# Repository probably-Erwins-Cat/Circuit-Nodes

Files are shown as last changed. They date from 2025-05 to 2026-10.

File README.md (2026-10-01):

# Circuit Nodes - Modular Electronics Building Blocks

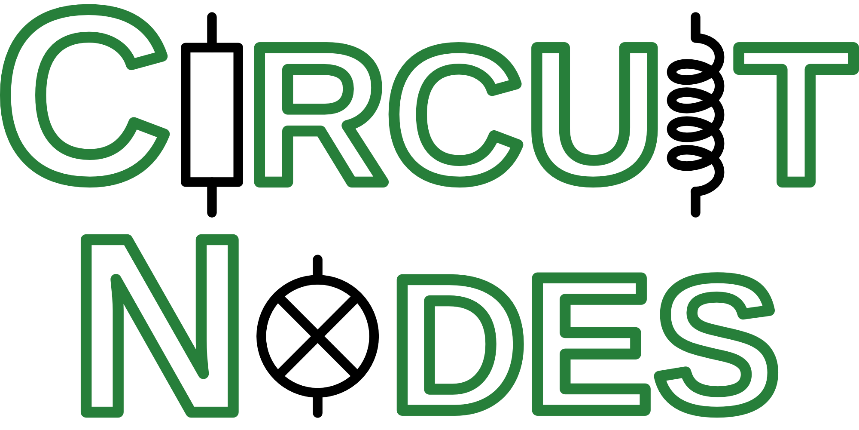
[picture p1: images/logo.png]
Circuit Diagram


Circuit Nodes is an educational tool shared under CC BY-NC-SA 4.0 to help students understand electronic circuits by physically building them.
Each module consists of a small PCB mounted on a 3D-printed base with puzzle-like notches, allowing users to create circuits in a grid-based structure. 
The PCBs include simple circuit elements such as resistors, capacitors, wire traces, switches, LEDs, lamps, and voltage or current measurement points, with their schematic representations printed directly on them. 
Magnetic connectors enable both physical attachment and electrical connection.

This system provides a low-cost entry point into electronics education while remaining scalable. 
By starting with basic components and expanding into more complex circuits, learners of all levels can benefit. 
The pedagogical value lies in reinforcing the connection between abstract circuit diagrams and tangible, working implementations, 
making theoretical concepts easier to grasp through hands-on experimentation.

---

## 📖 **[→ EXPLORE THE FULL DOCUMENTATION](https://probably-erwins-cat.github.io/Circuit-Nodes/)**

Complete guides, examples, research insights, and best practices are available in our **comprehensive GitHub Pages site**:

| Chapter | Link |
|---|---|
| **Introduction** | https://probably-erwins-cat.github.io/Circuit-Nodes/introduction |
| **Getting Started** | https://probably-erwins-cat.github.io/Circuit-Nodes/getting-started |
| **Printable Bases** | https://probably-erwins-cat.github.io/Circuit-Nodes/printable-bases |
| **Assembly Instructions** | https://probably-erwins-cat.github.io/Circuit-Nodes/assembly-instructions |
| **Component Guide** | https://probably-erwins-cat.github.io/Circuit-Nodes/component-guide |
| **Sourcing & Manufacturing** | https://probably-erwins-cat.github.io/Circuit-Nodes/sourcing-manufacturing |
| **Getting Started** | https://probably-erwins-cat.github.io/Circuit-Nodes/getting-started |

# Features

*If you are an educator or represent a school interested in testing Circuit
Nodes, I can provide kits for evaluation and classroom use. Please reach out for
more details, see below*

-   Modular Design: 40x40mm PCBs mounted on 3D-printed bases with interlocking
    puzzle-like edges.
-   Hands-on Learning: Users assemble working circuits based on schematic
    diagrams.
-   Magnetic Connectors: Ensure secure physical and electrical connections.
-   Visual Representation: Each PCB features the corresponding circuit schematic
    for intuitive learning.
-   Expandable: Additional modules with more components can be designed and
    added.
-   Low Cost & Scalable: An affordable introduction to electronics that can be
    expanded as needed.

-   Pre-Assembled Kits Available: If the initial effort of manufacturing and
    assembling the components seems too high, I can provide ready-made circuit
    kits to make getting started easier.

# Getting Started, Assembly Instructions

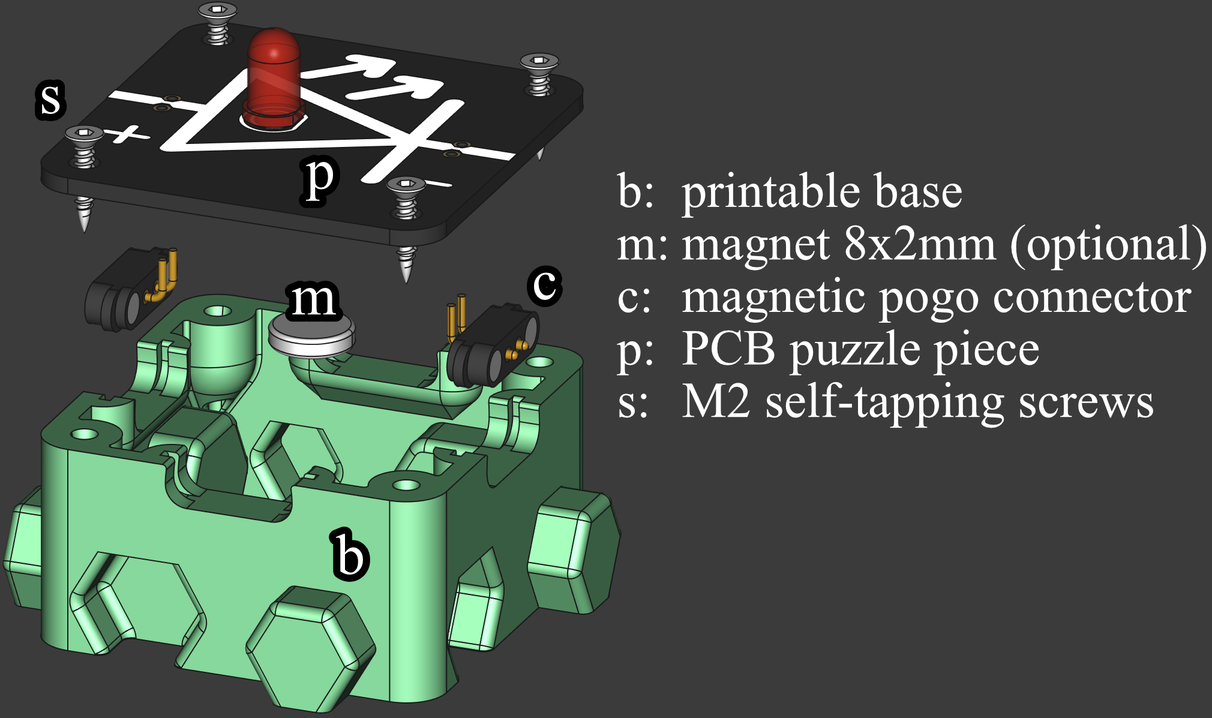
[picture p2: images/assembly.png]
assembly


- Refer to the repository contents below for a dedicated list and example circuits. 
- Plan what puzzle pieces you need and how many. An entry electronics kit for school settings needs less than 40 to cover most grounds.
- Download the necessary Gerber files for the circuits or kits you want to build from this repository.
- Manufacture the PCBs using your preferred(accessible) PCB fabrication service. 
  - Talk to the manufacturer if they can provide discounts for educational purpose. 
  - I recommend black background/solder mask and white silkscreen print. From my experience, this combination is the most durable combination.

-   **Decide which style of the 3D printable base you prefer for your scenario**:
    -  PCBs support screws of size M2, M2.3, and M2.6 self-tapping, as well as M2, M2.5 and M3 normal screws in combination with heat inserts.
        -   *Self-Tapping*: I recommend **M2 self-tapping and countersunk**
            screws. They provide the cleanest look, do not require additional
            assembly steps and auto-align the PCBs.
            Self-tapping screws, **can carve multiple threads when reinserting**, limited number of reuse of printable base.
        -   *Heat insert version*: Heat inserts provide **more durable and reliable way** for normal M2 and M2.5, 
            but requires time-consuming melting in the heat inserts with a solder iron or heat insert press.
    -   **Base Bottom Style**:
        -   The *magnetic bottom* base has highest build plate adhesion and allows for installing neodymium magnet, 
            so that the part can be attached to a magnetic surface. The internal height for components will be reduced by approx 3mm down to approx 16mm.
            **This makes a good teacher set for blackboards and whiteboards**
        -   The *skeletonized* one allows to look inside, but prevents curious
            fingers to get inside to accidentally break parts but allows exploring how
            components look in real life.
        -   The *open bottom* uses the least amount of material, is the fastest to
            print and, in case of a damaged component, the bottom side can be
            reached with a solder iron for *repair without disassembly*.            

-   **Before you go mass printing the base parts**, check which tolerance class,
    0.15mm and 0.2mm, suits your printer capabilities. 
    - The puzzle pieces should fit in together without a lot of wiggle room and without a lot of friction.
    - Smallest tolerance is preferred for best alignment of the parts.
-   Solder the component of the schematic of the PCB onto it first.
-   Assemble the puzzle pieces by placing the magnetic connectors in the pockets
    for the dedicated PCBs first. Slots without electrical connection stay     empty.
-   Place the PCB on top of the pins of the magnetic connectors and screw in
    four screws into the base. Screws should auto-center the PCB on the base.
-   Solder the magnetic connectors to the PCB.
-   Start building and experimenting with different circuit configurations!

You can also contact me for production and sale, I stock the puzzle pieces in my inventory and do quality checks including all other parts for assembly.

# Contributing

Contributions are welcome! Feel free to submit pull requests with new module
designs, improvements, or documentation updates. If you are a teacher and would
like to see specific schematics that align with your curriculum, but lack the
KiCAD skills to design them, I am happy to assist with the schematic design
process. Just reach out with your requirements, and I can help bring them to
life for your students.

Before submitting files, read [CONTRIBUTING.md](CONTRIBUTING.md). It explains
how contributed designs remain available for future Circuit Nodes kits while
contributors keep ownership of their work.

# Contact

For questions or collaboration, please open an discussion or reach out to me.

# DOI



# License

Circuit Nodes material is offered under **CC BY-NC-SA 4.0** (Creative Commons
Attribution-NonCommercial-ShareAlike 4.0 International) where the project holds
the necessary rights. You may use the design files to make your own Circuit
Nodes for noncommercial purposes. Schools may be able to commission ordinary
fabrication and assembly services for that use. The public license does not
permit use of licensed material primarily for commercial advantage. The project
creator retains the right to manufacture and sell products based on material
for which they hold the necessary rights. See
[LICENSING.md](LICENSING.md) for scope and
[LICENSE](LICENSE) for the full license.

---

## 📚 Citation & Research

This project is supported by peer-reviewed research published in **Physics Education**:

**Kubitschke, H., Hennig, F., Gleichmann, J., Schnauß, J., & Bitzenbauer, P. (2024).** 
*Modular 3D-printed Circuit Nodes for low-cost and hands-on Electricity Education.* 
Physics Education, 61(1), 015010.
**DOI**: [10.1088/1361-6552/ae1abd](https://doi.org/10.1088/1361-6552/ae1abd)

The paper includes:
- Educational design principles and cognitive load theory
- Technical specifications and cost analysis
- Teacher evaluation and feedback from 8 German secondary school physics teachers
- Learning outcome research and student perception studies

[Read the research publication](https://doi.org/10.1088/1361-6552/ae1abd) for detailed insights.

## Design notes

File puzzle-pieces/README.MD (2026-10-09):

# Circuit Nodes Puzzle Pieces

All Circuit Nodes puzzle pieces are collected and constantly updated here. Each piece represents a specific circuit component or connection type, named according to their schematic symbols rather than specific component numbers. For example, the folder for an n-channel MOSFET will contain compatible part numbers like the 2N7000.

## Design Standard

All puzzle pieces follow a consistent design template to ensure they work together seamlessly:

- **Physical dimensions**: 40×40 mm square outline with 4 mm radius corners
- **Mounting**: Four M3-compatible screw holes in the corners (2.9–3.0 mm diameter, 4 mm from edges)
- **Visual style**: 2 mm thick pictogram lines with rounded edges where possible
- **Electrical layout**: Copper pour kept at least 2 mm from board edges and not connected to GND or power supply
- **Connector interface**: Integrated magnetic pogo connectors (see the dedicated pogo-connector folder)

## Board-to-Board Connectors

All pieces are designed for integrated magnetic pogo connectors. The layout and spacing of each puzzle piece are carefully matched to these connectors for reliable, automatic alignment when pieces are joined.

## Complete Catalog

| Name | Image |
|---|---|
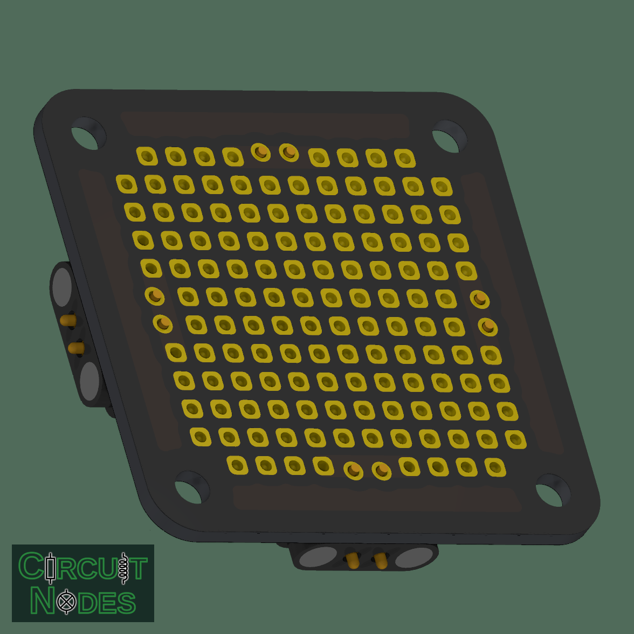
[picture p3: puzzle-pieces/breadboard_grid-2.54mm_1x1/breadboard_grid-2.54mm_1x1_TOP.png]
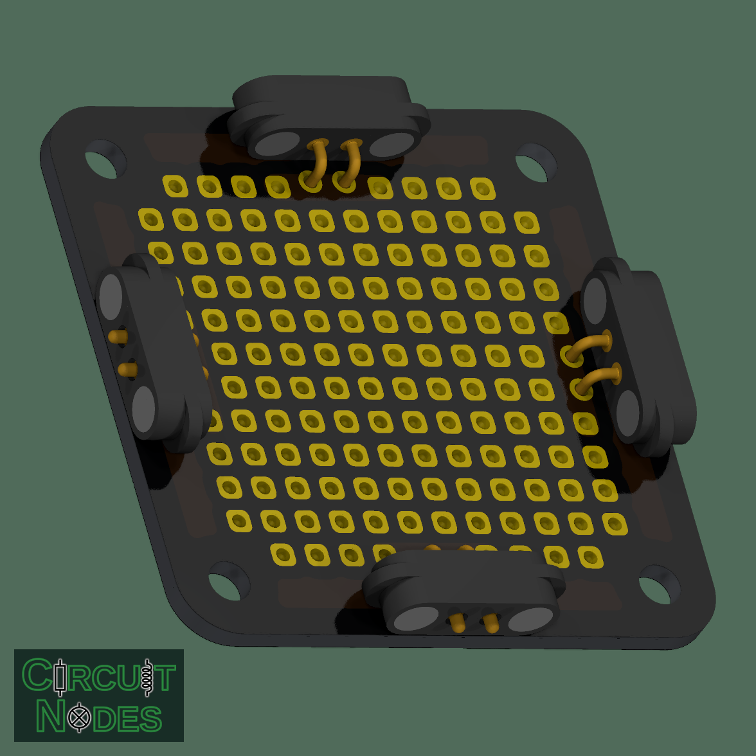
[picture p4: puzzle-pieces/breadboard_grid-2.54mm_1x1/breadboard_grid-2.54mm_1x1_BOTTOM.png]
| [breadboard_grid-2.54mm_1x1](breadboard_grid-2.54mm_1x1) |  |
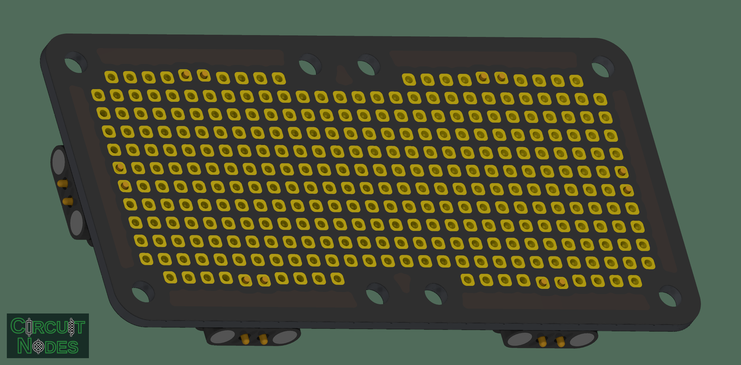
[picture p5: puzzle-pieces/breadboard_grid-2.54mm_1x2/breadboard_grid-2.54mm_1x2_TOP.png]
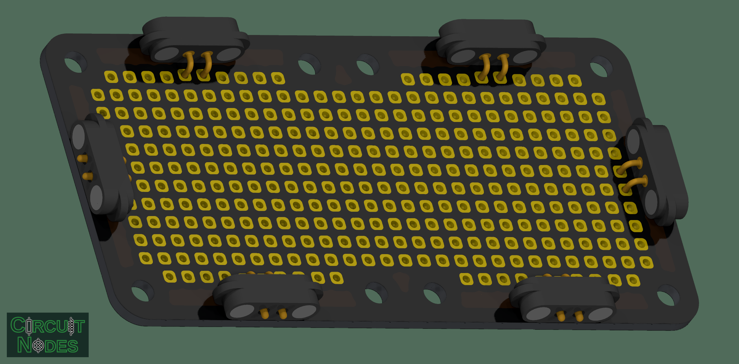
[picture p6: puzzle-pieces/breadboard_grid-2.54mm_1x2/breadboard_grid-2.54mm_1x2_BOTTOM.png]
| [breadboard_grid-2.54mm_1x2](breadboard_grid-2.54mm_1x2) |  |
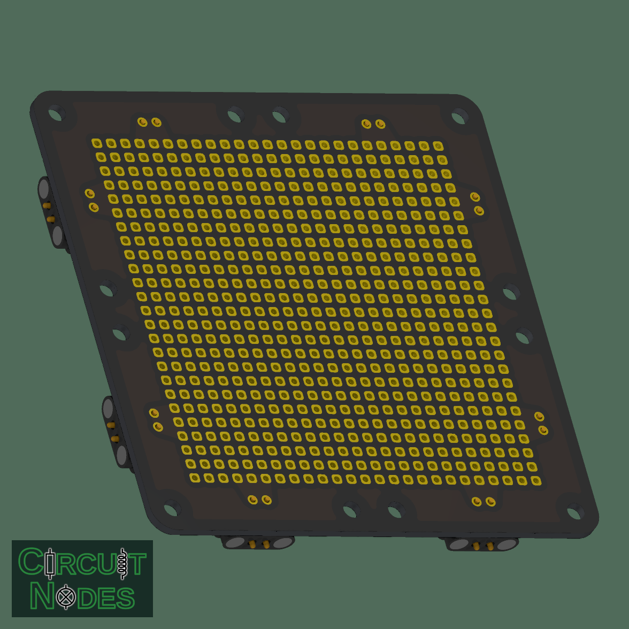
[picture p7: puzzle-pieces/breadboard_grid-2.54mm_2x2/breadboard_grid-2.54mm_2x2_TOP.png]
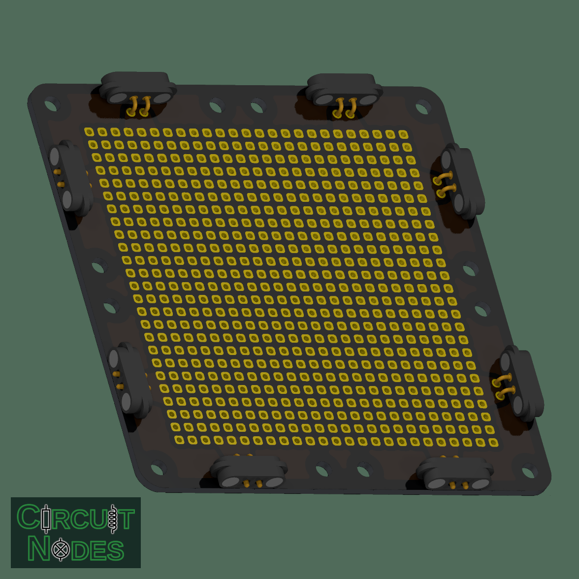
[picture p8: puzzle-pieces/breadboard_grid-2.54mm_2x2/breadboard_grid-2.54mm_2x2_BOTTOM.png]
| [breadboard_grid-2.54mm_2x2](breadboard_grid-2.54mm_2x2) |  |
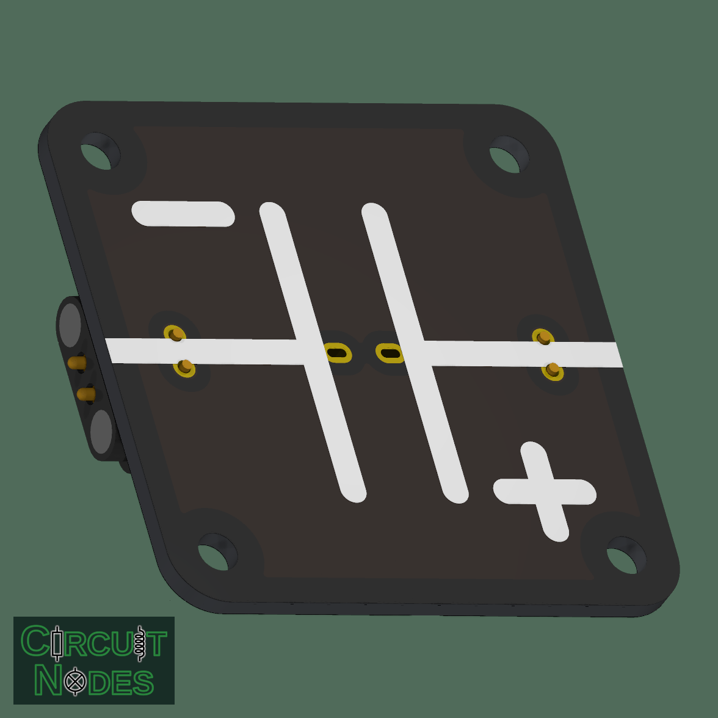
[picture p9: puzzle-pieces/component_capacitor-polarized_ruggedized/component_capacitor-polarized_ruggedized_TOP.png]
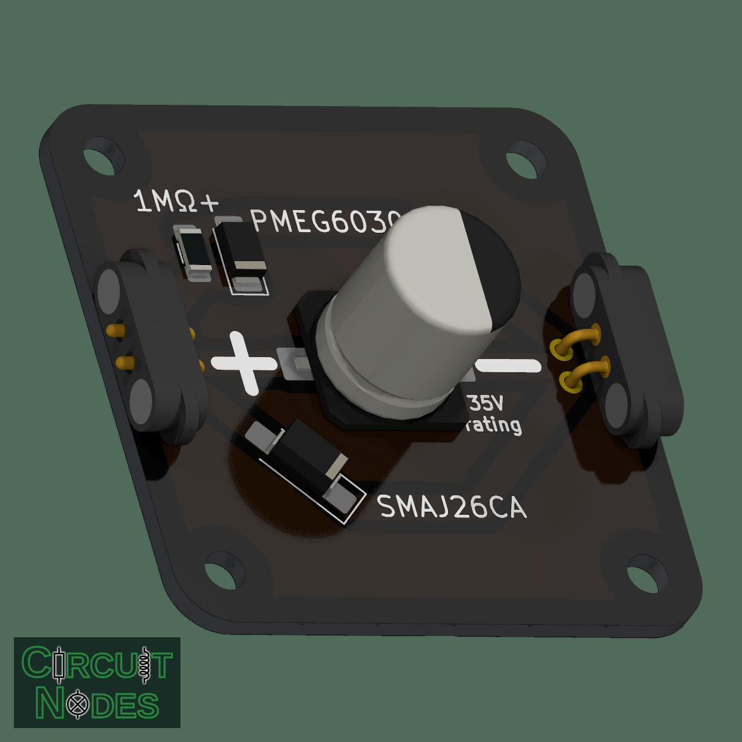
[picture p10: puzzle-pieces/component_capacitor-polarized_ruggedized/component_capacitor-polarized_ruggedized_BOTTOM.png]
| [component_capacitor-polarized_ruggedized](component_capacitor-polarized_ruggedized) |  |
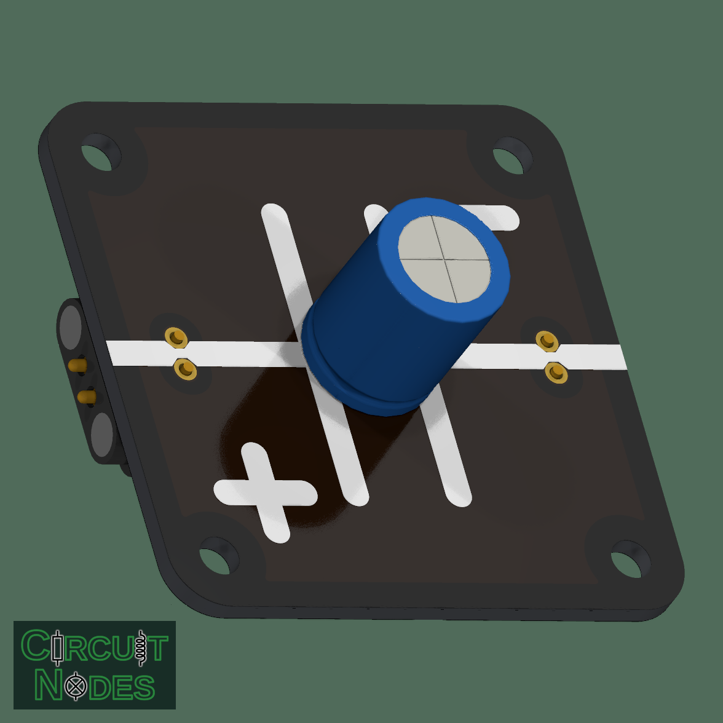
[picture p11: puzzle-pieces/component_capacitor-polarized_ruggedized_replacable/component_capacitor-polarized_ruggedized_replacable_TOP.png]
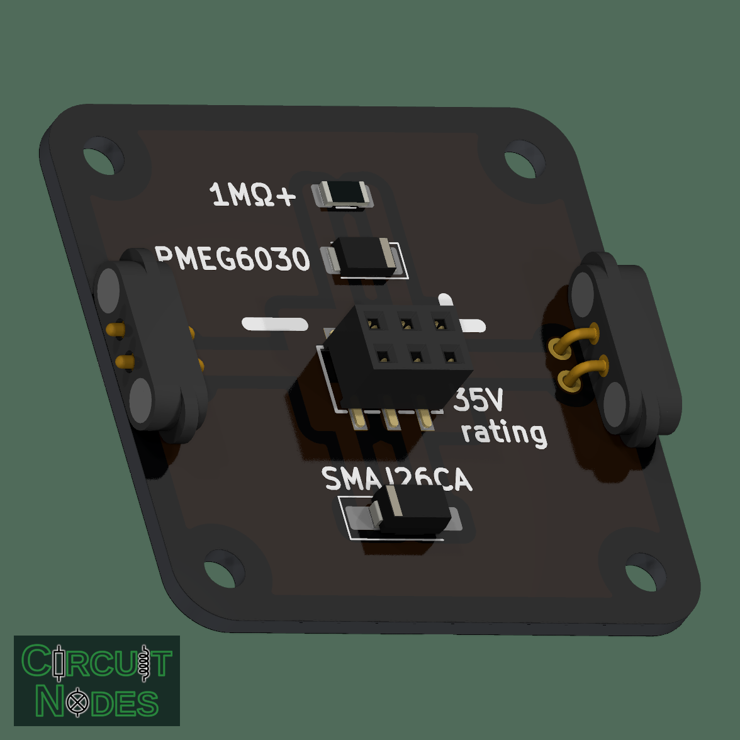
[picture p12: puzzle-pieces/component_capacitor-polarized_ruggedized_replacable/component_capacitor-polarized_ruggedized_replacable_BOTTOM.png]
| [component_capacitor-polarized_ruggedized_replacable](component_capacitor-polarized_ruggedized_replacable) |  |
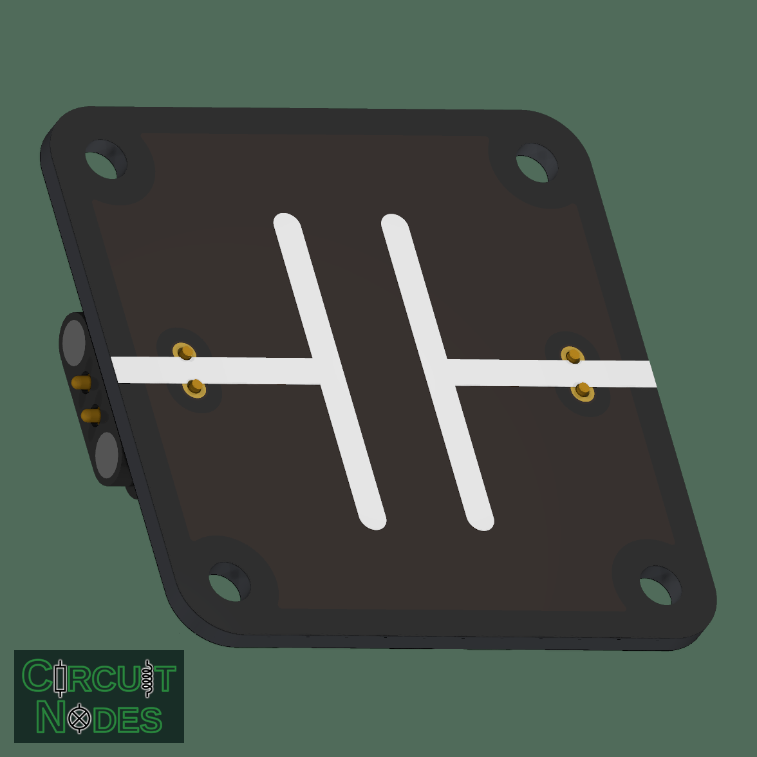
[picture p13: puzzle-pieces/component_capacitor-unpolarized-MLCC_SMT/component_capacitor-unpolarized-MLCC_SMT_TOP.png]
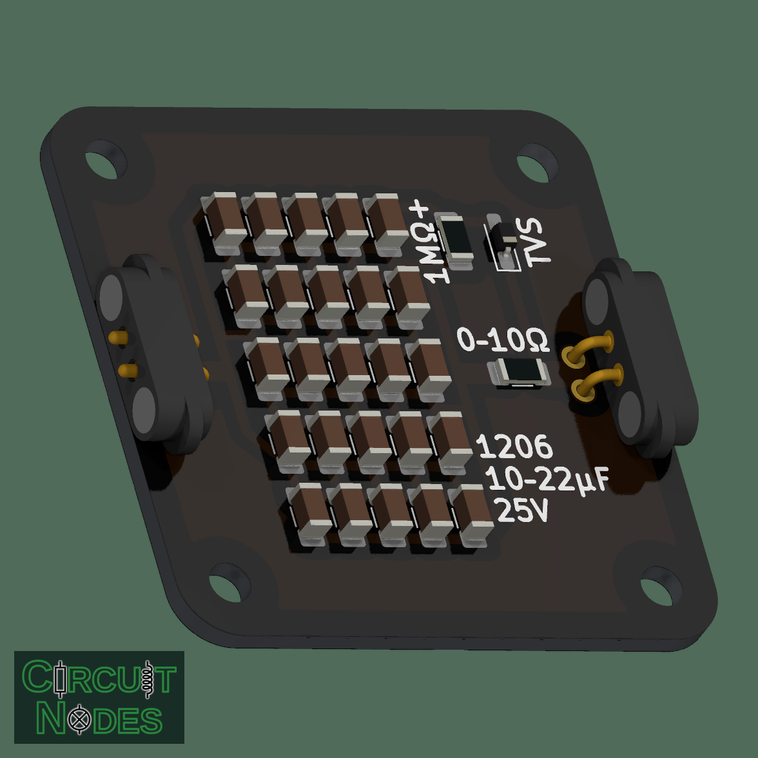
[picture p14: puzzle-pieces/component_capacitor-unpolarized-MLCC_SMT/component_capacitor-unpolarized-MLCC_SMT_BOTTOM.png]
| [component_capacitor-unpolarized-MLCC_SMT](component_capacitor-unpolarized-MLCC_SMT) |  |
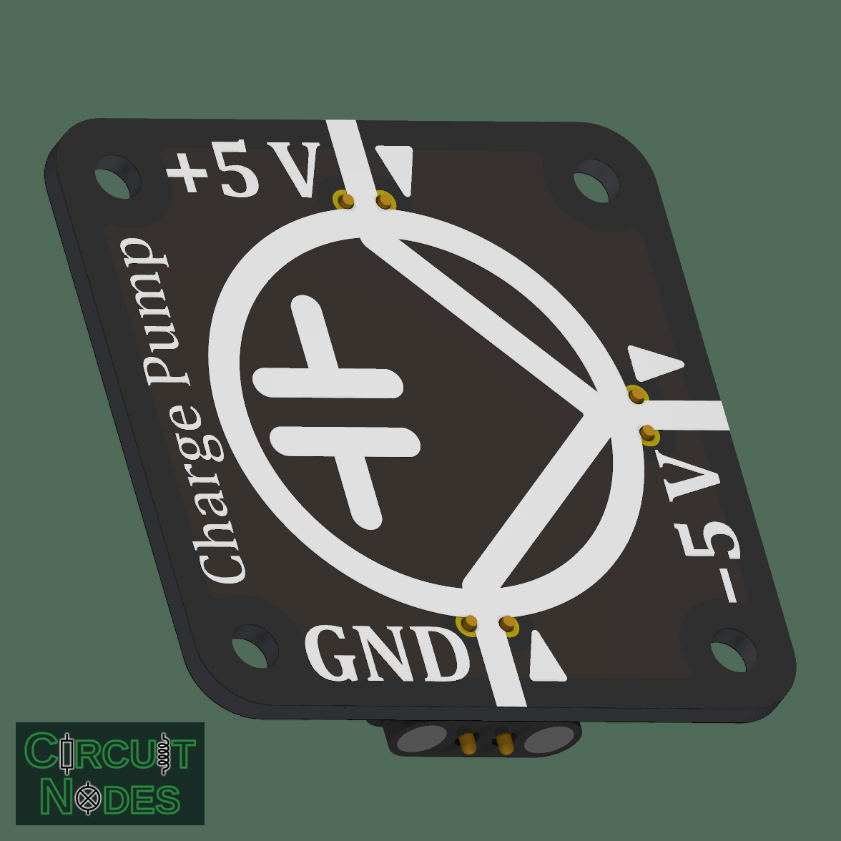
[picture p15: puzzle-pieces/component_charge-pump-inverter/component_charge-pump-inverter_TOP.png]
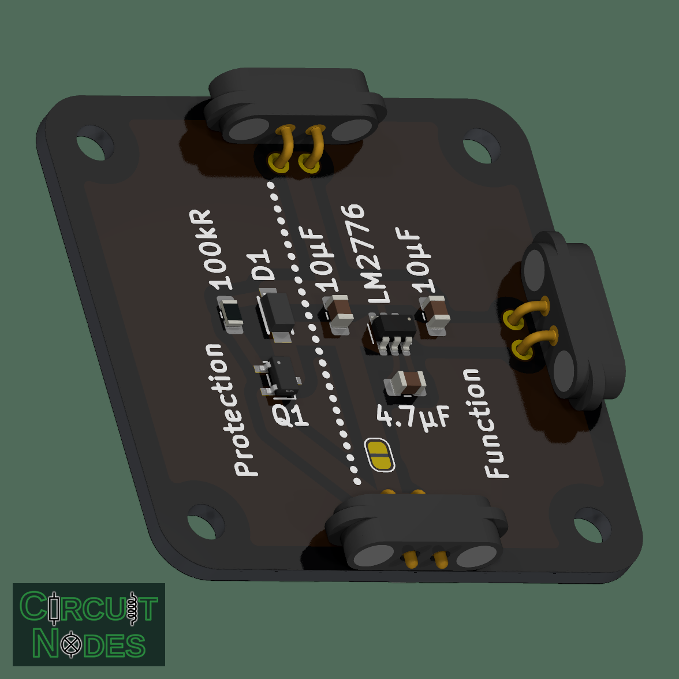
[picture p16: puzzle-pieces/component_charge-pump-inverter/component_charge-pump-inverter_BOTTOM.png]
| [component_charge-pump-inverter](component_charge-pump-inverter) |  |
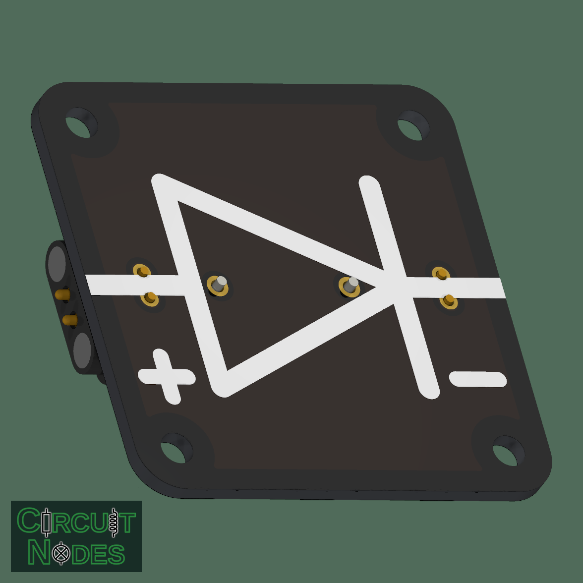
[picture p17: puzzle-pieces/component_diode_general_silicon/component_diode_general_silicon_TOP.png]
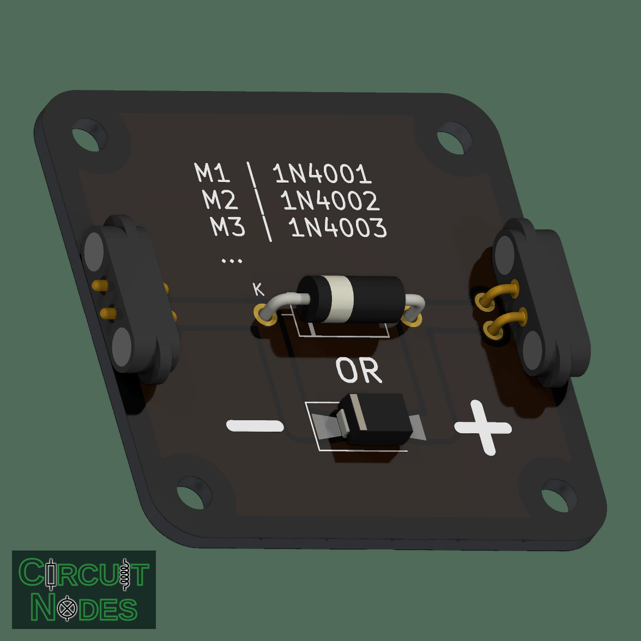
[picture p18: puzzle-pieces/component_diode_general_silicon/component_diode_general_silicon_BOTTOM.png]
| [component_diode_general_silicon](component_diode_general_silicon) |  |
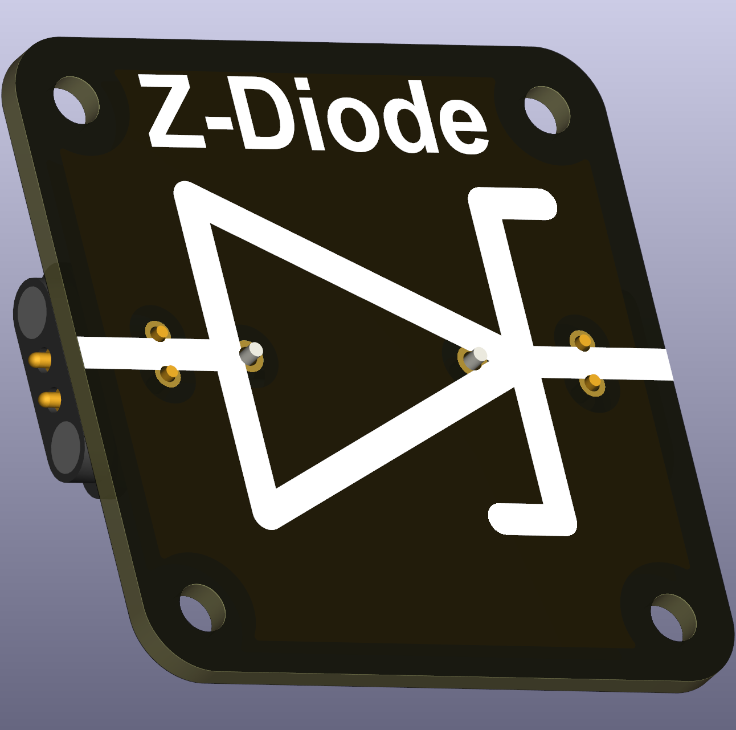
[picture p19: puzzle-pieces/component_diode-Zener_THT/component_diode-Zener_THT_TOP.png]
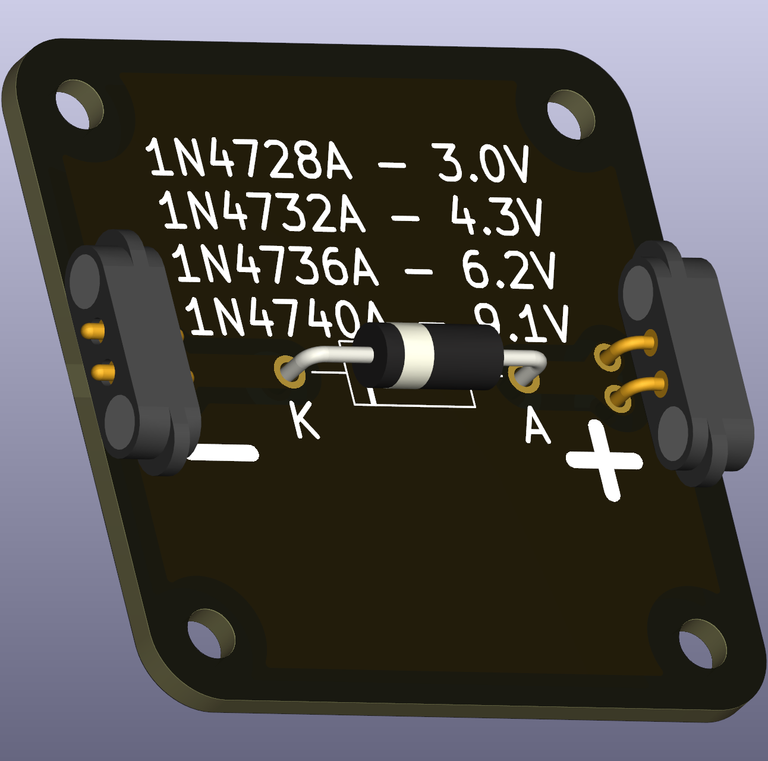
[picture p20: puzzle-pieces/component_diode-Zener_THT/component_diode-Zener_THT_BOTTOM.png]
| [component_diode-Zener_THT](component_diode-Zener_THT) |  |
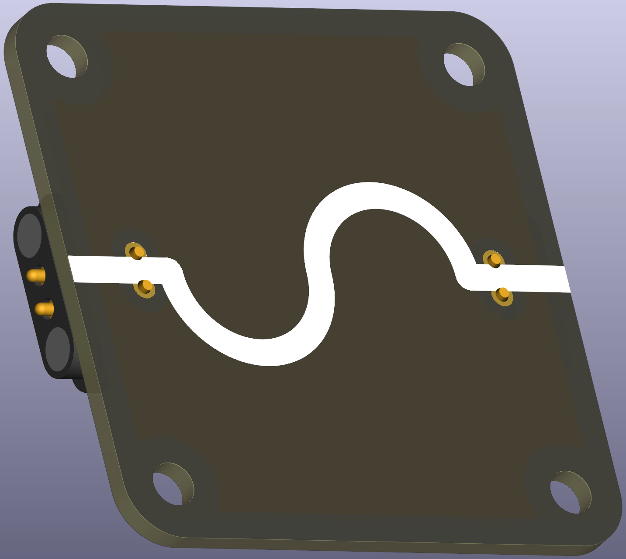
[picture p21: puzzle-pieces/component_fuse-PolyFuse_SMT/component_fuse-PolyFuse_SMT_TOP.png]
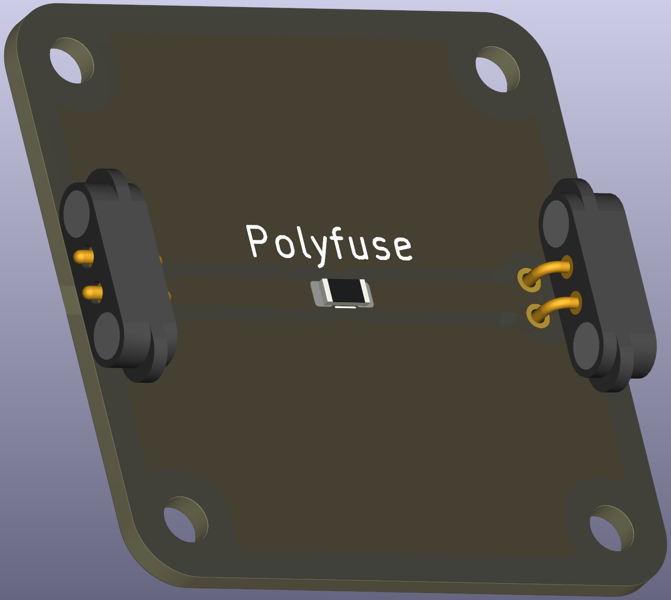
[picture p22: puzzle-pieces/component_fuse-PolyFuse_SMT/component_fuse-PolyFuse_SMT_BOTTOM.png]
| [component_fuse-PolyFuse_SMT](component_fuse-PolyFuse_SMT) |  |
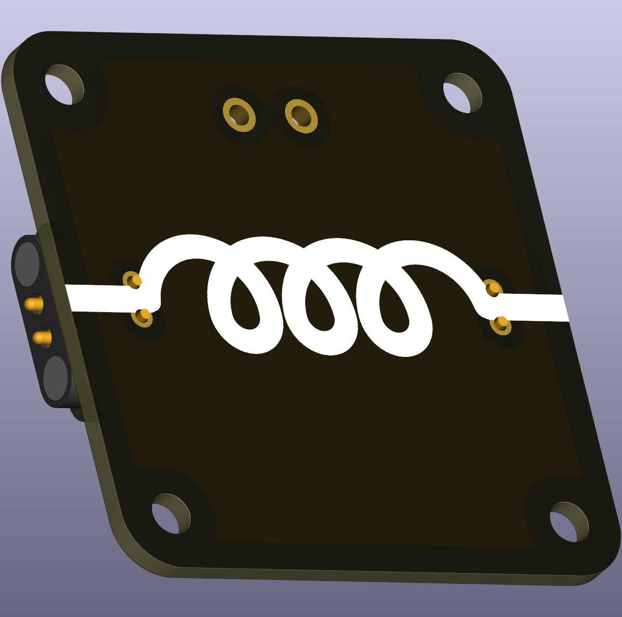
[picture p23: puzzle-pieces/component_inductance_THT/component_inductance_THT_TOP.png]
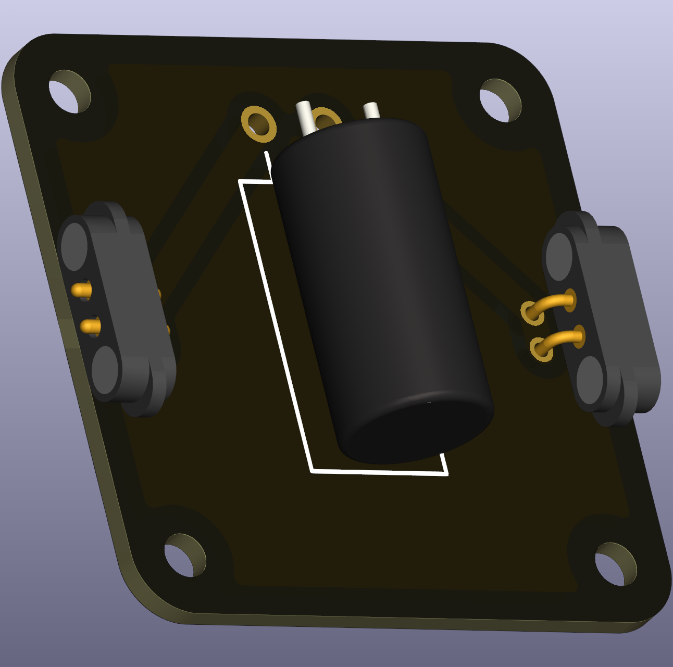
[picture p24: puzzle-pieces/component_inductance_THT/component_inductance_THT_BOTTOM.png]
| [component_inductance_THT](component_inductance_THT) |  |
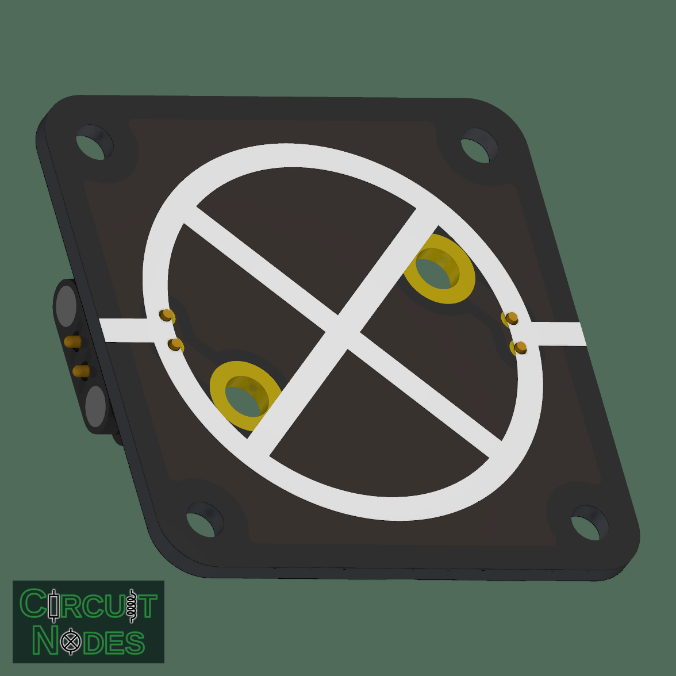
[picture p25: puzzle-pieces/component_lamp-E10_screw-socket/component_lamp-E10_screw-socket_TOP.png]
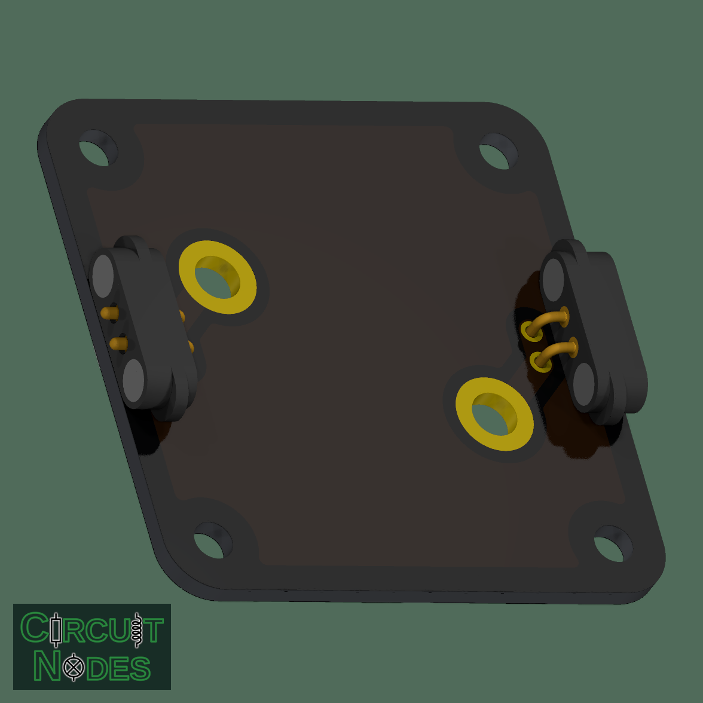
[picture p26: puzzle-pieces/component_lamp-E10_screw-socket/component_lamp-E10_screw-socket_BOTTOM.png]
| [component_lamp-E10_screw-socket](component_lamp-E10_screw-socket) |  |
| [component_lamp-E10_THT](component_lamp-E10_THT) |  |
| [component_lamp-LED-module_ruggedized](component_lamp-LED-module_ruggedized) |  |
| [component_LED_THT](component_LED_THT) |  |
| [component_LED_THT_replacable_SMT](component_LED_THT_replacable_SMT) |  |
| [component_mosfet_n-channel_ruggedized](component_mosfet_n-channel_ruggedized) |  |
| [component_mosfet_n-channel_TO-92](component_mosfet_n-channel_TO-92) |  |
| [component_motor-with-propeller](component_motor-with-propeller) |  |
| [component_NPN-BJT_TO-92](component_NPN-BJT_TO-92) |  |
| [component_potentiometer_high-power](component_potentiometer_high-power) |  |
| [component_potentiometer_slider_screw-mounted](component_potentiometer_slider_screw-mounted) |  |
| [component_potentiometer_slider_THT](component_potentiometer_slider_THT) |  |
| [component_resistor_SMT](component_resistor_SMT) |  |
| [component_resistor_SMT_top-mount](component_resistor_SMT_top-mount) |  |
| [component_resistor_SMT_with-printed-value](component_resistor_SMT_with-printed-value) |  |
| [component_resistor_THT_3W](component_resistor_THT_3W) |  |
| [component_resistor_THT_3W_with-printed-value](component_resistor_THT_3W_with-printed-value) |  |
| [component_switch-micro-Normally-Closed_THT](component_switch-micro-Normally-Closed_THT) |  |
| [component_switch-micro-Normally-Open_THT](component_switch-micro-Normally-Open_THT) |  |
| [component_switch-On1-OFF-On2_THT](component_switch-On1-OFF-On2_THT) |  |
| [component_switch-On1-On2_THT](component_switch-On1-On2_THT) |  |
| [component_switch-On-OFF_THT](component_switch-On-OFF_THT) |  |
| [component_switch-tactile-Normally-Open_THT](component_switch-tactile-Normally-Open_THT) |  |
| [end-node-double_AC](end-node-double_AC) |  |
| [end-node-double_blank](end-node-double_blank) |  |
| [end-node-double_current](end-node-double_current) |  |
| [end-node-double_plus-minus](end-node-double_plus-minus) |  |
| [end-node-double_plus-minus_with-protection](end-node-double_plus-minus_with-protection) |  |
| [end-node-double_plus-minus_with-USB-PD](end-node-double_plus-minus_with-USB-PD) |  |
| [end-node-single_blank](end-node-single_blank) |  |
| [end-node-single_minus](end-node-single_minus) |  |
| [end-node-single_plus](end-node-single_plus) |  |
| [wire-angle_blank](wire-angle_blank) |  |
| [wire-angle_node-voltage](wire-angle_node-voltage) |  |
| [wire-bridge_blank](wire-bridge_blank) |  |
| [wire-straight_blank](wire-straight_blank) |  |
| [wire-straight_node-voltage](wire-straight_node-voltage) |  |
| [wire-T-crossing_blank](wire-T-crossing_blank) |  |
| [wire-T-crossing_node-voltage](wire-T-crossing_node-voltage) |  |
| [wire-two-angles_blank](wire-two-angles_blank) |  |
| [wire-X-crossing_blank](wire-X-crossing_blank) |  |
| [wire-X-crossing_node-voltage](wire-X-crossing_node-voltage) |  |

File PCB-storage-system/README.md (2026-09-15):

# PCB Storage System

Circuit Nodes are much cheaper when ordered in bulk. Buying in bulk also means you always have replacement PCB if needed. Since there are many different Circuit Nodes, a storage and sorting bin is advisable.
Here, a parametric PCB storage system is provided. It features a storage compartment, where all unused PCBs can be stored and a window where the stored PCB is displayed. 
Further, it is stackable, for compact storing all PCBs and still having all Circuit Nodes at a glance.

Circuit Diagram

## Parametric Sizing

The CAD file harbors a set of variables, VarSet, that parametrises the whole storage system. If the here exported printable files are too small, you can easily export larger ones.
Only the variables with "int_*" in the name are of relevance for scaling the storage system. Setting "int_width" sets the number of columns. Setting "int-length" sets the length of the storage container. Setting "int_multiplier" sets the width of the to-be-stored PCBs (either 1 or 2).

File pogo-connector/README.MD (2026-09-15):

# Pogo Connector



Circuit Nodes are primarily designed with the connector in mind depicted in the [PDF](magnetic_spring_loaded_pogo_connector.pdf). It contains two spring-loaded pogo pins for secure electrical contact, two north-south oriented magnets, angled solder leads, and rounded pastic wings for alignment in the printed base. In short, it ticks all the boxes and is the prefect parts for this application. This parts comes with varying number of terminals with 2 being the version needed for *Circuit Nodes*. This part can be found on various websites, e.g. LCSC, aliexpress, and taobao, or the manufacturer, Samzo Components, can be directly contacted. Due to the current popularity, this part is sometimes out-of-stock/has an queue attached.

# Alternative Connector



There is a very similar connector that is missing the rounded plastic wings and has instead tiny corner wings. It is a fraction of a millimeter wider, so this one will fit a little tighter and might need a little bit more force to insert (or larger printable part tolerance, not recommended). It also comes with the same North-South- orientation, so it is compatible with the ideal connector.

# Other Options, not designed yet.



There are also versions for normal pogo connector in the making where the user must manually add magnets in two separate pockets. Those pogo connectors' advantage are lower price and simpler soldering when the right equipment is available (hot plate). Their downside is manual assembly and orientation of separate magnets. Since special equipment is needed (or a large order must be outsourced to become financially viable), this version is currently being evaluated before release.

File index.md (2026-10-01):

---
layout: default
title: Circuit Nodes - Modular Electronics Building Blocks
---

Circuit Diagram

Assembly Image

Circuit Nodes is a CC-licensed educational tool designed to help students understand electronic circuits by physically building them. Each module consists of a small PCB mounted on a 3D-printed base with puzzle-like notches, allowing users to create circuits in a grid-based structure.

The pedagogical value lies in reinforcing the connection between abstract circuit diagrams and tangible, working implementations, making theoretical concepts easier to grasp through hands-on experimentation.

---

# Get Started

Explore the chapters using the links below:

- **[Introduction](introduction)** – Overview and design principles
- **[Getting Started](getting-started)** – Quick start guide
- **[Printable Bases](printable-bases)** – Base styles and printing
- **[Assembly Instructions](assembly-instructions)** – Build your components
- **[Component Guide](component-guide)** – Full component catalogue
- **[Sourcing & Manufacturing](sourcing-manufacturing)** – Production and educational research

---

# Features

- **Modular Design**: 40x40mm PCBs mounted on 3D-printed bases with interlocking puzzle-like edges
- **Hands-on Learning**: Users assemble working circuits based on schematic diagrams
- **Magnetic Connectors**: Ensure secure physical and electrical connections
- **Visual Representation**: Each PCB features the corresponding circuit schematic
- **Expandable**: Additional modules can be designed and added
- **Low Cost & Scalable**: An affordable introduction to electronics

---

# Quick Links

- [GitHub Repository](https://github.com/probably-erwins-cat/Circuit-Nodes)
- [License Information](https://github.com/probably-erwins-cat/Circuit-Nodes/blob/main/LICENSING.md)
- [Contributing Guidelines](https://github.com/probably-erwins-cat/Circuit-Nodes/blob/main/CONTRIBUTING.md)
- [Contact & Support](#contact)

---

# Contact

For questions or collaboration, please open a discussion in the repository or reach out directly.



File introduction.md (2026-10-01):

---
layout: default
title: Introduction to Circuit Nodes
---

# Introduction

Circuit Nodes

Teaching electric curcuits is a challenging task. Of the various physics subjects, this is  the first physics subject which cannot easily be experience with our senses in a satisfying way and teachers heavy rely on proxies for electricity, e.g. a lamp that "magically" is light up.

For an enjoyable learning environment, hands-on experiments and experience are vital, however, electric circuits are not without danger, thus, properly designed teaching material is required.

## Why Circuit Nodes?

Consider the typically schematic or circuit diagram. All typical electronic components have a dedicated symbol that represents them in a diagram, see below. One can quickly grasp the intent of the diagram.

Typical schematic diagram

Unfortunately, this is typically *not* the way how such an electric circuit is build in real life. A student might build a well-structured circuit on a breadboard, see below, but experience tells that this is rarely the case. First-hand experience with electronic circuits on breadboard level is oftentimes... *less structured* (*if* sucessful at all...).

Ideal Breadboard Wiring

*Circuit Nodes* is a 3D-printed modular system for teaching electric circuits
in schools. Its designs are shared for noncommercial use under
[CC BY-NC-SA 4.0](https://github.com/probably-erwins-cat/Circuit-Nodes/blob/main/LICENSING.md).

Secondary‑school students learn best when the tools they use resemble the
textbook diagrams they are taught. Conventional kits (breadboards, loose
wires) force pupils to translate between two very different representations;
this translation is a major source of persistent misconceptions about current,
voltage and circuit behaviour.

The upper circuit can be segmented in functional parts on a grid, providing a puzzle-like system with repeating elements, the origin of the *Circuit Nodes*. Only eigth unique elements construct the upper circuit, where every single element is simple to grasp.

Typical schematic diagram

*Circuit Nodes* remove the translation and representation barrier. Each puzzle piece *is* its schematic
symbol, and modules snap together on a square grid. Magnets and geometry make
incorrect wiring virtually impossible, so students (and teachers alike) can concentrate on the physics. 

The system can be summarised as
inexpensive, easy to adapt to lesson plans and effective at reducing abstraction.

The idea and evaluation is further outline in a peer‑reviewed
paper: **"Modular 3D‑printed Circuit Nodes for low‑cost and hands‑on Electricity
Education"** (Phys. Educ. 61 015010, 2024, [DOI 10.1088/1361-6552/ae1abd](https://doi.org/10.1088/1361-6552/ae1abd)).

## Practical Examples

Here are some examples of *Circuit Nodes*, ranging from basic banana terminals for voltage and current supply and measurement,

Various node modules

over to wire segments and junctions,

Wire segment examples

ending with functional elements, like switches, lamps, LEDs, capacitors, and advanced components,

Functional node set

Worth noting, many sensitive and advanced components also come as "ruggedized" versions, where additional protective circuit elements are added, hidden on the underside of the board, enabling students to explore those components without the risk of causing damage to them (and subsequently time investment to repair those again).

Circuit protection example

## What’s in this repository?

All files and informations are provided in this repository for building your own *Circuit Nodes*:

- Schematics and Gerber files for every PCB module.
- FreeCAD models plus STL/STEP exports for the 3‑D printed bases.
- Assembly instructions, example circuits and documentation.
- A bill‑of‑materials and production notes for magnets, screws, and components
- Source images such as `assembly.png` used throughout the docs.

Assembly overview

---

**Ready to get started?** → [Getting Started Guide](getting-started)

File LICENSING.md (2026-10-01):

# Licensing and manufacturing

The project design files, documentation, and images are offered under
[Creative Commons Attribution-NonCommercial-ShareAlike 4.0 International](LICENSE)
(CC BY-NC-SA 4.0), to the extent the project can license rights in them. You may
use the files to make your own Circuit Nodes, including ordering PCBs and printing
bases, for noncommercial purposes. You may share and adapt the licensed material
under the license's attribution and ShareAlike conditions. The license does not
give the public permission to use the licensed material primarily for commercial
advantage or monetary compensation. For uses outside the public license, ask the
relevant rights holder(s) for separate permission.

A school or student may be able to commission ordinary PCB fabrication, 3D
printing, or assembly to carry out a permitted noncommercial educational use.
A service provider's fee or profit does not, by itself, settle whether the use
is commercial. By contrast, a business independently producing, stocking,
advertising, or selling Circuit Nodes kits for its own customers should not assume that the
school's noncommercial permission covers its business. The distinction depends
on who directs the work and its purpose, not merely on whether an invoice says
"materials" or "assembly service." These examples explain the existing CC
license; they do not add restrictions to or change its terms.

The project creator retains the right to manufacture and sell products based
on work for which they hold the necessary rights, independently of the public
license. The public license is a grant to others, not a restriction on the
rights holder's own use. Contributions and third-party material are different:
the creator needs the necessary permissions from their rights holders to include
them in manufactured kits. See [CONTRIBUTING.md](CONTRIBUTING.md) for the
project-continuity permission requested for future submissions.

The CC license does not grant patent or trademark rights. The Circuit Nodes
name and logos identify the project; no trademark permission or endorsement is
granted by the CC license. This statement does not withdraw any permission
already granted for copyrighted material in earlier published versions.

The project cannot grant rights that belong to someone else. Check the source
and permissions for third-party artwork, CAD models, and other included
material before using it.

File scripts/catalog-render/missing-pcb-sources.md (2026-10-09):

# Puzzle pieces without PCB sources

These 34 immediate `puzzle-pieces` folders had `_TOP.png` and `_BOTTOM.png`
images but no `.kicad_pcb` file during the October 2026 catalog migration. Their
existing images were left unchanged. Add the matching PCB sources before asking
the renderer to replace them.

## Components (15)

- `component_diode-Zener_THT`
- `component_fuse-PolyFuse_SMT`
- `component_inductance_THT`
- `component_lamp-E10_THT`
- `component_LED_THT`
- `component_LED_THT_replacable_SMT`
- `component_mosfet_n-channel_TO-92`
- `component_NPN-BJT_TO-92`
- `component_resistor_SMT`
- `component_resistor_THT_3W`
- `component_switch-micro-Normally-Closed_THT`
- `component_switch-micro-Normally-Open_THT`
- `component_switch-On-OFF_THT`
- `component_switch-On1-OFF-On2_THT`
- `component_switch-On1-On2_THT`

## End nodes (9)

- `end-node-double_AC`
- `end-node-double_blank`
- `end-node-double_current`
- `end-node-double_plus-minus`
- `end-node-double_plus-minus_with-protection`
- `end-node-double_plus-minus_with-USB-PD`
- `end-node-single_blank`
- `end-node-single_minus`
- `end-node-single_plus`

## Wires (10)

- `wire-angle_blank`
- `wire-angle_node-voltage`
- `wire-bridge_blank`
- `wire-straight_blank`
- `wire-straight_node-voltage`
- `wire-T-crossing_blank`
- `wire-T-crossing_node-voltage`
- `wire-two-angles_blank`
- `wire-X-crossing_blank`
- `wire-X-crossing_node-voltage`

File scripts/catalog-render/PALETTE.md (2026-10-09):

# Catalog palette

`style.json` is the authoritative, machine-readable palette for all catalog
renders. The existing MLCC capacitor and breadboard previews provide visual
references for the shared appearance. No previous chat is needed.

| Element | Style key | Color |
| --- | --- | --- |
| Solder mask, both faces | `board.solder_mask_hex_rgba` | `#000000B3` — black, approximately 70% opacity |
| PCB substrate, all dielectric layers | `board.substrate_hex_rgba` | `#454950FF` — opaque dark gray |
| Silkscreen, both faces | `board.silkscreen_hex_rgba` | `#FFFFFFFF` — opaque white |
| Image background | `image.background_hex` | `#506B5A` — muted green |
| Logo badge | `branding.badge_color_hex` | `#182D26` — dark green |

These are material/input colors, not sampled final pixel colors: lighting,
copper under the translucent mask, and shadows affect the visible result.
Components retain their model colors, including metal contacts and capacitor
bodies. Do not recolor the PCB to match a source file's manufacturing color.

The `Circuit Nodes catalog` layer preset in `kicad-viewer.json` explicitly
enables copper on both faces, mask, silkscreen, board body, and component models.
The renderer selects this preset instead of KiCad's default
`follow_plot_settings`, which can hide copper according to a board's fabrication
plot selection. Copper must remain subtly visible through the black mask where
present. Compare both faces with the published ruggedized capacitor and MLCC
references before publishing; reject a flat, copper-free appearance when the
source has copper pours or tracks. Do not change source plot selections to fix
a preview.

The preset must also contain explicit material colors. KiCad substitutes black
for missing preset color entries; an empty `colors` list is not a safe way to
inherit defaults. `kicad-viewer.json` defines gray solder paste (128/128/128),
silver plated material (194/194/194), and gold bare copper (191/156/59).
Inspect exposed solder areas as well as copper visibility before publishing.
The renderer rejects missing or black metallic material entries.

The renderer normalizes solder mask, silkscreen, and dielectric colors in an
ignored board copy, inserting missing color entries when needed. It explicitly
enables KiCad stackup colors. Source PCB files remain unchanged.

Keep the camera, lighting, canvas sizing, and branding settings in `style.json`.
All source-board models must remain visible, including alternative assembly parts.
Explain either/or assembly in bold README text. Per-board framing adjustments are allowed; color variation
is not. Inspect both faces against the established references before publishing.
Any future palette change should be a deliberate catalog-wide migration.

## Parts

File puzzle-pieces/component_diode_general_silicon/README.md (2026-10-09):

# General-purpose silicon diode (THT or SMT)

This node demonstrates one-way conduction, rectification, and the forward voltage of a standard silicon diode. Fit an axial THT diode or an SMT diode on the same board.

Silicon diode diagram face Silicon diode component face showing THT and SMT assembly options

## Parts and assembly

The silkscreen lists **M1 / 1N4001**, **M2 / 1N4002**, and **M3 / 1N4003**, followed by an ellipsis for the remaining family members.

| SMT / THT pair | Maximum repetitive reverse voltage |
| --- | --- |
| M1 / 1N4001 | 50 V |
| M2 / 1N4002 | 100 V |
| M3 / 1N4003 | 200 V |
| M4 / 1N4004 | 400 V |
| M5 / 1N4005 | 600 V |
| M6 / 1N4006 | 800 V |
| M7 / 1N4007 | 1,000 V |

These are nominally 1 A standard silicon rectifiers; allowable continuous current.

**Populate either THT or SMT, not both**, as indicated by the printed **OR**. The footprints are connected in parallel. Match the diode's cathode band to **K**; the other terminal is **A**, the anode.

- **SMT:** the board uses `D_SMA-SMB_Universal_Handsoldering`. Select M1–M7 parts in SMA / DO-214AC and verify their recommended land pattern against the universal pads.
- **THT:** 1N4001–1N4007 parts are normally axial DO-41. This PCB uses the larger `D_DO-15_P12.70mm_Horizontal` footprint for enough headroom.

**M7 / 1N4007** is a convenient default pair. M1 / 1N4001 already provides reverse-voltage headroom for 20 V experiments. The catalog component-face image shows both assembly options using the footprints' generic models; fit only one diode on the physical board.

## Teaching the forward-voltage drop

A standard silicon diode typically drops **approximately 0.7 V at modest forward current**. This is a useful classroom approximation, not a fixed threshold.

Connect several diode nodes in series to show that their forward drops add. At approximately the same current, one, two, and three diodes may produce roughly **0.7 V, 1.4 V, and 2.1 V**. Use a current-limited source or adjust the external series resistor to keep the comparison current approximately constant.

## Typical uses in circuits

- Demonstrate one-way conduction and series forward-voltage drops.
- Rectify slow AC signals, including half-wave and bridge-rectifier experiments.
- Demonstrate signal steering and series reverse-polarity protection.

## Operating notes

The diode **does not** limit current by itself. Where an external resistor sets the current, use `R = (V_supply − sum(V_forward)) / I_desired` and choose an adequate resistor power rating.

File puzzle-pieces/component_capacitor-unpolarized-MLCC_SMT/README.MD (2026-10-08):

# Unpolarized capacitor (MLCC SMT)

This node uses parallel multilayer ceramic capacitors (MLCCs) for charge storage, filtering, and RC or "slow AC" experiments. Either terminal can be positive.

Unpolarized MLCC capacitor diagram face Unpolarized MLCC capacitor component face

## Capacitance and assembly

The silkscreen specifies **1206, 10–22 µF, 25 V** capacitors. There are 25 parallel positions; populate fewer positions if less capacitance is needed. Empty capacitor positions require no bridges.
The footprints allow hand soldering, but a stencil and reflow process make a fully populated bank much easier to assemble. Fewer populated positions also reduce manual work.

| Population | Nominal total capacitance |
| --- | --- |
| 25 × 10 µF | 250 µF |
| 25 × 22 µF | 550 µF |

## Series resistor: 0–10 Ω

R1 is marked **0–10 Ω**. **10 Ω is the default** to limit connection and charging-current peaks. This resistor does not provide complete fault protection, only current limiting

Fit a **0 Ω link** when bypassing the resistor is appropriate for the experiment, with current limiting provided elsewhere. Leaving R1 unpopulated disconnects the capacitor bank.

For the nominal 550 µF bank, capacitive reactance is approximately 300 Ω at 1 Hz and 3 kΩ at 0.1 Hz. A 10 Ω series resistor therefore has little influence on slow sinusoidal experiments. Abrupt square-wave transitions can still cause current peaks.

## Bleeder resistor: 1 MΩ or greater

R2 is marked **1 MΩ+**, meaning a bleeder resistance of **1 MΩ or greater**. 

Choose the fitted resistance to balance discharge time against loading of the experiment. With the nominal 550 µF bank, the resistor-only time constant `τ = RC` is about **550 seconds at 1 MΩ** or **5,500 seconds at 10 MΩ**. These are gradual discharge paths, not immediate discharge. The capacitors and TVS have also tiny internal leaking paths, so the effective bleed resistance is likely approx. 0.5–2 MΩ.

## Transient protection and operating notes

D1, marked **TVS**, is the bidirectional ESD protection device , e.g. Nexperia **PESD1IVN24-A**. It suppresses brief transients; it is not a regulator or protection against sustained overvoltage.

Use voltages within the ratings of the fitted parts and limit source current. Disconnect the supply and check the terminal voltage before changing connections or handling the board. Avoid shorting the charged bank.

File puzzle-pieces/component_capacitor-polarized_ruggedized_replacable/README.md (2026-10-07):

# Polarized capacitor (ruggedized, replaceable THT)

This 40 x 40 mm module supports classroom experiments with charge storage, supply smoothing, and RC circuits. Optional reverse-polarity and transient-voltage protection, plus a discharge resistor, make it more tolerant of wiring mistakes. Use a suitably rated capacitor and a current-limited supply.

Ruggedized polarized capacitor diagram face with plug-in THT capacitor Ruggedized polarized capacitor component face with SMT socket and protection components

## Circuit and assembly options

The capacitor and optional protection/discharge parts share the same positive and negative terminals.

| Reference | Part or footprint | Function |
| --- | --- | --- |
| J2 | Female pin header, surface-mounted | Socket for a radial THT capacitor with 5 mm lead spacing |
| D1 | SMAJ26CA, SMA | Bidirectional TVS diode for transient-voltage suppression |
| D2 | PMEG6030, SOD-128 | Schottky diode across the terminals to limit reverse voltage |
| R1 | 1 MΩ, 1206 | Bleeder resistor to discharge the capacitor after disconnection |

The diagram-face image shows the radial THT capacitor; the component-face image shows J2 and the protection parts. Choose capacitance for the intended experiment and check that the capacitor fits inside the base.

**Every protection/discharge component is independently optional.** Fit any combination of D1, D2, and R1, or omit all three for a plain capacitor module. These parallel branches need no bridges or jumpers when omitted.

- **D1:** suppresses short voltage transients, but not sustained overvoltage.
- **D2:** conducts during reversed connection to limit reverse voltage. It does not disconnect the supply; upstream current limiting is required.
- **R1:** gradually drains residual charge. It does not limit short-circuit current or discharge the capacitor immediately.

## Replaceable THT capacitor

A radial THT capacitor with **5 mm lead spacing** plugs into the female pin header, allowing different capacitances to be tried without desoldering. This is a makeshift socket solution: check that the leads fit securely and follow the printed polarity markings each time. Disconnect the supply and verify that the capacitor is discharged before swapping it.

Replaceability applies to the plugged-in **THT capacitor**. The SMT header remains soldered to the PCB; a directly soldered SMT capacitor is not replaceable by unplugging.

## Typical uses and teaching notes

- Demonstrate capacitor charging and discharging in an RC circuit.
- Smooth supply ripple or provide local energy storage in a DC circuit.
- Compare this module with and without its optional protection/discharge components.

With R1 fitted and no other load, the nominal discharge time constant is `1 MΩ × C`. External resistors and the voltmeter shorten it. For measurements of slow discharge or capacitor leakage, consider omitting the optional components.

## Choosing a capacitor for teaching

**35 V-rated capacitors are recommended** with the named SMAJ26CA and PMEG6030 diodes, operated within their ratings. This is a capacitor rating, not a recommended supply voltage: keep normal operation below the TVS's 26 V standoff voltage. Its specified peak-pulse clamp voltage is approximately 42.1 V, so it does not guarantee that every transient stays below 35 V.

For an initial RC experiment, consider **220 µF at a 5 V supply**, with an
external **47 kΩ discharge resistor**. This gives roughly a 10-second time
constant, allowing several readings with a basic multimeter.

For slow discharge measurements, choose a **low-leakage electrolytic capacitor**. Leakage comparable to the discharge current makes the measured curve depart from an ideal RC exponential.

### Time constant and measurement

For an ideal discharge, `τ = R_eff C` and `V(t) = V₀ exp(−t/τ)`. After one
time constant the voltage is about 37% of its initial value. Aim for roughly **5–20 seconds per time constant**
for readings taken by hand with an inexpensive multimeter.

When fitted, the module's 1 MΩ bleeder and a voltmeter both load the capacitor:

`R_eff = 1 / (1/R_ext + 1/(1 MΩ) + 1/R_meter)`

If R1 is omitted, omit the `1/(1 MΩ)` term. Diode leakage can also affect slow discharge measurements when D1 or D2 is fitted.

## Operating limits

- Follow the printed + and − markings, even when D2 is fitted.
- Use a current-limited supply or upstream overcurrent protection.
- Avoid shorting a charged capacitor. R1 drains charge gradually; check the terminal voltage before handling or changing components.

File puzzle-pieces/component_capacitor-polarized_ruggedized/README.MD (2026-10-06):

# Polarized capacitor (ruggedized)

This 40 x 40 mm module supports classroom experiments with charge storage, supply smoothing, and RC circuits. Optional reverse-polarity and transient-voltage protection, plus a discharge resistor, make it more tolerant of wiring mistakes. Use a suitably rated capacitor and a current-limited supply.

Ruggedized polarized capacitor diagram face Ruggedized polarized capacitor component face, SMD assembly option

## Circuit and assembly options

The capacitor and optional protection/discharge parts share the same positive and negative terminals.

| Reference | Part or footprint | Function |
| --- | --- | --- |
| C1 | Radial THT capacitor, 8 mm body, slotted holes for 3.5 mm or 5 mm lead spacing | THT assembly option |
| C2 | SMD electrolytic capacitor, 10 x 12.5 mm footprint | SMD assembly option |
| D1 | SMAJ26CA, SMA | Bidirectional TVS diode for transient-voltage suppression |
| D2 | PMEG6030, SOD-128 | Schottky diode across the terminals to limit reverse voltage |
| R1 | 1 MΩ, 1206 | Bleeder resistor to discharge the capacitor after disconnection |

**Fit either a THT or SMD capacitor, never both:** their footprints overlap. The component-face image shows the SMD option. Choose capacitance for the intended experiment and check that the capacitor fits inside the base.

**Every protection/discharge component is independently optional.** Fit any combination of D1, D2, and R1, or omit all three for a plain capacitor module. These parallel branches need no bridges or jumpers when omitted.

- **D1:** suppresses short voltage transients, but not sustained overvoltage.
- **D2:** conducts during reversed connection to limit reverse voltage. It does not disconnect the supply; upstream current limiting is required.
- **R1:** gradually drains residual charge. It does not limit short-circuit current or discharge the capacitor immediately.

## Typical uses and teaching notes

- Demonstrate capacitor charging and discharging in an RC circuit.
- Smooth supply ripple or provide local energy storage in a DC circuit.
- Compare this module with and without its optional protection/discharge components.

With R1 fitted and no other load, the nominal discharge time constant is `1 MΩ × C`. External resistors and the voltmeter shorten it. For measurements of slow discharge or capacitor leakage, consider omitting the optional components.

## Choosing a capacitor for teaching

**35 V-rated capacitors are recommended** with the named SMAJ26CA and PMEG6030 diodes, operated within their ratings. This is a capacitor rating, not a recommended supply voltage: keep normal operation below the TVS's 26 V standoff voltage. Its specified peak-pulse clamp voltage is approximately 42.1 V, so it does not guarantee that every transient stays below 35 V.

For an initial RC experiment, consider **220 µF at a 5 V supply**, with an
external **47 kΩ discharge resistor**. This gives roughly a 10-second time
constant, allowing several readings with a basic multimeter.

For slow discharge measurements, choose a **low-leakage electrolytic capacitor**. Leakage comparable to the discharge current makes the measured curve depart from an ideal RC exponential.

### Time constant and measurement

For an ideal discharge, `τ = R_eff C` and `V(t) = V₀ exp(−t/τ)`. After one
time constant the voltage is about 37% of its initial value. Aim for roughly **5–20 seconds per time constant**
for readings taken by hand with an inexpensive multimeter.

When fitted, the module's 1 MΩ bleeder and a voltmeter both load the capacitor:

`R_eff = 1 / (1/R_ext + 1/(1 MΩ) + 1/R_meter)`

If R1 is omitted, omit the `1/(1 MΩ)` term. Diode leakage can also affect slow discharge measurements when D1 or D2 is fitted.

## Operating limits

- Follow the printed + and − markings, even when D2 is fitted.
- Use a current-limited supply or upstream overcurrent protection.
- Avoid shorting a charged capacitor. R1 drains charge gradually; check the terminal voltage before handling or changing components.

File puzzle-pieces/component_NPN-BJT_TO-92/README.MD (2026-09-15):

# NPN Bipolar Junction Transistor (TO-92)

An NPN BJT controls a larger current using a smaller base current and is commonly used in switching and low-power amplification tasks. It is a useful device to teach the difference between current-driven and voltage-driven control.

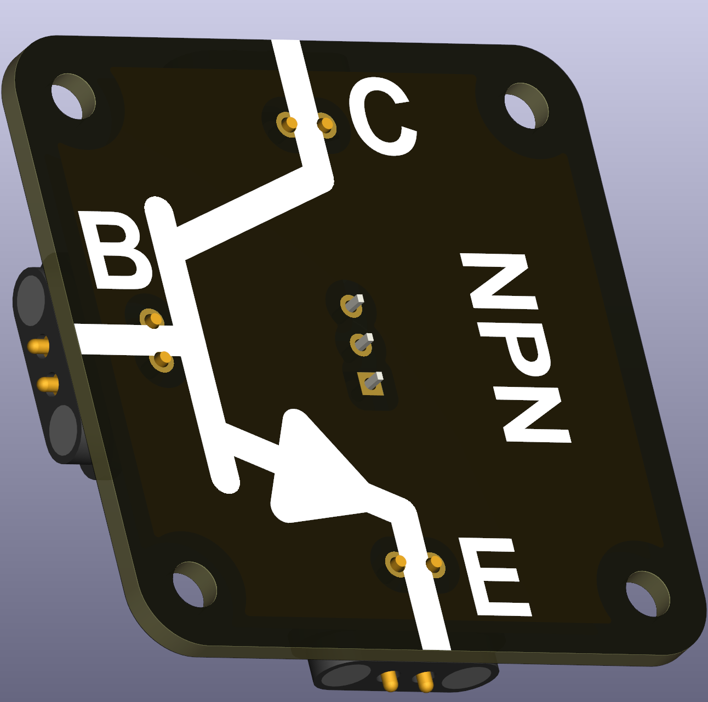
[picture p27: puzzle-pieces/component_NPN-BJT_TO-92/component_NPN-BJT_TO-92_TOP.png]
NPN BJT top view
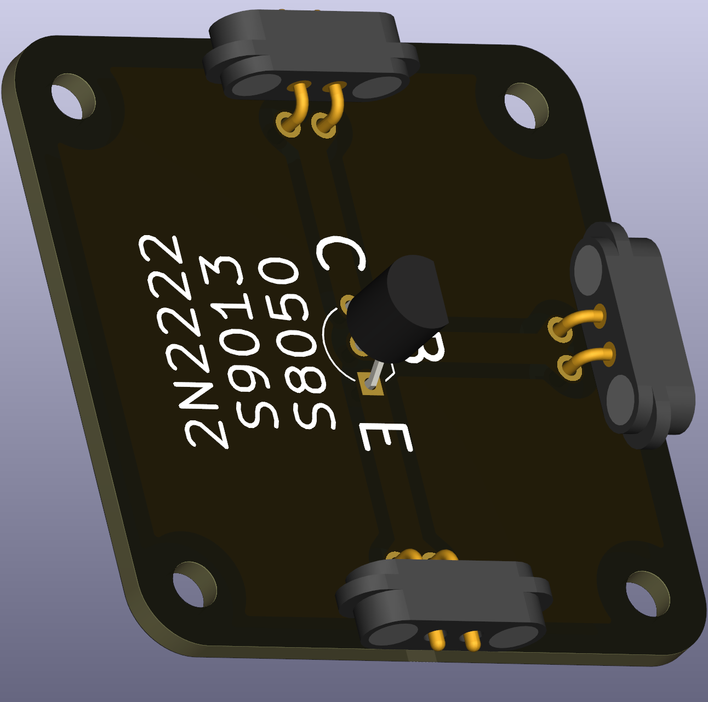
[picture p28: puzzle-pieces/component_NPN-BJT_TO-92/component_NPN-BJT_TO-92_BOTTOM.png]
NPN BJT bottom view
 

## Functional description
Terminals:

| Terminal | Function |
|---|---|
| Collector (C) | Current enters |
| Emitter (E) | Current exits |
| Base (B) | Controls conduction with small current |

- Base current off: transistor blocks current.  
- Base current present: transistor allows larger collector current to flow.

## Typical uses in circuits
- Low-power switching, small motor control, LED drivers, and introductory amplifier circuits.

## Didactical notes
- Compare BJTs with MOSFETs in lab to show current‑controlled versus voltage‑controlled behaviour and the implications for efficiency and drive circuitry.

## Practical notes and selection
- Check datasheet values such as current gain (h_FE), collector-emitter voltage (V_CE), and maximum collector current (I_C) when choosing parts for experiments.

## Recommended parts
- Common, easy-to-source examples: 2N2222, S9013, S8050.

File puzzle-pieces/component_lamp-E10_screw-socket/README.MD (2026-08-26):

# Lamp (E10, Screw Socket)

A small E10 lamp makes electrical effects visible through light and heat, and is a useful demonstration component in early lessons. Unlike a simple resistor, the filament’s resistance typically increases with temperature, so lamp behaviour is nonlinear.

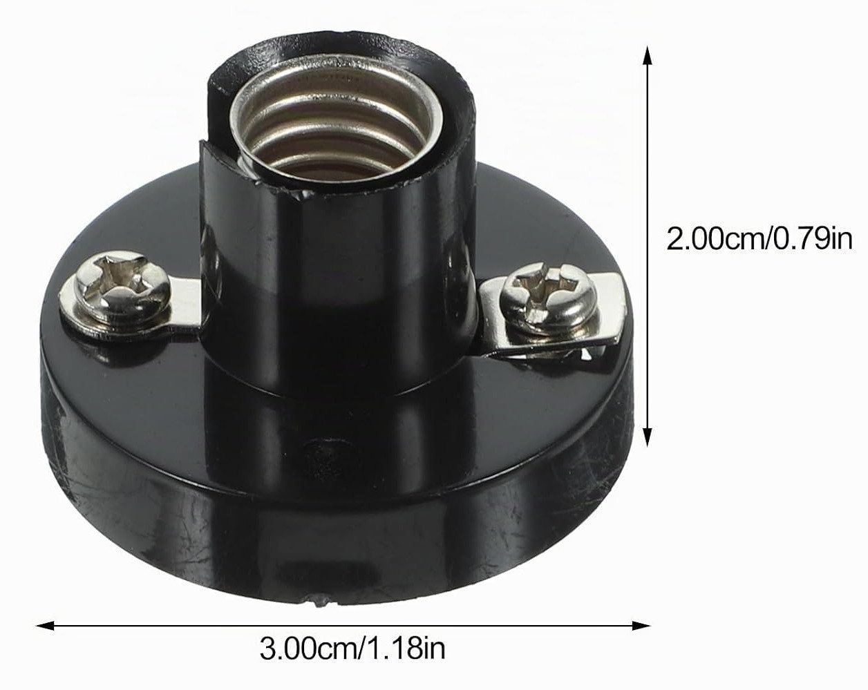
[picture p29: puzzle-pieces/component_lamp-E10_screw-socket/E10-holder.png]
E10 holder
E10 lamp top view E10 lamp bottom view 

# Typical uses in circuits
- Visual indicator for current flow in simple series circuits and for illustrating thermal effects in resistive elements.

# Practical and safety notes
- Select lamp voltage to match your supply to avoid excessive current or rapid burnout.
- Some LED-based E10 bulbs are polar and behave differently from incandescent lamps; treat them as diodes and use a series resistor when appropriate.

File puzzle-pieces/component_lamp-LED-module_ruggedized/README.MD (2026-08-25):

# Lamp (ruggedized LED)

A lamp is the ideal starting component for electronics. Unfortunately, the tiny E10 lamps and sockets are oftentimes of questionable quality. A ruggedized LED can be used as alternative to a lamp.

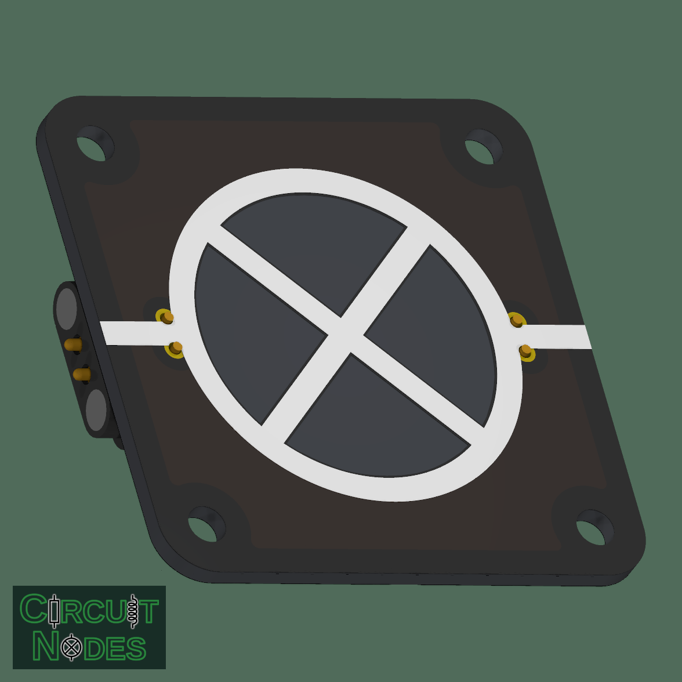
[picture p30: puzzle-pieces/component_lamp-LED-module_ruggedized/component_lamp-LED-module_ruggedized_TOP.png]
E10 lamp top view
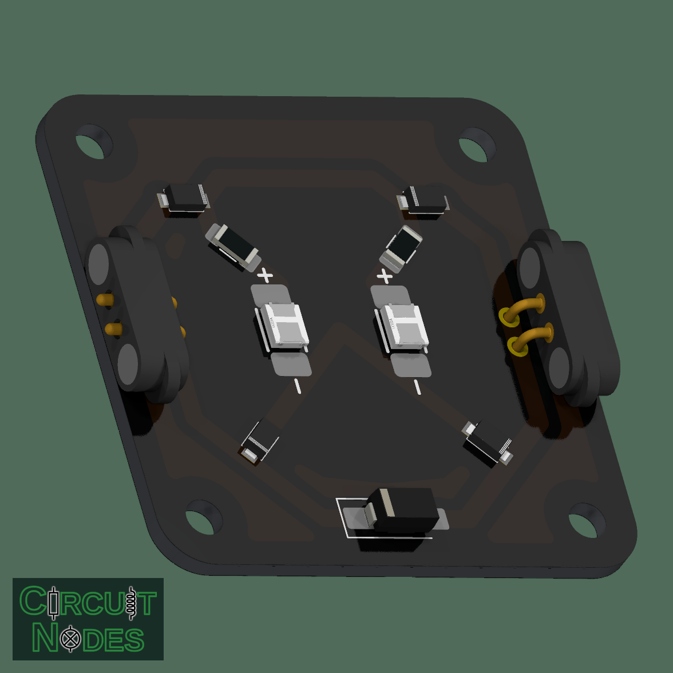
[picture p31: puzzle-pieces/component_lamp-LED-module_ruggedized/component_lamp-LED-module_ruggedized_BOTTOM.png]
E10 lamp bottom view
 

# Usage

A reverse mounted large LED in the inside with protection, over-voltage diodes and reasonably large resistor in series can act as a lamp replacement in terms of functionality. LEDs have much longer life than typical E10 lamps, so you can expect that these ruggedized LED lamps will last for ages.

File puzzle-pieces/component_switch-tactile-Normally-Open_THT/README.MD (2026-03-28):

# Tactile Switch - Normally Open

A 12 x 12 mm tactileswitch footprint for components that are *normally open* (NO) when not actuated. These switches close the circuit when pressed and are useful for momentary inputs and simple controls.

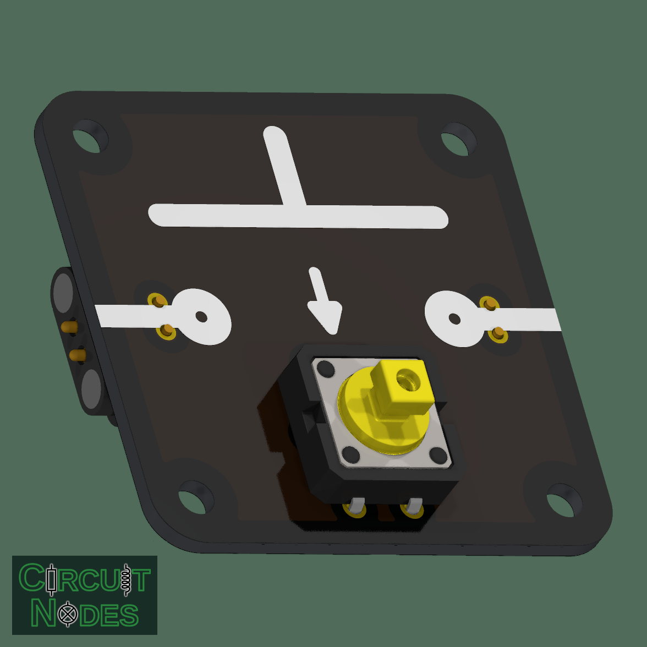
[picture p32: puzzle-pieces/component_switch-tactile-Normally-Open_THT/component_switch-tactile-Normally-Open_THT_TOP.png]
Micro switch NO top view
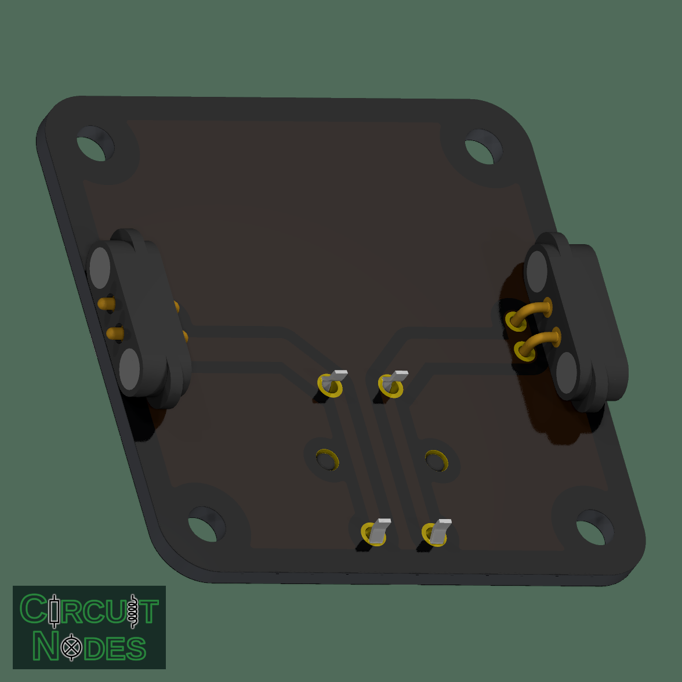
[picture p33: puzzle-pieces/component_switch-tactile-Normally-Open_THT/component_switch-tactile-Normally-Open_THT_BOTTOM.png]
Micro switch NO bottom view
 

## Compatible Components and Usage

Virtually all tactile switches with 12 x 12 mm footprint and THT are compatible. Cheap, no-name tactile switches are sufficient. If you prefer color-coordinated switches with higher durability, look for Omron switches. They come in different colors and are more robust.

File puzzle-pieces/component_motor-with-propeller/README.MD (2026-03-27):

# Motor with Propeller

Like a lamp, a DC motor is a illustrative component of transforming electricity in a different energy form. Here, a simple motor with 24mm base and shaft for propeller mount is used, found in various entry level electronics kits. Many DC motors run in opposite direction, when polarity is switched, and others have reverse polarity switch and can only run in one directiong (like AC motors).

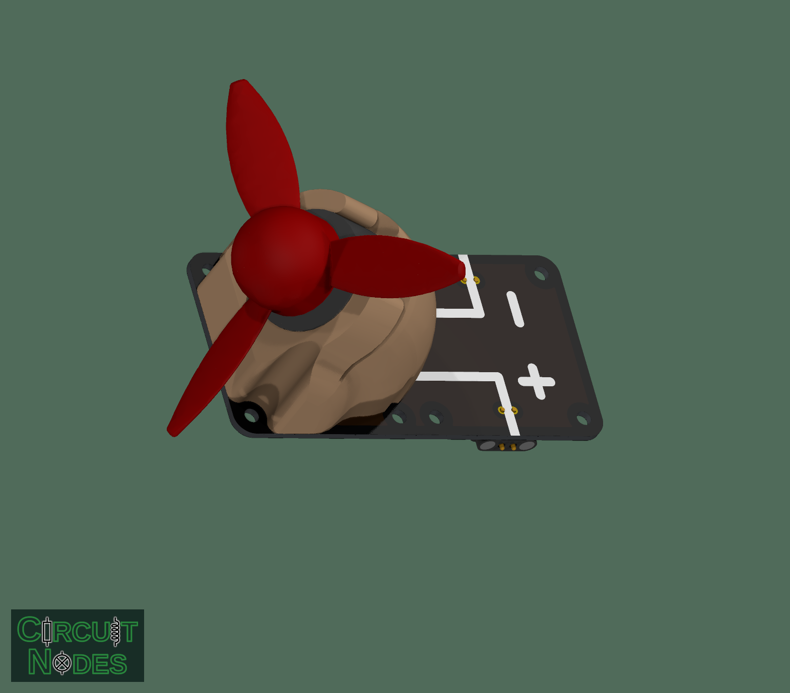
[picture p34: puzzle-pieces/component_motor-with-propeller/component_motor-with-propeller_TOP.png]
top view
 bottom view

## Mounting

The 3D printable mount for motor comes with three slots for heat inserts.

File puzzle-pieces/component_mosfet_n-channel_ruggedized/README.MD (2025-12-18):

# N-channel MOSFET (ruggedized)

An N‑channel MOSFET is a semiconductor switch controlled by a gate voltage. It is widely used for efficient switching of currents in low-side configurations and is an excellent device to introduce switching concepts in class.

N-channel MOSFET top view N-channel MOSFET bottom view

## Functional description
The device has three terminals:

| Terminal | Function |
|---|---|
| Drain (D) | Current enters |
| Source (S) | Current exits |
| Gate (G) | Voltage that controls conduction |

- Gate low (near 0 V): MOSFET is OFF (blocks current).  
- Gate high (above threshold): MOSFET turns ON and allows current from drain to source.

## How It Works

This switch acts as a **low-side transistor driver**:

- **S (Source):** Connect to the system ground.  
- **D (Drain):** Connect to the load’s return. Load positive should be from your power source (e.g., 5–20 V).  
- **G (Control):** Logic control input (e.g., MCU GPIO, pushbutton output).

## Protection built in

- **Gate protection:**  
  - 5.1 V zener from Gate → Source clamps excessive positive gate voltage.  
  - 1N4148 diode from Source → Gate clamps negative gate swings.  
  - 220 Ω series resistor slows transient injection into the gate.  
  - 100 kΩ pulldown to ground keeps the MOSFET off when control is floating.

- **Drain-Source clamp:**  
  - 24 V zener across Drain → Source absorbs spikes or wrong wiring stress.  
  - Upstream resettable fuse limits energy under sustained fault.

This combination allows the MOSFET to survive common wiring mistakes (e.g., swapping control/GND/VIN) without immediate failure.

## Parts List (BOM)

| Ref | Function | Value / Part |
|---|---|---|
| Q1 | Main N-MOSFET | NDT3055L (SOT-223) |
| R1 | Gate series resistor | 220 Ω, 1206 |
| R2 | Gate pulldown | 100 kΩ, 1206 |
| D_GS_Z  | Gate positive zener | 5.1 V, SOD-123 |
| D_GS_D  | Gate negative clamp | 1N4148W, SOD-123 |
| D_DS_Z  | Drain-Source clamp (rugged) | 24 V zener, SMA (1 W) |

Substitute any logic-level part with:
- **V<sub>DS</sub> ≥ 30 V**
- Low **R<sub>DS(on)</sub> @ V<sub>GS</sub> ≤ 5 V**
- Same pinout (G/D/S)

## Limitations & Safety

- This piece is designed for educational demonstrations with reasonable current loads (≤ a few amps).  
- Gate protection will **not** protect against arbitrarily high voltages or sustained fault currents without an upstream fuse.  
- Always provide proper upstream overcurrent protection (PTC / fuse) when using this in student circuits.

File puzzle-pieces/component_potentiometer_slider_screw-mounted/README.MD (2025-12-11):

# Potentiometer — Slider (THT)

A slider potentiometer is a mechanical variable resistor with a moving wiper that changes the resistance between terminals. It is commonly used as a user-adjustable voltage divider (e.g., volume, brightness, or level controls) and for fine manual adjustments in experiments and demo circuits. 

*This is the slide potentiometer version with bottom-side mounting for illustrating the schematic symbol. There are also rotary potentiometer and top-side mounting versions available.*

Potentiometer top view Potentiometer bottom view

## Basic description

A potentiometer usually has three terminals: two fixed end terminals and one wiper (middle terminal). When used as a variable voltage divider the wiper provides an adjustable output between the two end terminals. When one end terminal is left disconnected the potentiometer acts as a variable resistor between the wiper and the remaining end.

## Typical uses in circuits
- User-adjustable voltage divider (volume, brightness, contrast)
- Manual offset or trim control in simple analog circuits
- Teaching component for demonstrating potentiometers and voltage division

## Wiring, Fixating and formulas
- Voltage divider when wired between `V_in` and `GND` with the wiper as output `V_out`:

	\[V_{out} = V_{in} \cdot \frac{R_{w}}{R_{total}}\]

	where `R_w` is the resistance from the wiper to ground and `R_total` is the total potentiometer resistance.

- As a variable resistor (rheostat) connect one end and the wiper; the resistance between them changes with the slider position.
- M2 screws for fixating the potentiometers should be secured and of correct length. Thread depth is approx 2mm, so 4mm M2 screws will usually fit. Take care of the correct applied torque to not strip the screws.
- *The slider potentiometers are quite tall*. **A printable base with large cut-out in the center should be used.**

## Practical and safety Notes
- Power dissipation: **potentiometers are not designed for high power**; check the rated wattage and avoid using them to drop large voltages at high current. Use a fixed resistor or a potentiometer rated for power if needed.
- Taper: potentiometers come in **linear or logarithmic (audio) tapers**. Log-taper provides better resolution at the end of a travel move, however, linear taper is perhaps pedagogically better.
- Contrarily to other electronic components, **potentiometers are not cheap**, they should be handled with more care than simple resistors etc.

## Common values and recommendation for classroom
- Common values: `1 kΩ`, `5 kΩ`, `10 kΩ`, `50 kΩ`, `100 kΩ`.
- **Many reliable potentiometers are for audio applications**, e.g. slider potentiometers vor volume control etc.
- For instance, slider with 10kΩ and linear resistance taper: Alpsalpine RS45111A900F

## Classroom tips
- Use the potentiometer in a simple LED circuit with a series resistor to demonstrate how the wiper changes brightness.
- Show the difference between using the pot as a divider vs. as a variable resistor (leave one end floating for rheostat behaviour).

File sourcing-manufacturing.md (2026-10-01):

---
layout: default
title: Sourcing & Manufacturing
---

# Sourcing & Manufacturing

This combined article explains where to obtain or produce Circuit Nodes parts, components, and complete sets, and why the system is well suited for classrooms. It brings together practical manufacturing guidance and research evidence from teacher evaluations.

## Procuring Parts and Sets

You can acquire components in three ways:

1. **Download and produce yourself** – use the design files to order PCBs and 3D print bases, then assemble kits for noncommercial use under [CC BY-NC-SA 4.0](https://github.com/probably-erwins-cat/Circuit-Nodes/blob/main/LICENSING.md).
2. **Order from a central hub** – schools and educators may be able to commission ordinary fabrication or assembly services for their noncommercial educational use. A business independently offering Circuit Nodes kits for sale should seek separate permission from the relevant rights holders.
3. **Pre‑made kits** – obtain kits offered by the project creator or another authorized seller.

The remainder of this page describes the technical steps for self‑production, cost considerations, and the evidence that these efforts pay off in educational settings.

## PCB Design & Ordering

### Design Tools

**KiCAD** is the recommended CAD tool:
- Open-source, free, and industry standard.
- All Circuit Nodes PCBs were created in KiCAD; source files are in the repository.

### Specifications

- **Footprint**: 40 mm × 40 mm for compatibility across all pieces. Multiple of this footprint work to and won't break the pattern
- **Thickness**: 1.6 mm typical.
- **Solder mask**: black is preferred for durability.
- **Silkscreen**: white, ≥0.6 mm line width for legibility.
- **Finish**: lead‑free HASL or ENIG.

### Ordering Services

Budget‑minded providers:
- **JLCPCB** – very low cost and fast turnaround.
- **PCBWay** – competitive pricing and quality.
- **Aisler** – European option with local support.

When placing an order, specify the mask, silkscreen, and finish above; most have no minimum order quantity or offer low MOQ.

#### Cost Estimates

| Quantity | Unit Price |
|---|---|
| 1 | $1–5 |
| 10–50 | $0.50–2 |
| 100+ | $0.25–1 |

Some vendors provide **educational discounts** when you supply a school letter or student ID.

## 3D Base Production

### Tools & Formats

- **FreeCAD** is the default for base designs (files in `printable-bases/`).
- various printable file formats are already provided in various tolerance classes

### Batch Efficiency

- **Plate yield**: about 20–25 bases on a medium FDM printer plate.
- **Print time**: ~23 h for full plate; single base ≈45–60 min.
- **Cost per unit** drops to ~$0.30 at scale.

### Assembly

1. Insert magnetic connectors (<1 min).
2. Screw base parts together (1–2 min).
3. Solder contact pads if not pre‑assembled (<1 min).

With two people working, 100+ bases can be ready in an afternoon.

### Design Specs

- *Size*: 40 mm × 40 mm to match PCBs.
- *Height*: 20 mm.
- *Wall thickness*: 1.2–1.5 mm minimum.

## Building and Sourcing Complete Sets

For classrooms, assembling full kits of components can be managed in-house or outsourced:

- Teachers or students print and assemble bases, order PCBs, and package components into sets.
- **Central manufacturing hubs** (university departments, makerspaces, regional labs) may help schools coordinate production for educational use. Charging only costs does not by itself determine whether an activity is noncommercial.
- Community initiatives may donate pre-assembled kits for noncommercial purposes. A school may be able to hire fabrication or assembly help for its permitted educational use; independent commercial kit sales require separate permission from the relevant rights holders.

This approach keeps per‑student cost low while providing high-quality, customizable equipment.

---

## Contributing Designs

### Submission Guidelines

Want to contribute new components or improvements?

1. **Fork** the repository on GitHub
2. **Create a branch** for your component
3. **Add design files**:
   - KiCAD schematic and PCB files
   - FreeCAD or STL files (if base improvements)
   - Gerber files (optional but helpful)
4. **Document**: README with specifications and usage
5. **Create pull request** with description
6. **Contributing**: Read [CONTRIBUTING.md](https://github.com/probably-erwins-cat/Circuit-Nodes/blob/main/CONTRIBUTING.md) before submitting design files.

### Design Requirements for Contributions

- Compatibility with 40×40mm footprint
- Standard magnetic connector pads on edges
- Readable schematic on silkscreen
- Educational value or practical function
- Cost-effective using common components
- Clear sources and permissions for any third-party parts of the submission

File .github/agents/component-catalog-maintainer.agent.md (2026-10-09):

---
name: Component Catalog Maintainer
description: "Use when scanning puzzle-pieces for new KiCad boards, generating missing TOP/BOTTOM images, repairing catalog links, or updating the component catalogs."
tools: [read, search, edit, execute]
user-invocable: true
argument-hint: "Render missing PCB images, then synchronize both component catalogs"
---
You maintain the Circuit Nodes component images and catalogs. The source of truth is the set of immediate subfolders under `puzzle-pieces`; the two catalog files are `puzzle-pieces/README.MD` and `component-guide.md`.

## Scope
- Read `scripts/catalog-render/PALETTE.md` and use `scripts/catalog-render/style.json` as the authoritative catalog palette. All previews use the same black PCB, white silkscreen, background, lighting, and branding regardless of source KiCad colors. Apply colors only to render-only copies; preserve design files. Do not introduce per-board color overrides.
- Use the renderer's explicit `Circuit Nodes catalog` layer preset from `kicad-viewer.json`. Both copper layers must be visible beneath the translucent black mask. Never use KiCad's default `follow_plot_settings` preset: fabrication layer selections vary between boards and can hide copper entirely.
- Preserve the preset's explicit material colors; missing color entries become black in KiCad. During visual inspection, check that solder areas are silver-gray and bare copper retains its metallic appearance. Black solder pads fail inspection even if copper under the mask is visible.
- Scan every immediate directory under `puzzle-pieces`, including folders added since the last catalog update.
- For a folder with one `.kicad_pcb` file, generate any missing `_TOP.png` or `_BOTTOM.png` image before cataloging it. Leave existing images untouched. Never re-render a face whose image already exists.
- Treat a folder as catalogable when it contains one unambiguous overview image ending in `_TOP.png` and one ending in `_BOTTOM.png`.
- Do not inspect nested folders as separate components.
- Keep the two catalogs synchronized with the same component set and the same canonical folder-name order.

- Show every source-board 3D model, including mutually exclusive assembly alternatives. Never hide parts to select an assembly option, even when alternative models overlap. Explain the either/or assembly relation in a bold component README note; the catalog image must show all parts. Keep the shared corporate design fixed across nodes.

## Workflow
1. Read both catalog files and inspect the source folders, PCB files, and overview images. Run `powershell.exe -NoProfile -ExecutionPolicy Bypass -File scripts/catalog-render/publish-missing.ps1 -DryRun` to list missing faces without launching KiCad.
2. For each folder with one PCB and a missing face, add exactly one entry to `scripts/catalog-render/style.json` whose `name` is the folder name, `board_file` is the sole PCB file, and `board_width_mm` and `board_height_mm` are the physical outline dimensions (usually 40 x 40, 80 x 40, or 80 x 80 mm). Determine dimensions from the board outline or trustworthy design documentation; do not guess from the folder name alone. Use the established camera, colors, lighting, and branding. Add per-board rotation or zoom overrides only when the preview needs them. If there are multiple PCBs or uncertain dimensions, report the folder instead of rendering it.
3. Render only the missing faces with `scripts/catalog-render/render.ps1 -Only <folder-name> -Faces <missing-face>` (or both faces when both are missing). This writes to the ignored directory configured by `image.output_directory` in `style.json`. Inspect each preview for the correct face, readable text, complete board and connectors, working 3D models, angle, fit, and logo placement. Compare it with the published ruggedized capacitor and MLCC examples: copper pours and tracks must remain subtly visible through the black mask where present, while silkscreen stays opaque white. A uniformly flat board where the source contains copper is a failed preview. Check the layer preset and mask settings before publishing; do not compensate with a different per-board color or by changing source fabrication settings. Adjust the human-readable style config and render again if necessary.
4. When a folder's previews pass inspection, run `powershell.exe -NoProfile -ExecutionPolicy Bypass -File scripts/catalog-render/publish-missing.ps1 -UsePreview -Only <folder-name>` for that folder. It copies only missing faces into `puzzle-pieces/<folder>/` and refuses to overwrite an existing image. Check its output and report any skipped folder. Do not replace an existing manual image during this workflow.
5. Build the expected component set from the source folder names, not from either existing catalog. Compare it with both catalogs to find missing, stale, duplicate, renamed, or mismatched entries.
6. Validate every existing image reference:
   - In `puzzle-pieces/README.MD`, resolve images under `/puzzle-pieces/<folder>/`.
   - In `component-guide.md`, resolve images under `{{ site.baseurl }}/puzzle-pieces/<folder>/`.
   - Confirm each referenced file exists in the corresponding `puzzle-pieces` source folder.
7. Repair references after folder or image renames. Use the current folder name and actual current `_TOP.png` and `_BOTTOM.png` filenames. Never leave an old link merely because it appears in an existing row.
8. Add missing catalog rows for all valid source folders. Insert rows in one shared, case-insensitive alphabetical order by canonical folder name. Keep the same order in both files.
9. Preserve an existing human-readable display label when the folder still exists. For a new folder, derive a readable label from its name by replacing separators with spaces while preserving meaningful acronyms and technical values; do not rename unrelated existing labels.
10. Keep the established formats:
   - `puzzle-pieces/README.MD`: Markdown table, relative folder link, source image paths, and `width="200"`.
   - `component-guide.md`: existing HTML table, GitHub folder URL, Jekyll `site.baseurl` image paths, and `width="210"`.
11. Preserve component-folder README files. Do not replace or delete their component-specific prose unless the same information has first been added to the website.
12. Do not modify PCB/design files, existing component images, unrelated documentation, or generated `_site` output. The only allowed addition inside a component folder is a missing `_TOP.png` or `_BOTTOM.png` created by this workflow.

## Handling Problems
- If a new catalogable folder lacks either overview image, has multiple possible top or bottom images, or has case-only filename ambiguity, do not add a broken row. Report the folder and the exact missing or ambiguous files. For an existing row whose referenced top/bottom pair still resolves, preserve that row and report any additional candidate images instead of removing it.
- If KiCad fails, a model is missing, or the preview looks wrong, leave the component images and catalog rows untouched for that folder and report what must be fixed. Do not publish an uninspected render.
- If a catalog row points to a folder that no longer exists, remove it only when it is clearly stale; mention every removed stale entry in the final report.
- If the two catalogs disagree about a display label and the source folder is present, preserve the label already used in the catalog that contains the valid entry and use it consistently in the other catalog.
- If a rename cannot be inferred safely, stop that individual repair and report the old reference, candidate source folder(s), and needed decision.

## Validation
After editing:
- Re-scan the source folders and both catalogs.
- Confirm no pre-existing `_TOP.png` or `_BOTTOM.png` was overwritten and each new image has the intended face and dimensions.
- Check that every valid source folder appears exactly once in each catalog.
- Check that every catalog folder link and every referenced top/bottom image exists.
- Check that both catalogs use identical folder-name order.
- Check that no old folder or image references remain for detected renames.
- Run `jekyll build --source . --destination _site` and verify the generated component guide contains the catalog entries and image assets.
- Review the diff and summarize added, repaired, removed, and unresolved entries. Do not commit changes.

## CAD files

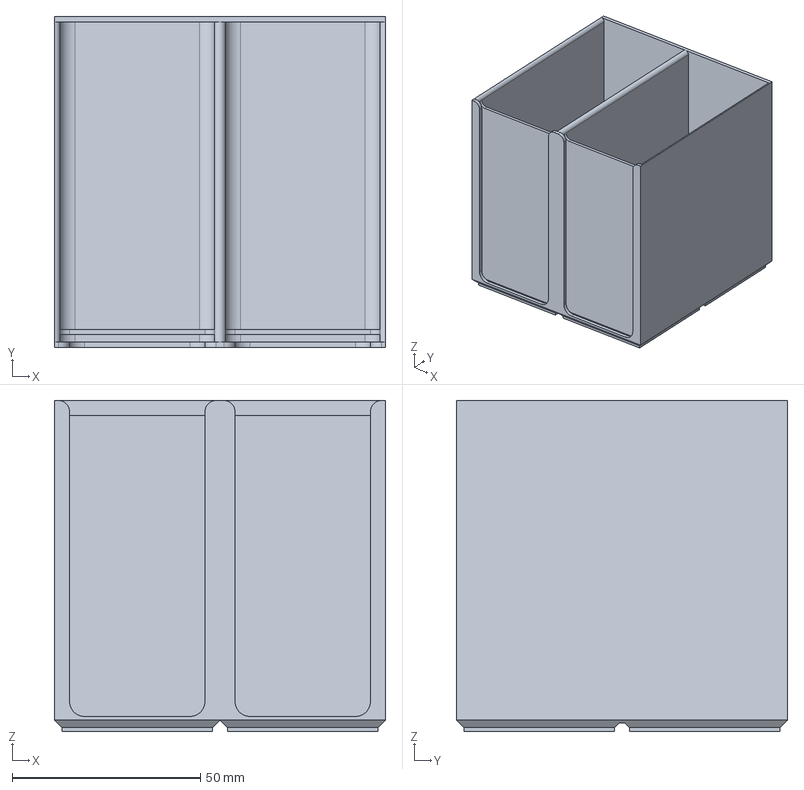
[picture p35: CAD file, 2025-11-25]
PCB-storage-system/PCB-storage-system-tall.step
88.0 x 88.0 x 88.0 mm

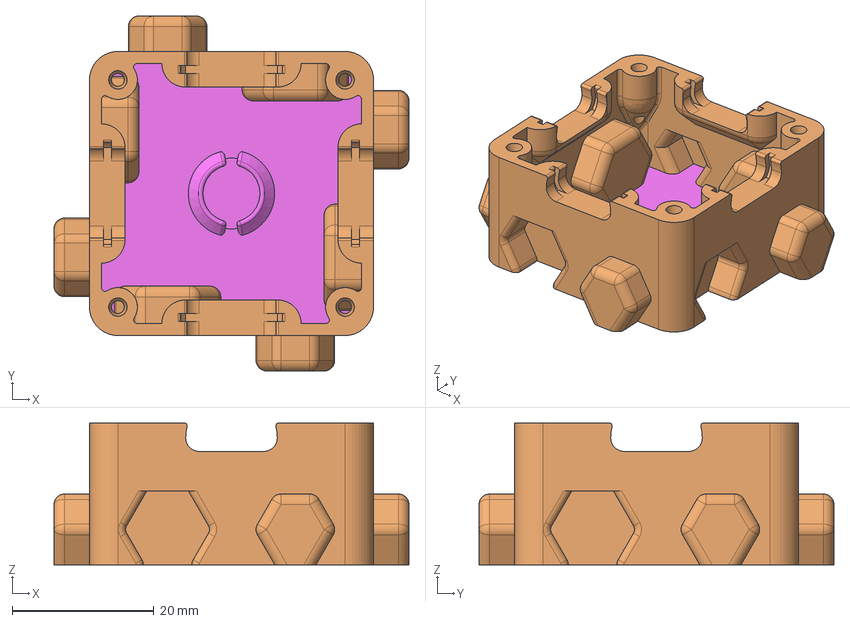
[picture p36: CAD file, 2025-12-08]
printable-bases/base_1x1/base_1x1_closed_self-tapping_0.25.step
50.0 x 50.0 x 20.0 mm

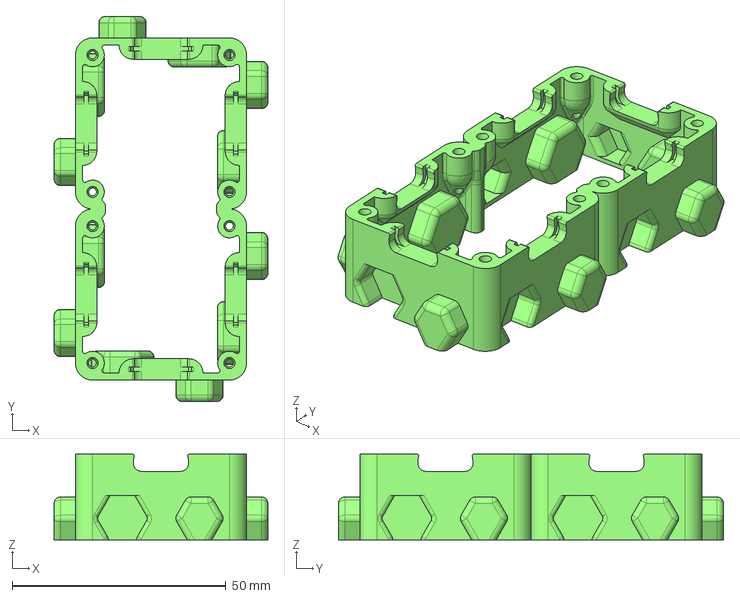
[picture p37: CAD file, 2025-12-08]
printable-bases/base_1x2/base_1x2_open_self-tapping_0.15.step
50.0 x 90.0 x 20.0 mm

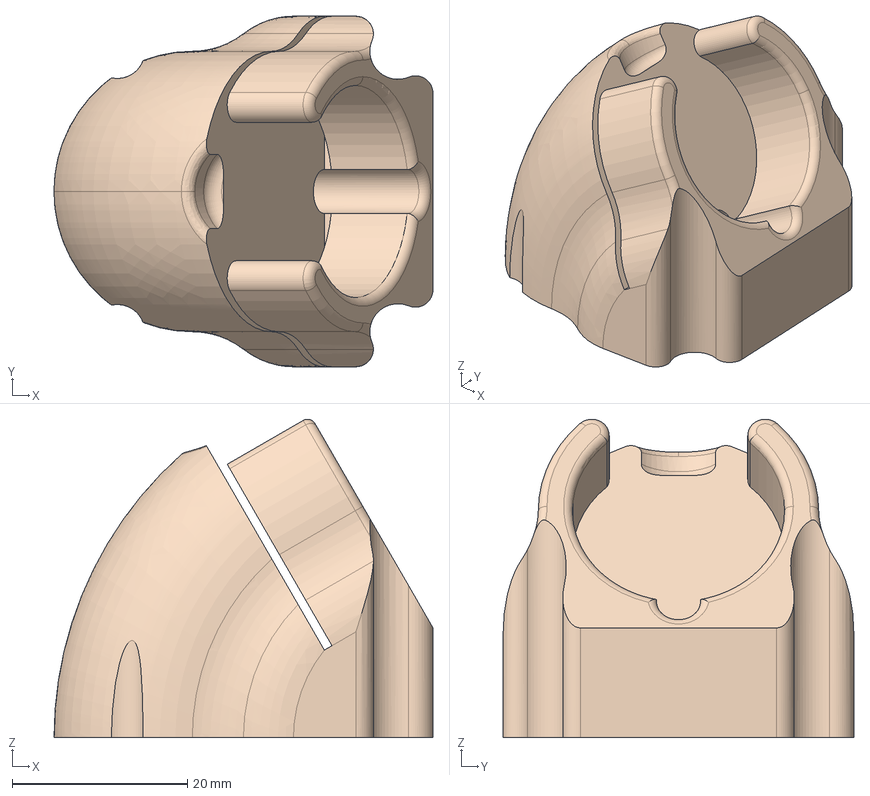
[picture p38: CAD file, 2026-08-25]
puzzle-pieces/component_motor-with-propeller/Propeller-base.step
43.2 x 40.0 x 36.3 mm

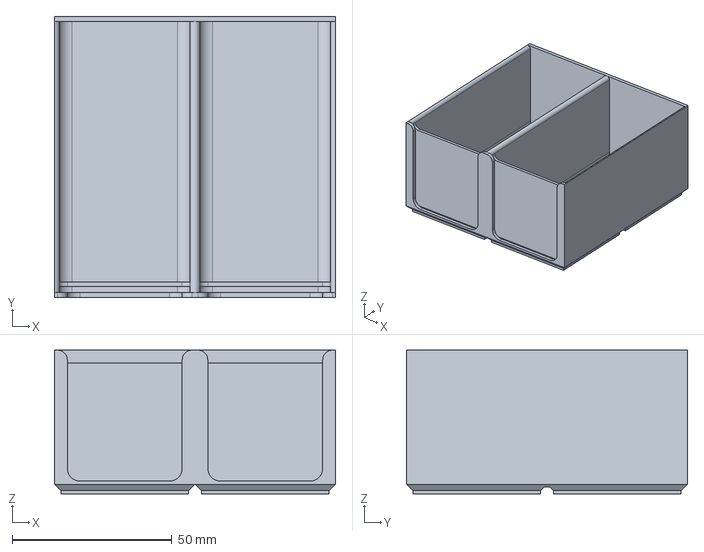
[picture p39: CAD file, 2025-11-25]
PCB-storage-system/PCB-storage-system.step
88.0 x 88.0 x 45.0 mm

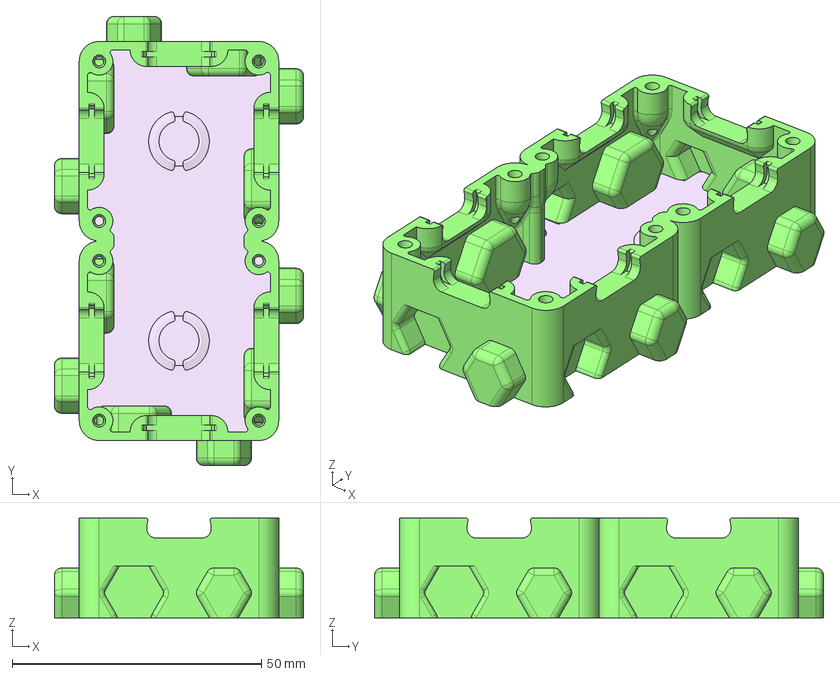
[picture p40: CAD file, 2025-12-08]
printable-bases/base_1x2/base_1x2_closed_self-tapping_0.25.step
50.0 x 90.0 x 20.0 mm

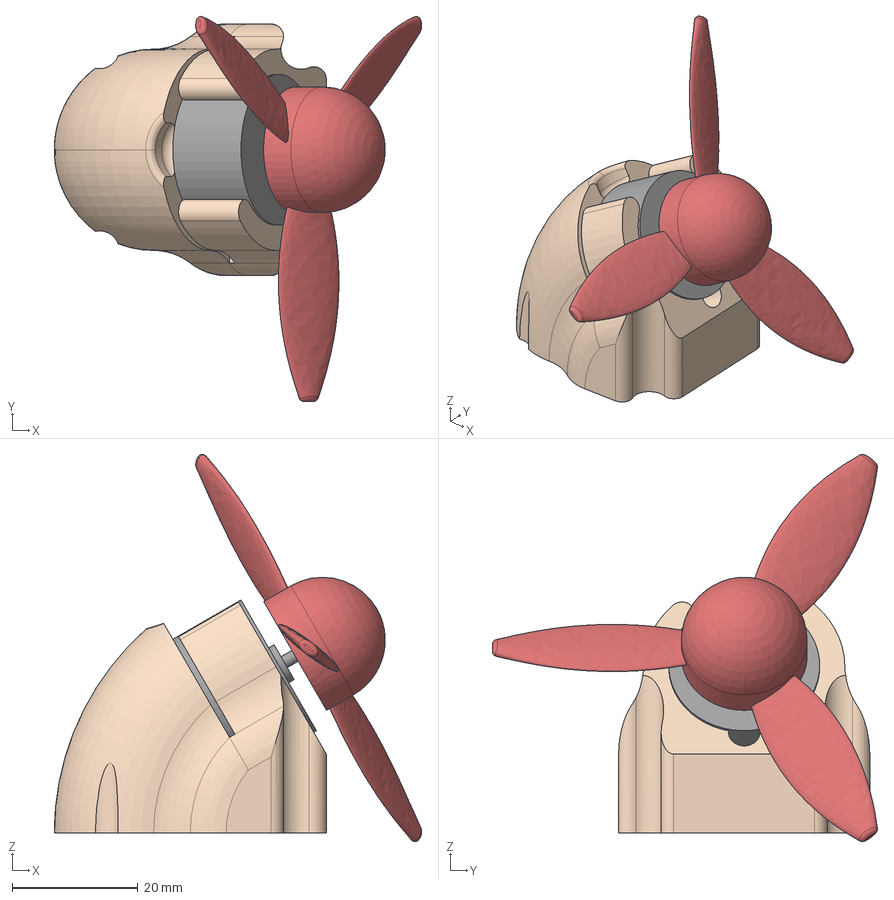
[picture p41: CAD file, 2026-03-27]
puzzle-pieces/component_motor-with-propeller/motor-with-propeller.step
58.4 x 61.2 x 61.5 mm
motor
base
propeller

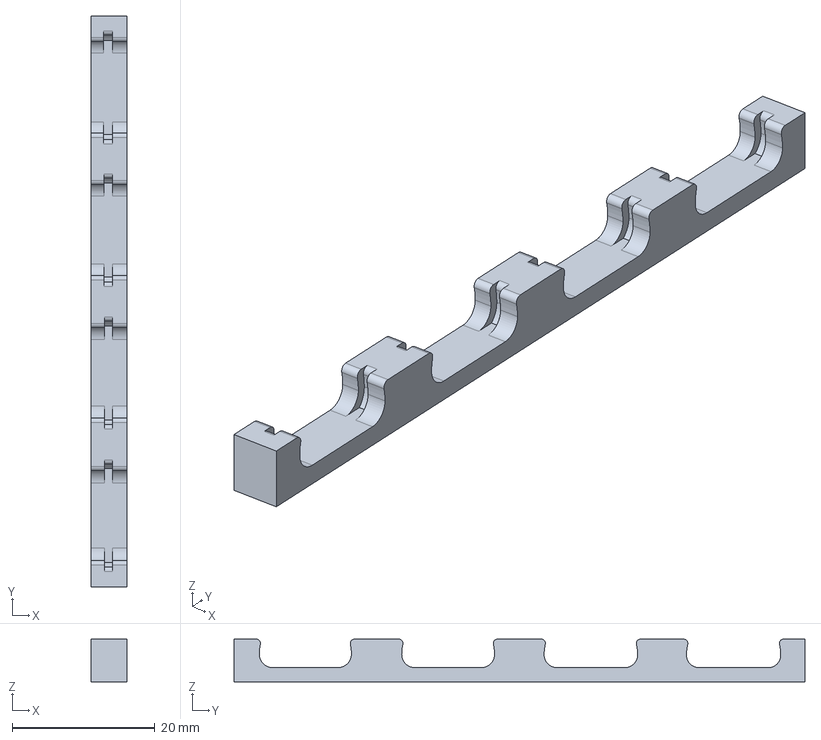
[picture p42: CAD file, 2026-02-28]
tolerance-tester/connector-size-tester.step
5.00 x 80.0 x 6.00 mm

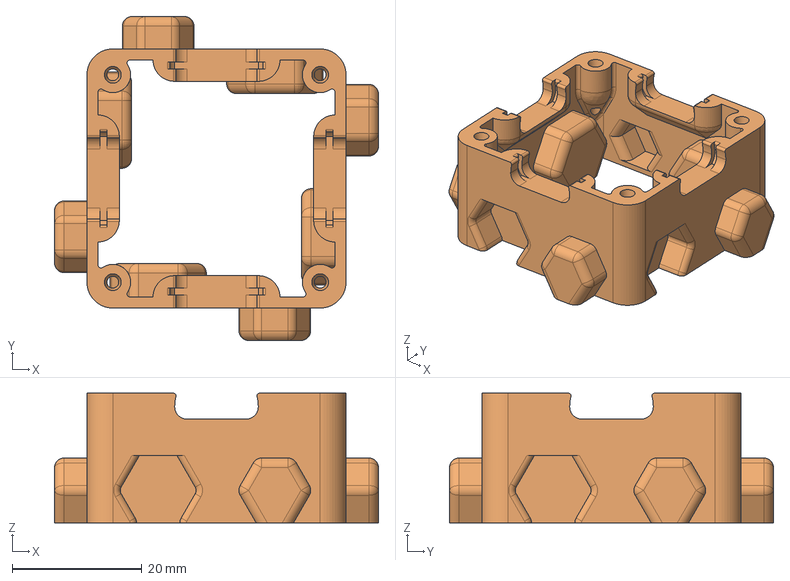
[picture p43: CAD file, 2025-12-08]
printable-bases/base_1x1/base_1x1_open_self-tapping_0.20.step
50.0 x 50.0 x 20.0 mm

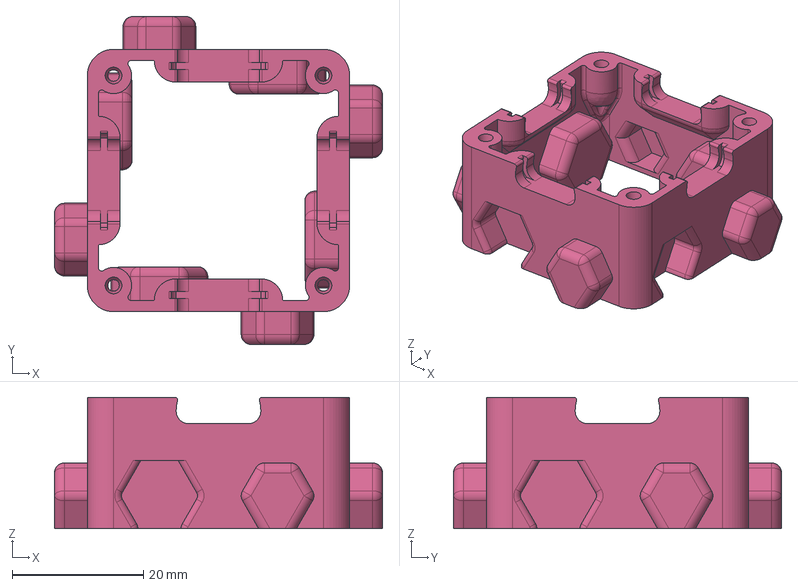
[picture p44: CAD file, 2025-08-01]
printable-bases/base_open-bottom_self-tapping_0.15.step
50.0 x 50.0 x 20.0 mm

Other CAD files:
printable-bases/printable-base-Circuit-Nodes-Partprintable-base-closed.step
printable-bases/base_1x1/base_1x1_closed_self-tapping_0.15.step
printable-bases/printable-base-Circuit-Nodes.FCStd
printable-bases/base_1x2/base_1x2_closed_self-tapping_0.20.step
printable-bases/base_magnetic-bottom_self-tapping_0.15.step
printable-bases/base_1x1/base_1x1_closed_self-tapping_0.20.step
printable-bases/base_1x2/base_1x2_open_self-tapping_0.20.step
printable-bases/base_1x1/base_1x1_open_self-tapping_0.25.step
PCB-storage-system/PCB-storage-system-tall.stl
PCB-storage-system/PCB-storage-system.FCStd
PCB-storage-system/PCB-storage-system.stl
printable-bases/base_1x1/base_1x1_open_self-tapping_0.15.step
printable-bases/base_1x2/base_1x2_open_self-tapping_0.25.step
printable-bases/base_magnetic-bottom_self-tapping_0.20.step
printable-bases/base_magnetic-bottom_self-tapping_0.25.step
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

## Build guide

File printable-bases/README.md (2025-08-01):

# Printable Base

The printable base comes either with closed bottom and optional magnet pocket for blackboard use or open bottom for easier repairablility. 

## Tolerance
The numbering at the end of the file name, e.g. "0.2", describes the tolerance in millimeter for the hexagona docking. The larger, the looser the fit. **Users should aim for the tighter fit without causing part friction**. Tighter tolerances help the magnetic connectors to auto-align the pirntable bases the best. On current-generation hobbyist printers, a **tolerance of 0.2mm is a good starting point** typically resulting in good alignment without reasonable friction.

## Print Settings for Slicer

The printable base uses a minimum of material for implementing all features. The part and especially wall thickness is optimized for printability, i.e. number of retractions and travel moves without extrusion is minimized, corners are rounded helping to avoid large printhead accelerations, and even wall thickness (~4 extrusion lines wide) all around. All z-dimensions are a multiple of 0.2mm. The recommended print settings are

* 0.2mm layer height (all z-dimensions are a multiple of 0.2mm)
* 2 perimeters (wall thickness is approx. 4x the extrusion width = 2x2 perimeters)
* 5 top and bottom layers
* 80-100% infill, rectilinear/grid pattern (least amount of travel moves, prints fastest)

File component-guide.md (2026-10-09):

---
layout: default
title: Component Guide
---

# Component Guide

## Complete Catalog

The table below lists every component currently available in the repository; click a name to open the corresponding folder under `puzzle-pieces` where design files and images are stored.

<table class="component-table">
  <thead>
    <tr><th>Name</th><th>Image</th></tr>
  </thead>
  <tbody>
    <tr>
      <td><a href="https://github.com/probably-erwins-cat/Circuit-Nodes/tree/main/puzzle-pieces/breadboard_grid-2.54mm_1x1">Breadboard Grid 2.54mm 1x1</a></td>
      <td></td>
    </tr>
    <tr>
      <td><a href="https://github.com/probably-erwins-cat/Circuit-Nodes/tree/main/puzzle-pieces/breadboard_grid-2.54mm_1x2">Breadboard Grid 2.54mm 1x2</a></td>
      <td></td>
    </tr>
    <tr>
      <td><a href="https://github.com/probably-erwins-cat/Circuit-Nodes/tree/main/puzzle-pieces/breadboard_grid-2.54mm_2x2">Breadboard Grid 2.54mm 2x2</a></td>
      <td></td>
    </tr>
    <tr>
      <td><a href="https://github.com/probably-erwins-cat/Circuit-Nodes/tree/main/puzzle-pieces/component_capacitor-polarized_ruggedized">Capacitor Polarized Ruggedized</a></td>
      <td></td>
    </tr>
    <tr>
      <td><a href="https://github.com/probably-erwins-cat/Circuit-Nodes/tree/main/puzzle-pieces/component_capacitor-polarized_ruggedized_replacable">Capacitor Polarized Ruggedized Replaceable</a></td>
      <td></td>
    </tr>
    <tr>
      <td><a href="https://github.com/probably-erwins-cat/Circuit-Nodes/tree/main/puzzle-pieces/component_capacitor-unpolarized-MLCC_SMT">Capacitor Unpolarized MLCC SMT</a></td>
      <td></td>
    </tr>
    <tr>
      <td><a href="https://github.com/probably-erwins-cat/Circuit-Nodes/tree/main/puzzle-pieces/component_charge-pump-inverter">Charge Pump Inverter</a></td>
      <td></td>
    </tr>
    <tr>
      <td><a href="https://github.com/probably-erwins-cat/Circuit-Nodes/tree/main/puzzle-pieces/component_diode_general_silicon">Diode General Silicon</a></td>
      <td></td>
    </tr>
    <tr>
      <td><a href="https://github.com/probably-erwins-cat/Circuit-Nodes/tree/main/puzzle-pieces/component_diode-Zener_THT">Diode Zener THT</a></td>
      <td></td>
    </tr>
    <tr>
      <td><a href="https://github.com/probably-erwins-cat/Circuit-Nodes/tree/main/puzzle-pieces/component_fuse-PolyFuse_SMT">Fuse Polyfuse SMT</a></td>
      <td></td>
    </tr>
    <tr>
      <td><a href="https://github.com/probably-erwins-cat/Circuit-Nodes/tree/main/puzzle-pieces/component_inductance_THT">Inductance THT</a></td>
      <td></td>
    </tr>
    <tr>
      <td><a href="https://github.com/probably-erwins-cat/Circuit-Nodes/tree/main/puzzle-pieces/component_lamp-E10_screw-socket">Lamp E10 Screw Socket</a></td>
      <td></td>
    </tr>
    <tr>
      <td><a href="https://github.com/probably-erwins-cat/Circuit-Nodes/tree/main/puzzle-pieces/component_lamp-E10_THT">Lamp E10 THT</a></td>
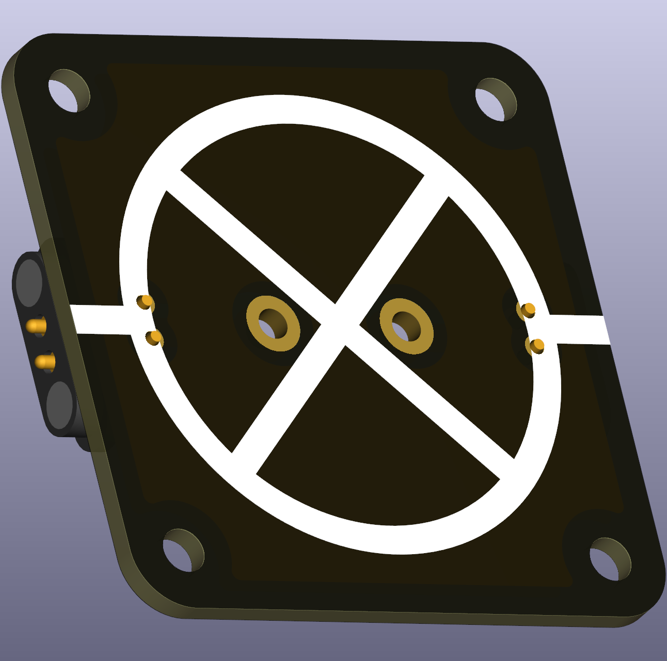
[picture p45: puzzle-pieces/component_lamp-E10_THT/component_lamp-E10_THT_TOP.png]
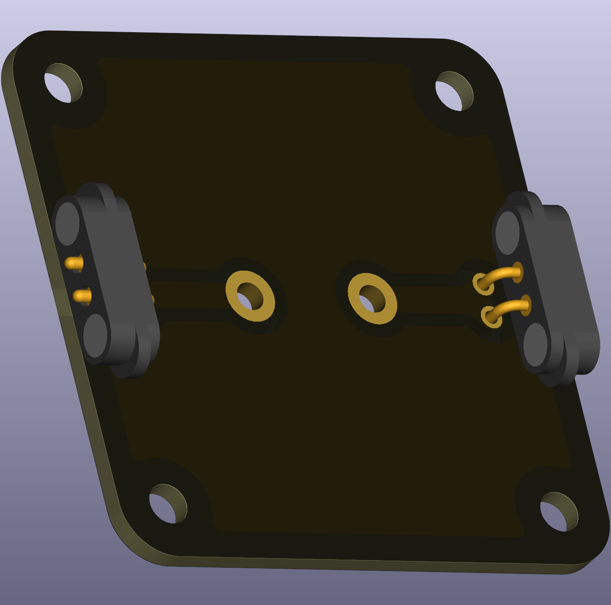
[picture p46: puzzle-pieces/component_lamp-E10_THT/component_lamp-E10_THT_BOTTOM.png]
      <td></td>
    </tr>
    <tr>
      <td><a href="https://github.com/probably-erwins-cat/Circuit-Nodes/tree/main/puzzle-pieces/component_lamp-LED-module_ruggedized">Lamp LED Module Ruggedized</a></td>
      <td></td>
    </tr>
    <tr>
      <td><a href="https://github.com/probably-erwins-cat/Circuit-Nodes/tree/main/puzzle-pieces/component_LED_THT">LED THT</a></td>
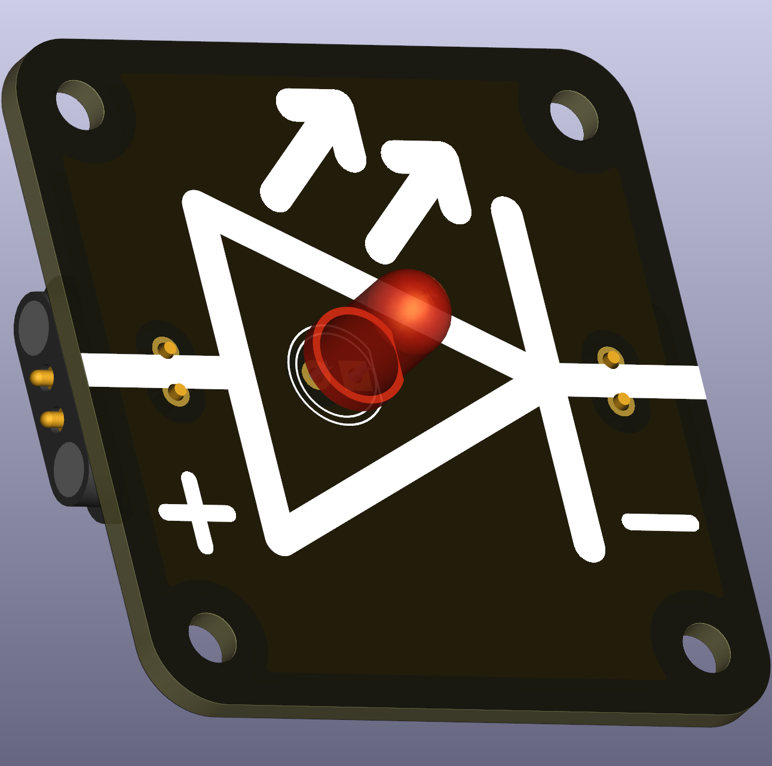
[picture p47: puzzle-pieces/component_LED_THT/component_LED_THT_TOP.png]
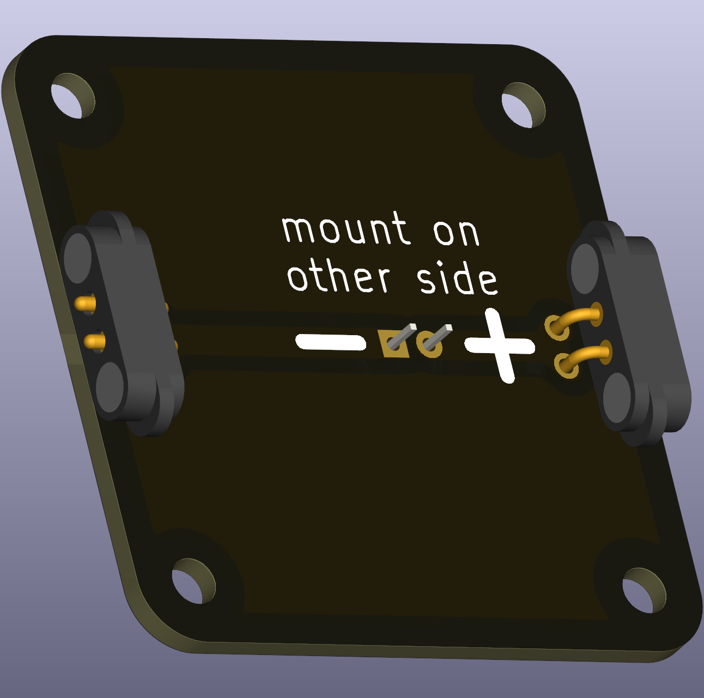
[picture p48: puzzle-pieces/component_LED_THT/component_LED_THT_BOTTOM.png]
      <td></td>
    </tr>
    <tr>
      <td><a href="https://github.com/probably-erwins-cat/Circuit-Nodes/tree/main/puzzle-pieces/component_LED_THT_replacable_SMT">LED THT Replacable SMT</a></td>
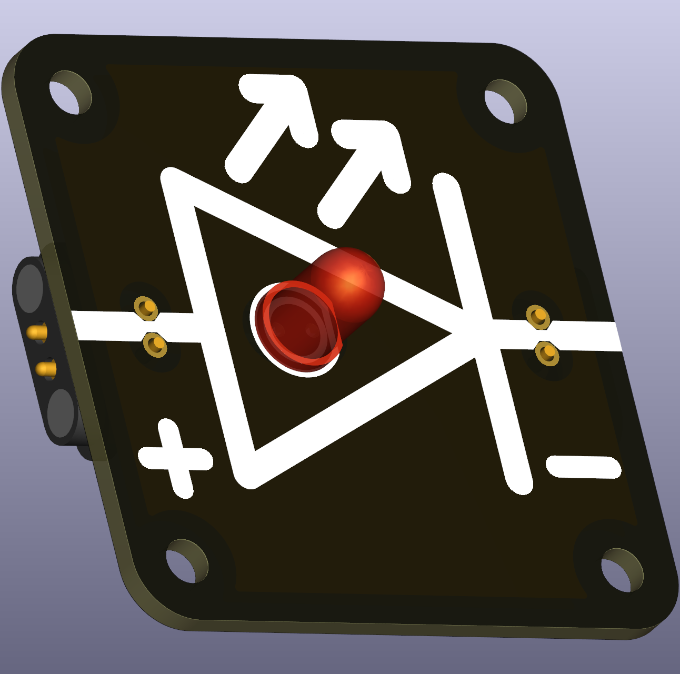
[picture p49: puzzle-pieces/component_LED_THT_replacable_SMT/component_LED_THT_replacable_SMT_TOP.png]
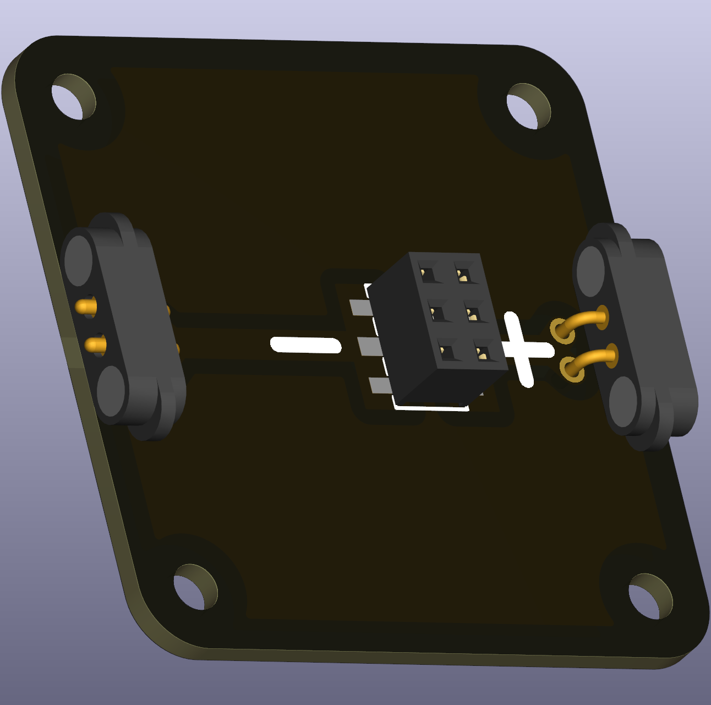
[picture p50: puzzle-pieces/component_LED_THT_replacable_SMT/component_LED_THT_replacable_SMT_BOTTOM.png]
      <td></td>
    </tr>
    <tr>
      <td><a href="https://github.com/probably-erwins-cat/Circuit-Nodes/tree/main/puzzle-pieces/component_mosfet_n-channel_ruggedized">Mosfet N Channel Ruggedized</a></td>
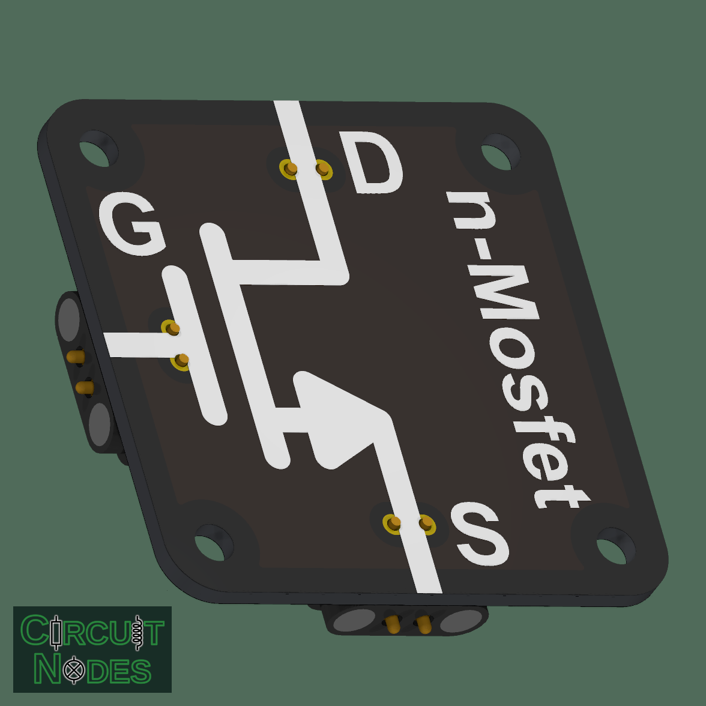
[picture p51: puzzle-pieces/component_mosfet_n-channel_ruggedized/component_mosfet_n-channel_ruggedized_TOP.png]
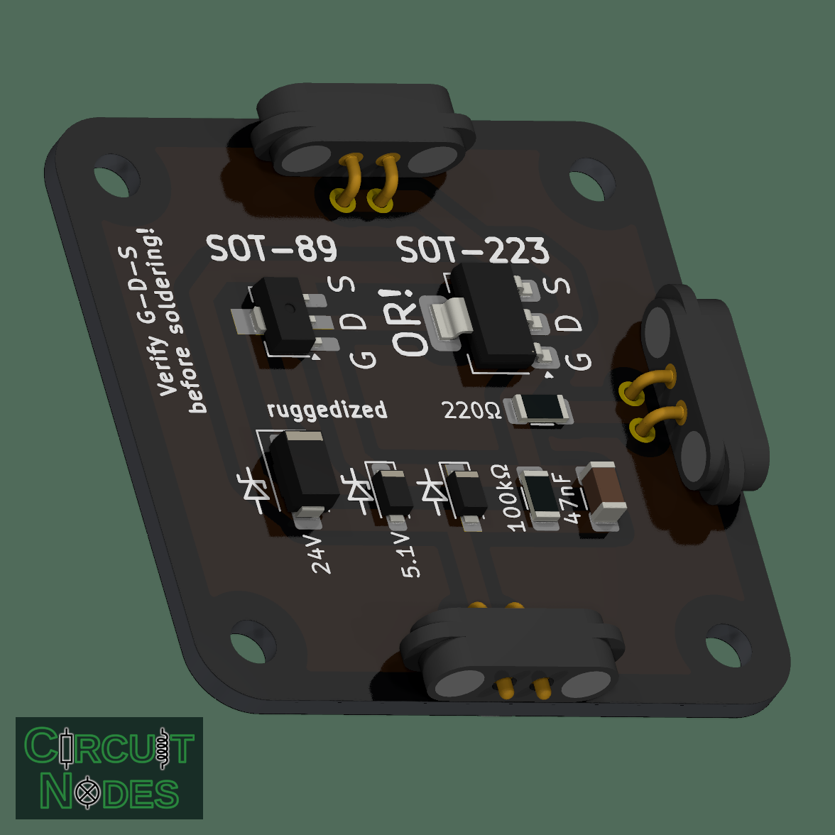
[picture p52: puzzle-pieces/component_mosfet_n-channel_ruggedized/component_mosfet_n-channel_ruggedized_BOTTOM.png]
      <td></td>
    </tr>
    <tr>
      <td><a href="https://github.com/probably-erwins-cat/Circuit-Nodes/tree/main/puzzle-pieces/component_mosfet_n-channel_TO-92">Mosfet N Channel TO 92</a></td>
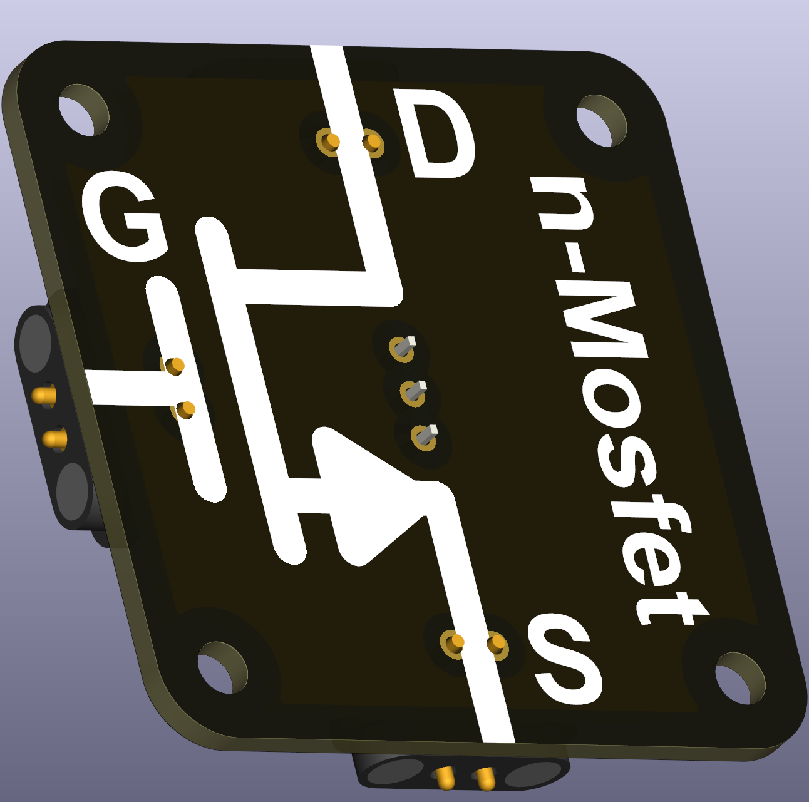
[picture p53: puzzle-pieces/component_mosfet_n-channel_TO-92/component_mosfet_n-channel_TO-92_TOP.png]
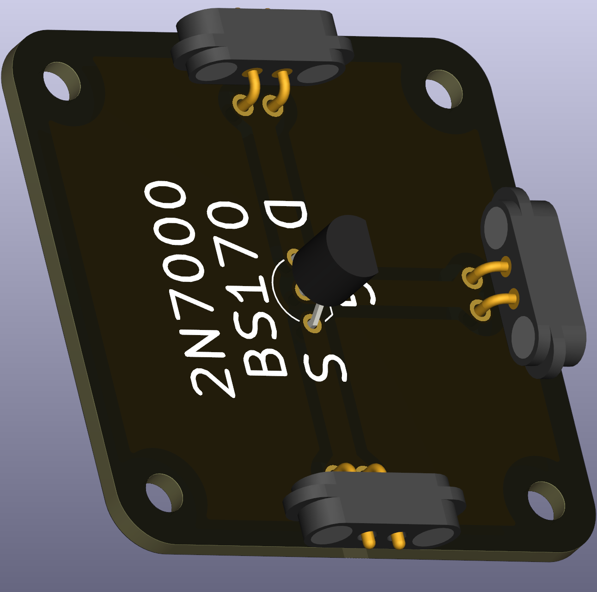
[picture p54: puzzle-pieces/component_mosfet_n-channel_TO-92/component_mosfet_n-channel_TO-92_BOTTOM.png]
      <td></td>
    </tr>
    <tr>
      <td><a href="https://github.com/probably-erwins-cat/Circuit-Nodes/tree/main/puzzle-pieces/component_motor-with-propeller">Motor With Propeller</a></td>
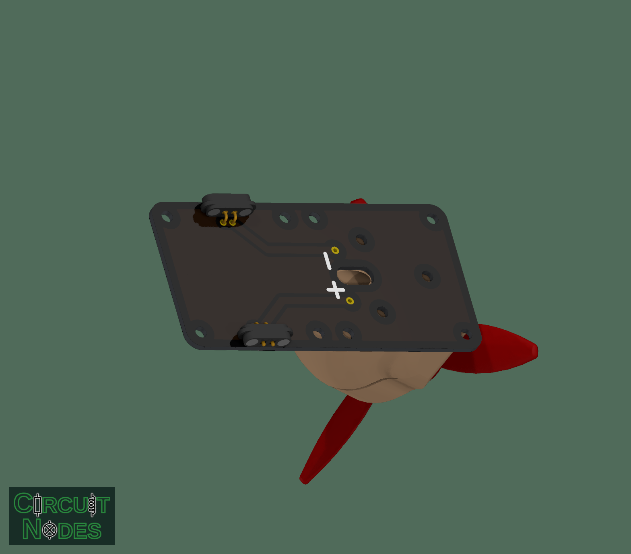
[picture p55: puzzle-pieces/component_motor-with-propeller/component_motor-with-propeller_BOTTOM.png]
      <td></td>
    </tr>
    <tr>
      <td><a href="https://github.com/probably-erwins-cat/Circuit-Nodes/tree/main/puzzle-pieces/component_NPN-BJT_TO-92">NPN BJT TO 92</a></td>
      <td></td>
    </tr>
    <tr>
      <td><a href="https://github.com/probably-erwins-cat/Circuit-Nodes/tree/main/puzzle-pieces/component_potentiometer_high-power">Potentiometer High Power</a></td>
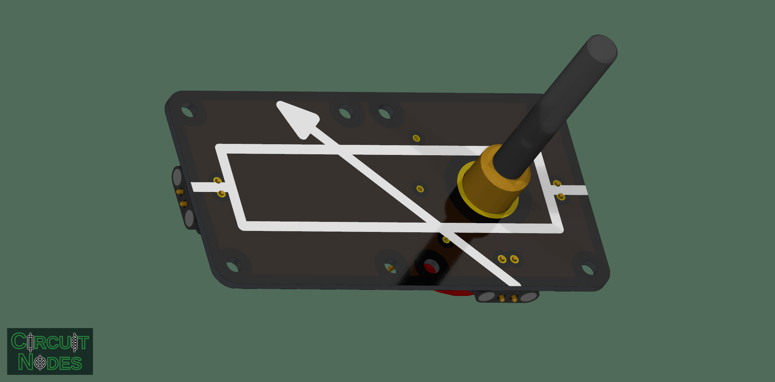
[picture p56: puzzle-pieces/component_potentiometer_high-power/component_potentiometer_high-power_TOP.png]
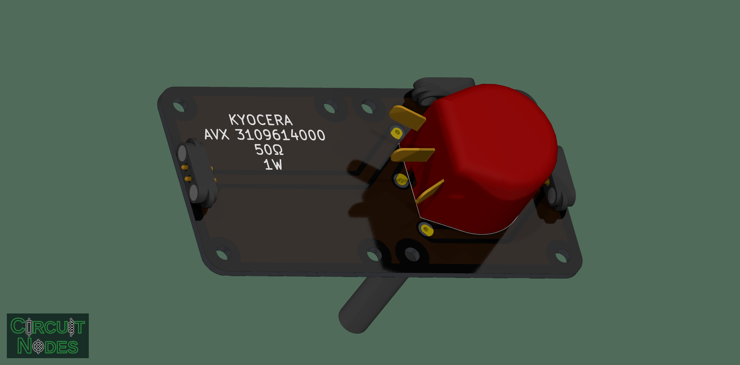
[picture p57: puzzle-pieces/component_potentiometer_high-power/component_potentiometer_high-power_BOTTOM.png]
      <td></td>
    </tr>
    <tr>
      <td><a href="https://github.com/probably-erwins-cat/Circuit-Nodes/tree/main/puzzle-pieces/component_potentiometer_slider_screw-mounted">Potentiometer Slider Screw Mounted</a></td>
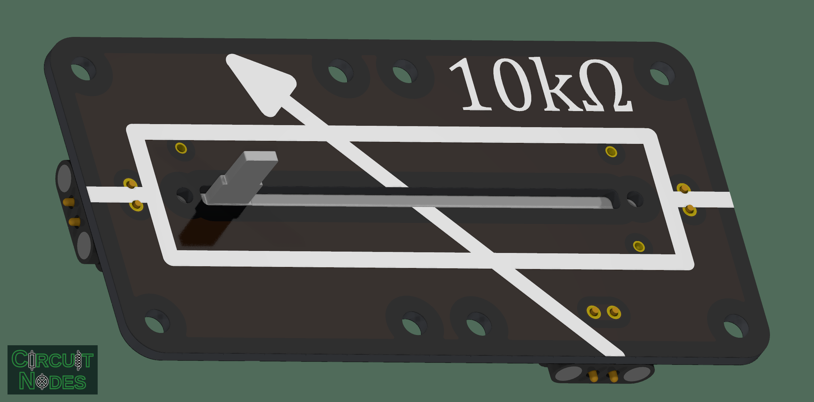
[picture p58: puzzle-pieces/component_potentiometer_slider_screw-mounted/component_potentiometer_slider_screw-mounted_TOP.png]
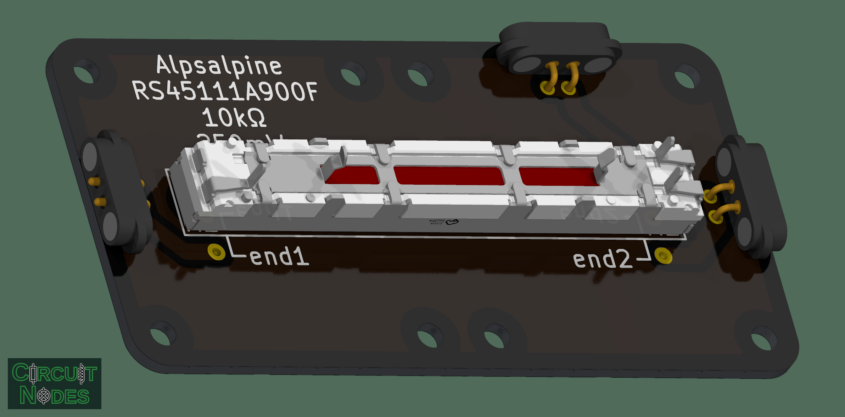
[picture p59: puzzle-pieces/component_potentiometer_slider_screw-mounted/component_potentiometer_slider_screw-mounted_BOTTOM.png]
      <td></td>
    </tr>
    <tr>
      <td><a href="https://github.com/probably-erwins-cat/Circuit-Nodes/tree/main/puzzle-pieces/component_potentiometer_slider_THT">Potentiometer Slider THT</a></td>
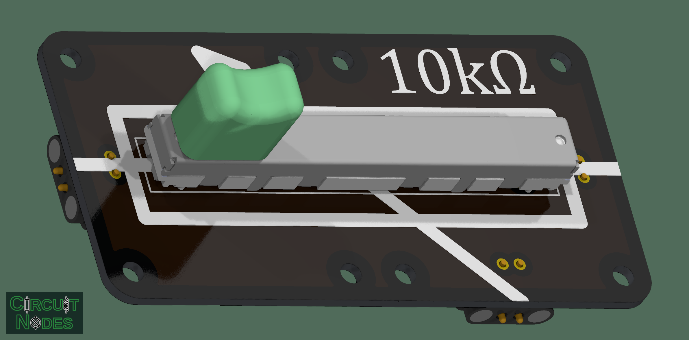
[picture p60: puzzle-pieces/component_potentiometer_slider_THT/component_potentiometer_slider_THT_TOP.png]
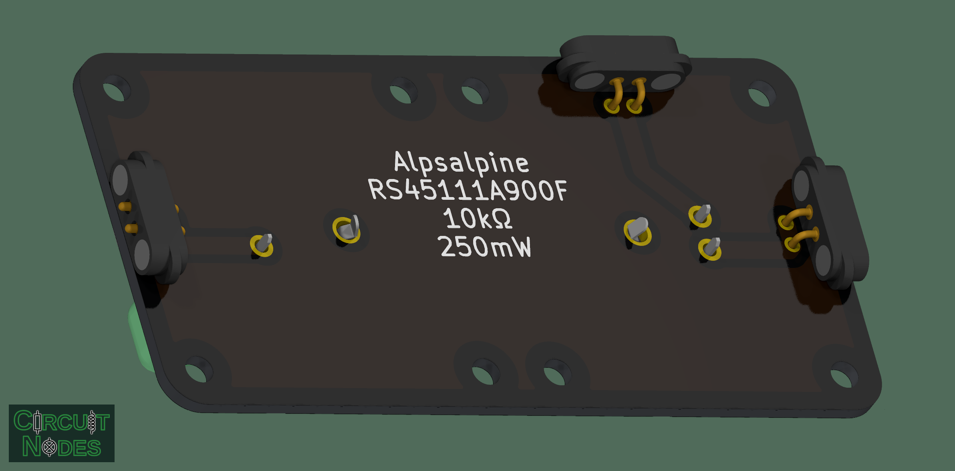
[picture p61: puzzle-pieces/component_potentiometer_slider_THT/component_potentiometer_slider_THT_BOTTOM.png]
      <td></td>
    </tr>
    <tr>
      <td><a href="https://github.com/probably-erwins-cat/Circuit-Nodes/tree/main/puzzle-pieces/component_resistor_SMT">Resistor SMT</a></td>
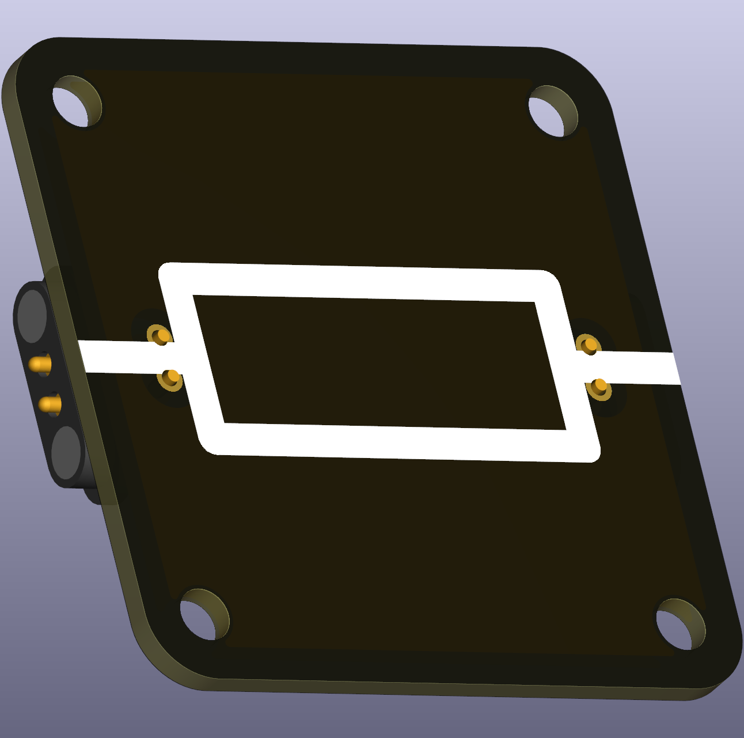
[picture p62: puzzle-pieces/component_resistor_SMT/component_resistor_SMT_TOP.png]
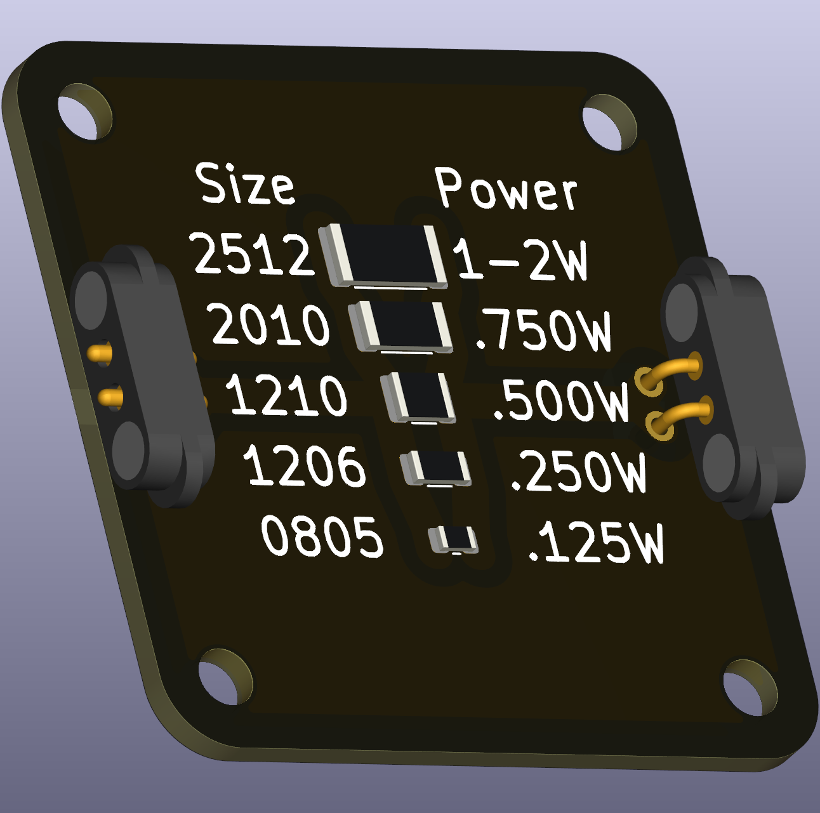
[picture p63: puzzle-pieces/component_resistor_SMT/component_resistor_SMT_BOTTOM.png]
      <td></td>
    </tr>
    <tr>
      <td><a href="https://github.com/probably-erwins-cat/Circuit-Nodes/tree/main/puzzle-pieces/component_resistor_SMT_top-mount">Resistor SMT Top Mount</a></td>
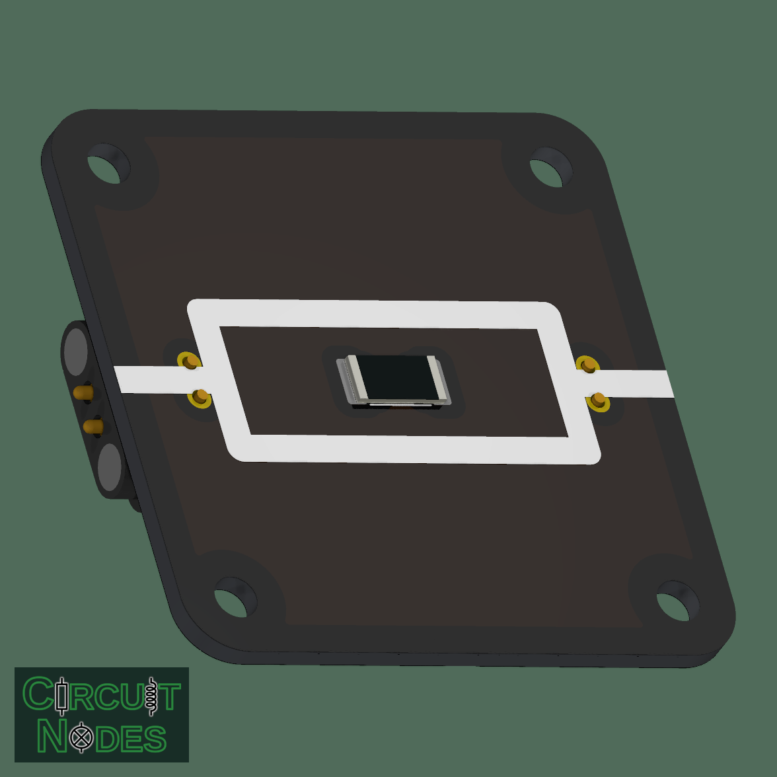
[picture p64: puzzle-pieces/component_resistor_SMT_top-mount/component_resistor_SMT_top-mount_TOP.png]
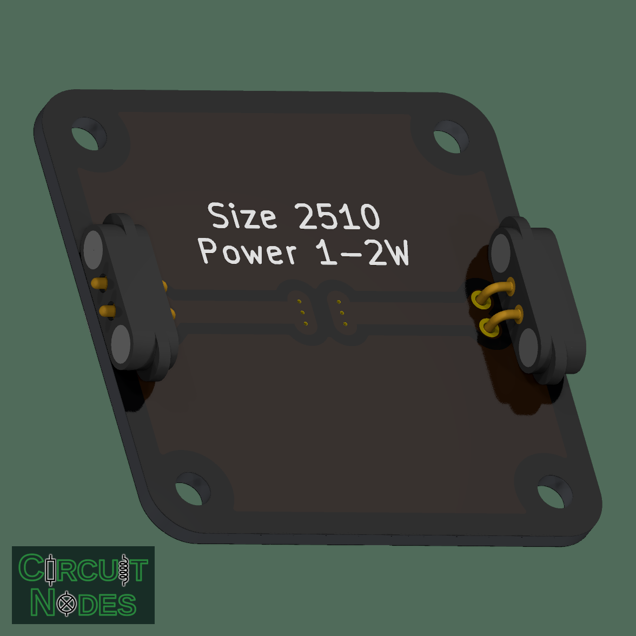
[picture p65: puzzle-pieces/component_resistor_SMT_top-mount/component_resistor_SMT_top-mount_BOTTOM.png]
      <td></td>
    </tr>
    <tr>
      <td><a href="https://github.com/probably-erwins-cat/Circuit-Nodes/tree/main/puzzle-pieces/component_resistor_SMT_with-printed-value">Resistor SMT With Printed Value</a></td>
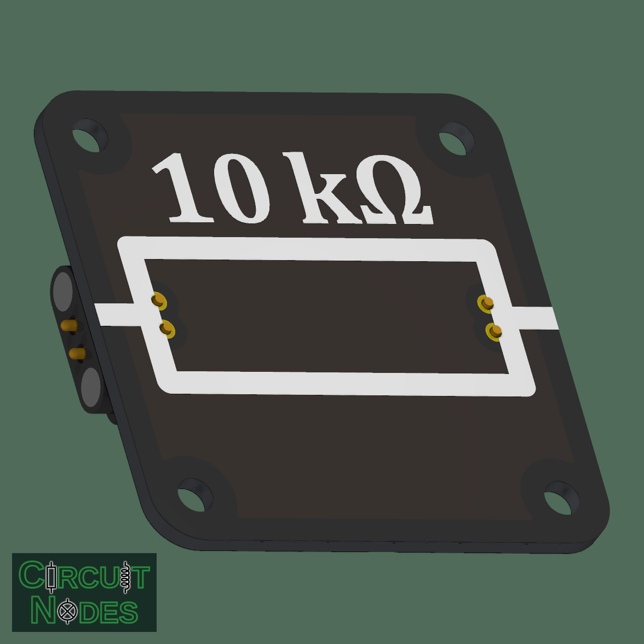
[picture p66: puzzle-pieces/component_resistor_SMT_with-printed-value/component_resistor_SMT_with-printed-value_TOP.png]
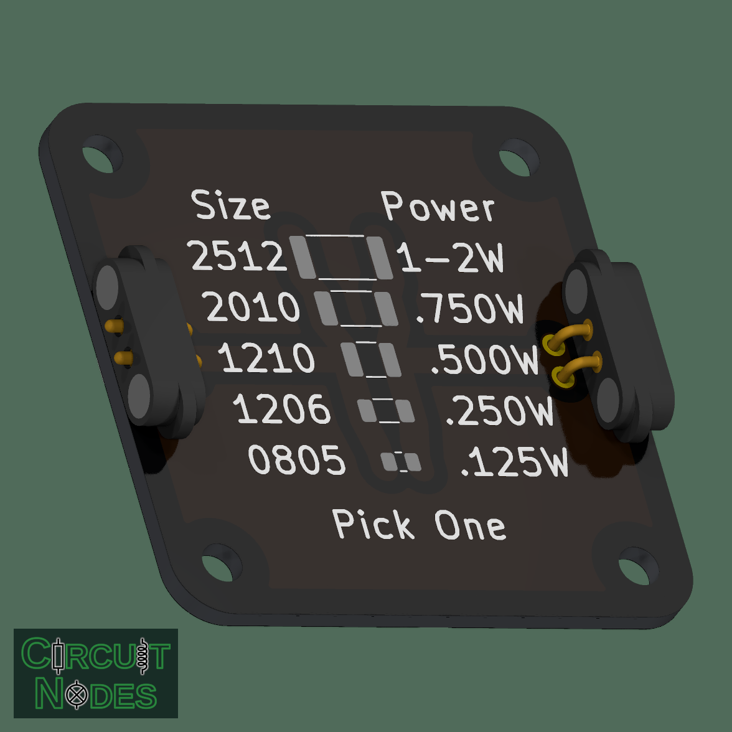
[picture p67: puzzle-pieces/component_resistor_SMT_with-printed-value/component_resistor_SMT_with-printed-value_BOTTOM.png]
      <td></td>
    </tr>
    <tr>
      <td><a href="https://github.com/probably-erwins-cat/Circuit-Nodes/tree/main/puzzle-pieces/component_resistor_THT_3W">Resistor THT 3W</a></td>
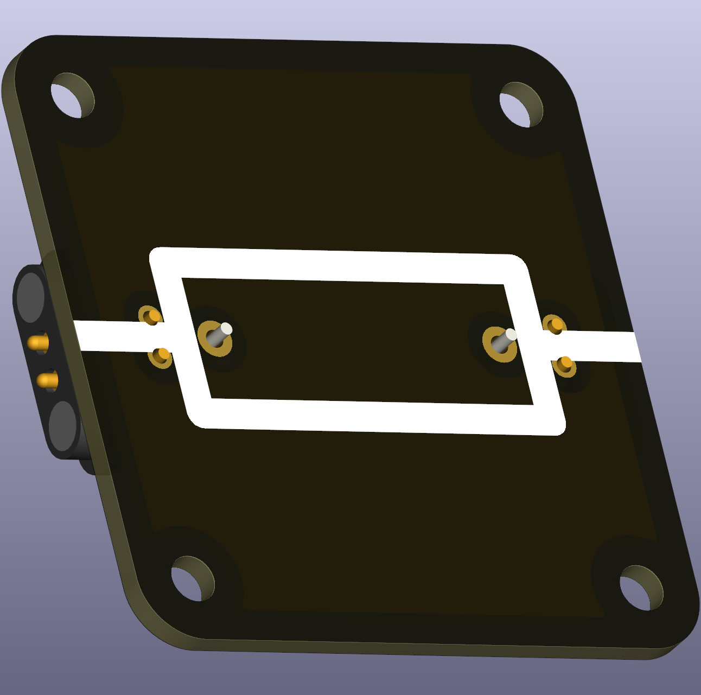
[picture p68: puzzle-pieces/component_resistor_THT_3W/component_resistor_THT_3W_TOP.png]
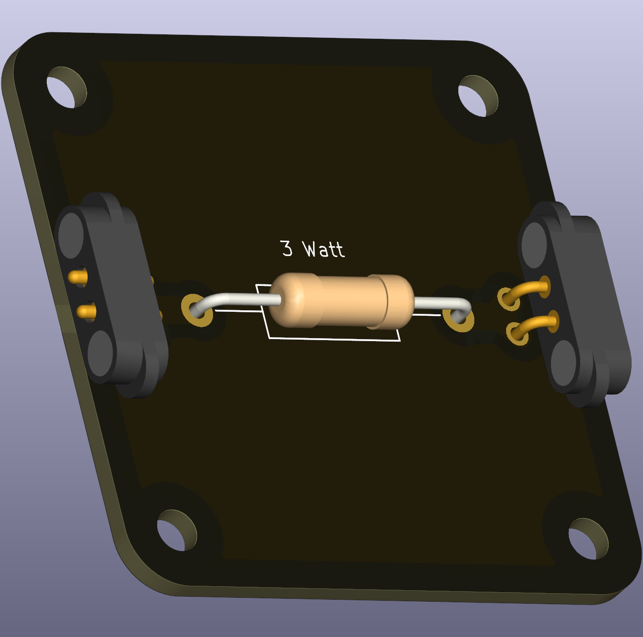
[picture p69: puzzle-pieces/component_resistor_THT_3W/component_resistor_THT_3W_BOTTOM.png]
      <td></td>
    </tr>
    <tr>
      <td><a href="https://github.com/probably-erwins-cat/Circuit-Nodes/tree/main/puzzle-pieces/component_resistor_THT_3W_with-printed-value">Resistor THT 3W With Printed Value</a></td>
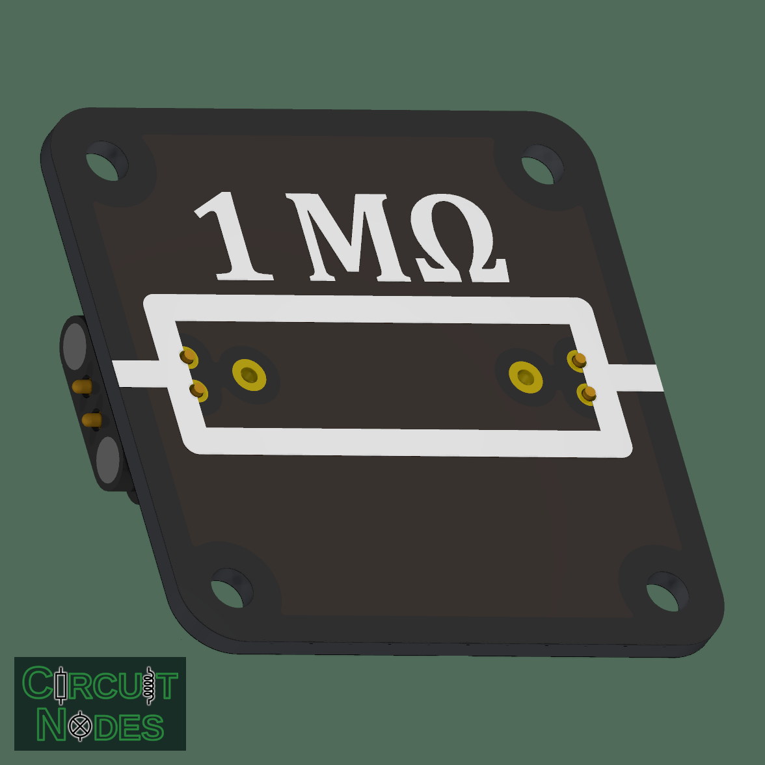
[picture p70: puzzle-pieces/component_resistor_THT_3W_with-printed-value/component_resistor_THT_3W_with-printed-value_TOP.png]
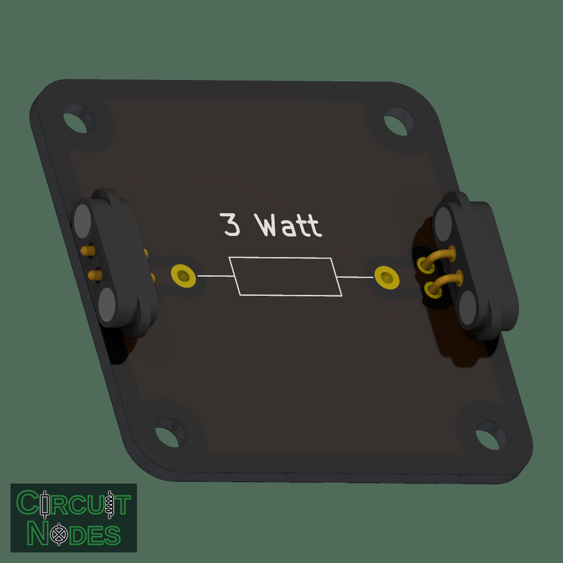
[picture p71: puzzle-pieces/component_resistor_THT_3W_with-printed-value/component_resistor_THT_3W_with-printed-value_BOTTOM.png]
      <td></td>
    </tr>
    <tr>
      <td><a href="https://github.com/probably-erwins-cat/Circuit-Nodes/tree/main/puzzle-pieces/component_switch-micro-Normally-Closed_THT">Switch Micro Normally Closed THT</a></td>
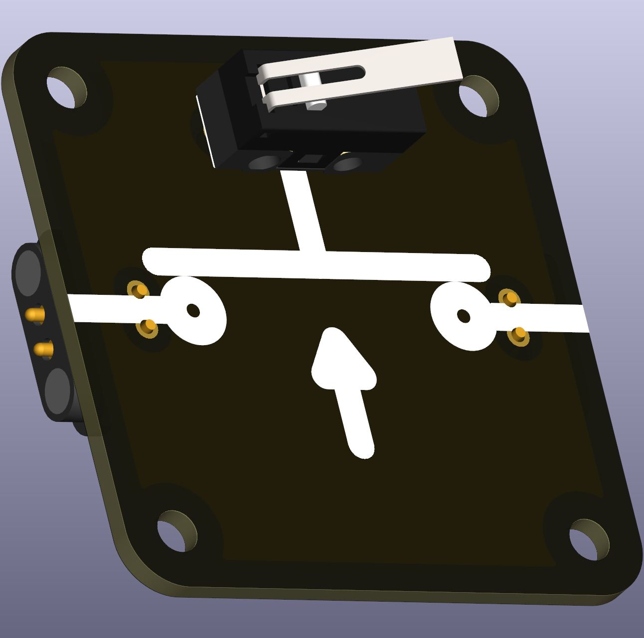
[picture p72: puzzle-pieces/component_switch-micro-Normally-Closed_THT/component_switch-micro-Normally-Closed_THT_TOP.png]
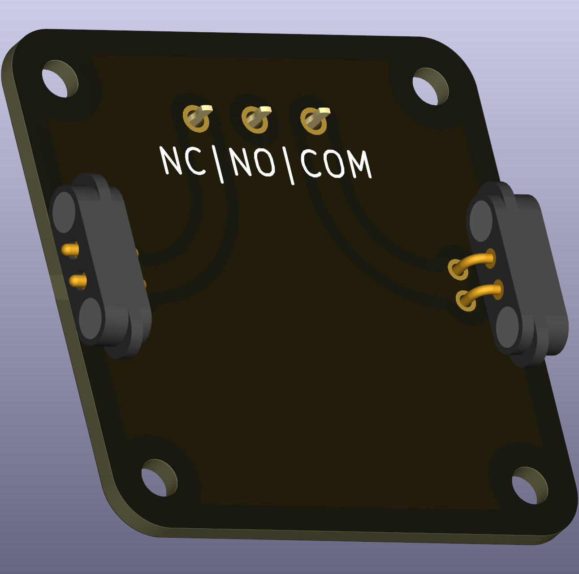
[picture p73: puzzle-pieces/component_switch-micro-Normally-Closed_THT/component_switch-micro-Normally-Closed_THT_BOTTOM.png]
      <td></td>
    </tr>
    <tr>
      <td><a href="https://github.com/probably-erwins-cat/Circuit-Nodes/tree/main/puzzle-pieces/component_switch-micro-Normally-Open_THT">Switch Micro Normally Open THT</a></td>
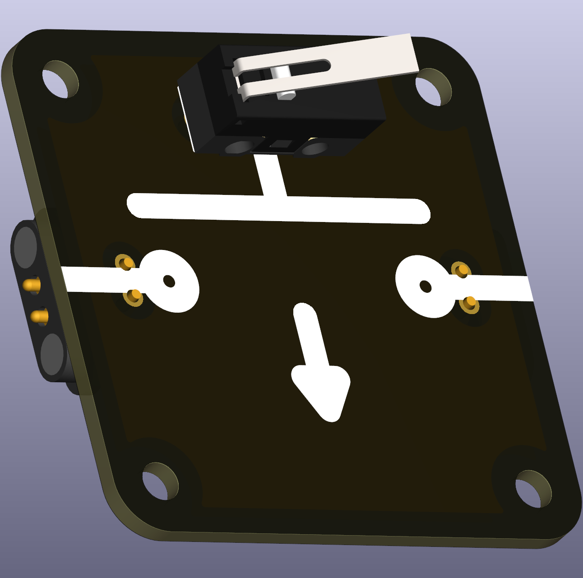
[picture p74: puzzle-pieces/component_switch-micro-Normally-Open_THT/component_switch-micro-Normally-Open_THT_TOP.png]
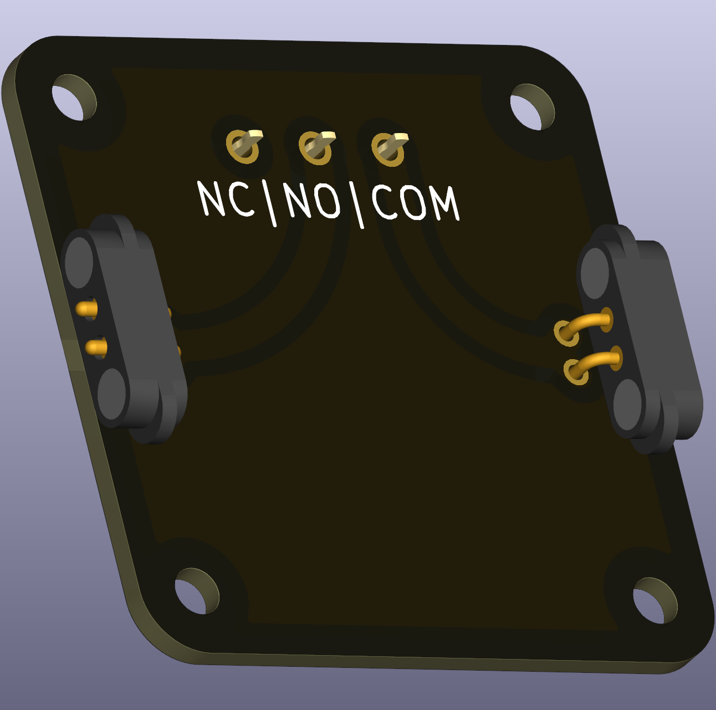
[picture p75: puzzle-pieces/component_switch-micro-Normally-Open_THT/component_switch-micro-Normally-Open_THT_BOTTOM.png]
      <td></td>
    </tr>
    <tr>
      <td><a href="https://github.com/probably-erwins-cat/Circuit-Nodes/tree/main/puzzle-pieces/component_switch-On1-OFF-On2_THT">Switch On1 OFF On2 THT</a></td>
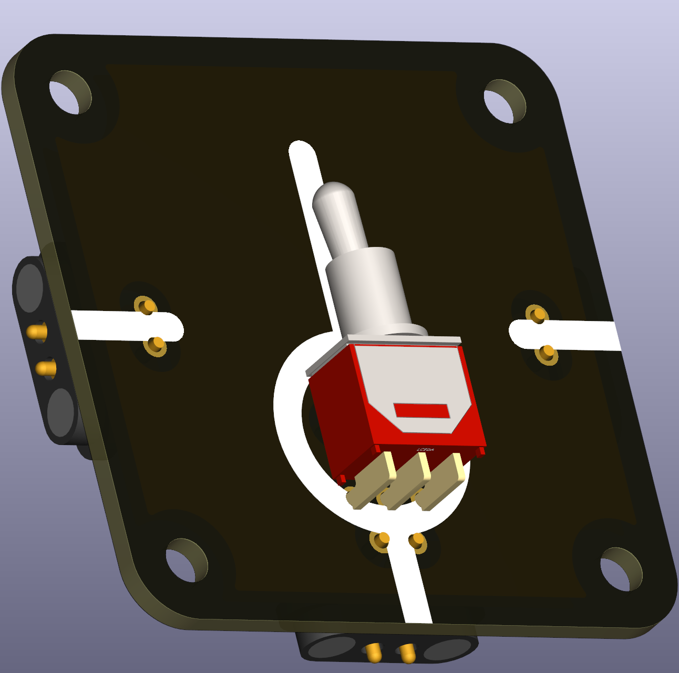
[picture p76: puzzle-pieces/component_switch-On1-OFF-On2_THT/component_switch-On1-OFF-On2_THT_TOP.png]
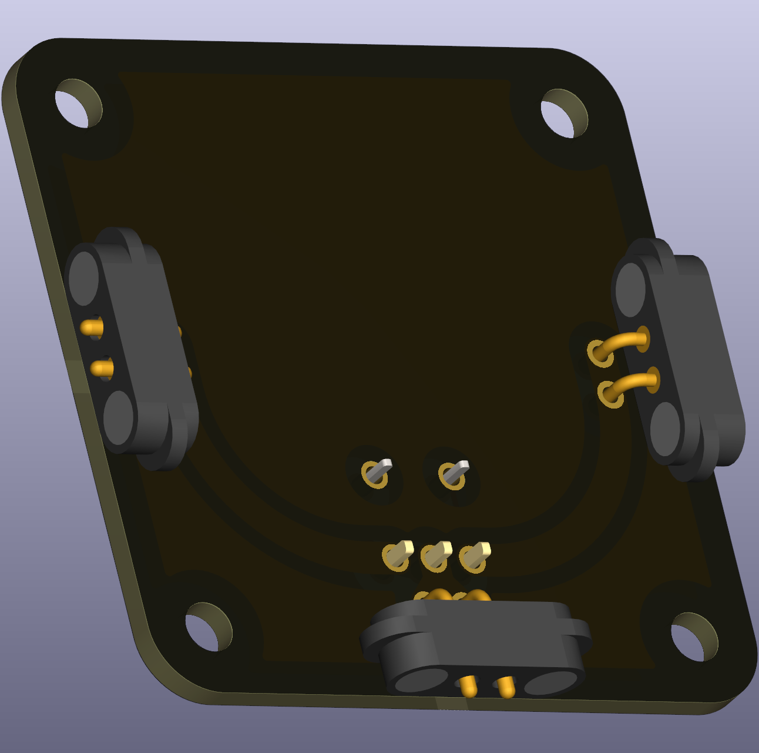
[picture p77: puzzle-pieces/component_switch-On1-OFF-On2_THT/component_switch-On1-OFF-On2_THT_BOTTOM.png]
      <td></td>
    </tr>
    <tr>
      <td><a href="https://github.com/probably-erwins-cat/Circuit-Nodes/tree/main/puzzle-pieces/component_switch-On1-On2_THT">Switch On1 On2 THT</a></td>
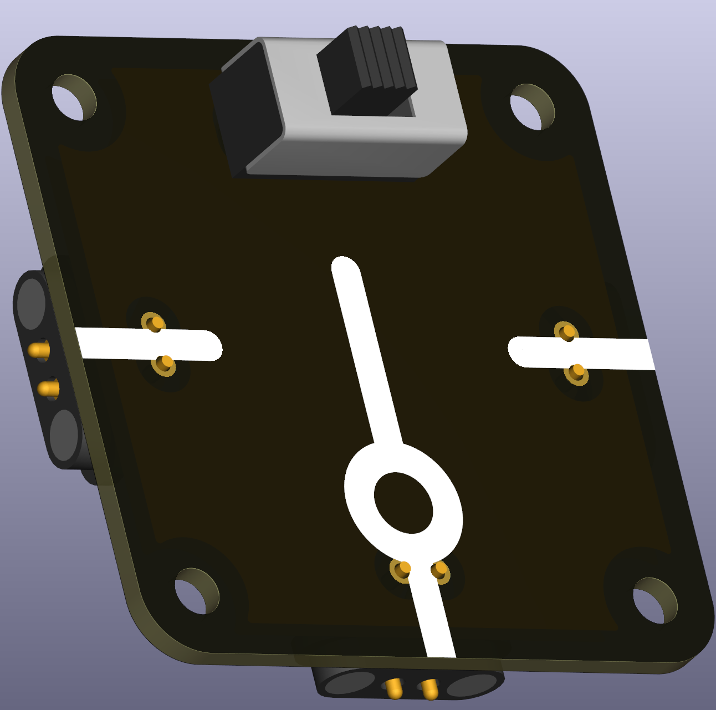
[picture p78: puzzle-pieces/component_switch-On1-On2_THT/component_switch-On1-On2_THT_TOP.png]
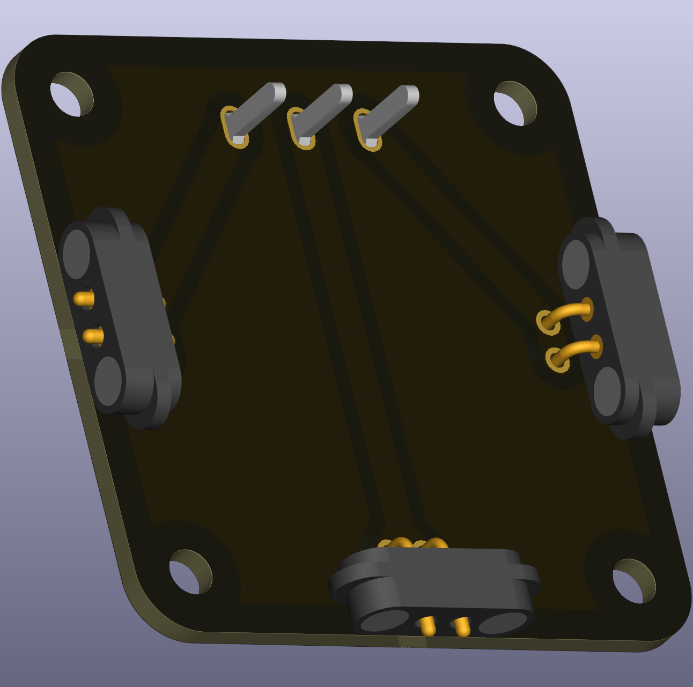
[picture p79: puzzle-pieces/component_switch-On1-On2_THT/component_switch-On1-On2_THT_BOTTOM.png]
      <td></td>
    </tr>
    <tr>
      <td><a href="https://github.com/probably-erwins-cat/Circuit-Nodes/tree/main/puzzle-pieces/component_switch-On-OFF_THT">Switch ON OFF THT</a></td>
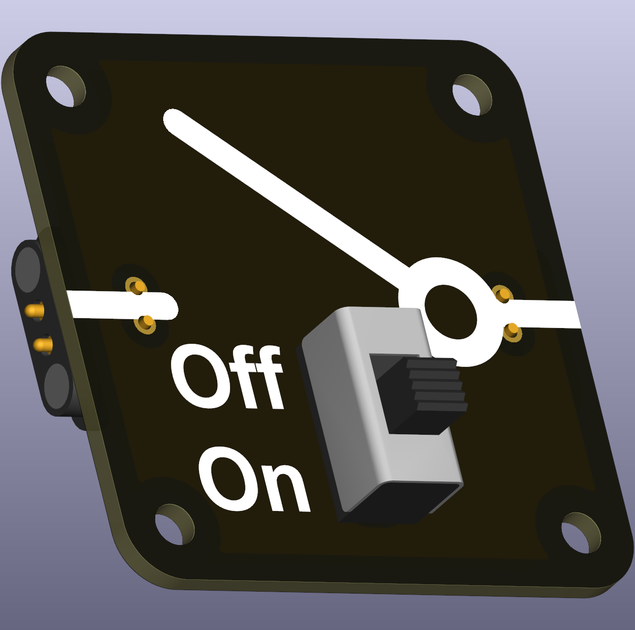
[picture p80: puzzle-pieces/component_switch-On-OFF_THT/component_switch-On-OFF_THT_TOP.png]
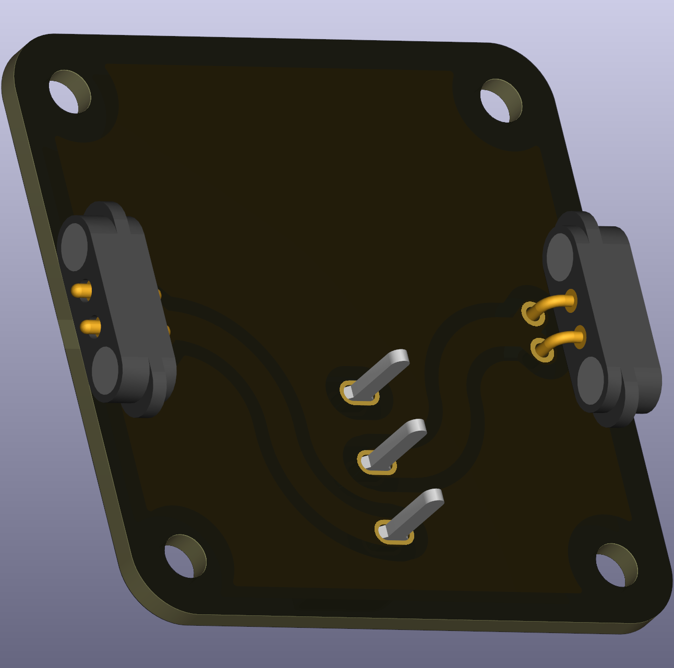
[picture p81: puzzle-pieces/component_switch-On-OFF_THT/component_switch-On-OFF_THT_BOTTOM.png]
      <td></td>
    </tr>
    <tr>
      <td><a href="https://github.com/probably-erwins-cat/Circuit-Nodes/tree/main/puzzle-pieces/component_switch-tactile-Normally-Open_THT">Switch Tactile Normally Open THT</a></td>
      <td></td>
    </tr>
    <tr>
      <td><a href="https://github.com/probably-erwins-cat/Circuit-Nodes/tree/main/puzzle-pieces/end-node-double_AC">End Node Double AC</a></td>
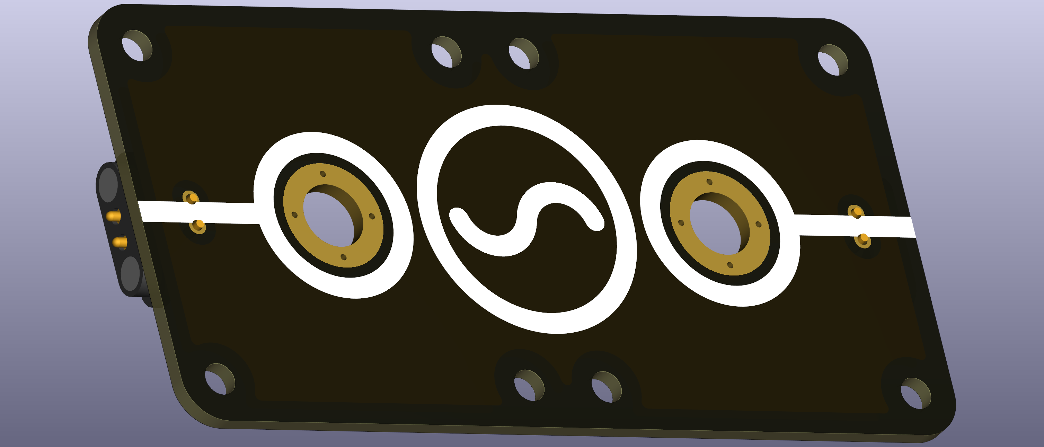
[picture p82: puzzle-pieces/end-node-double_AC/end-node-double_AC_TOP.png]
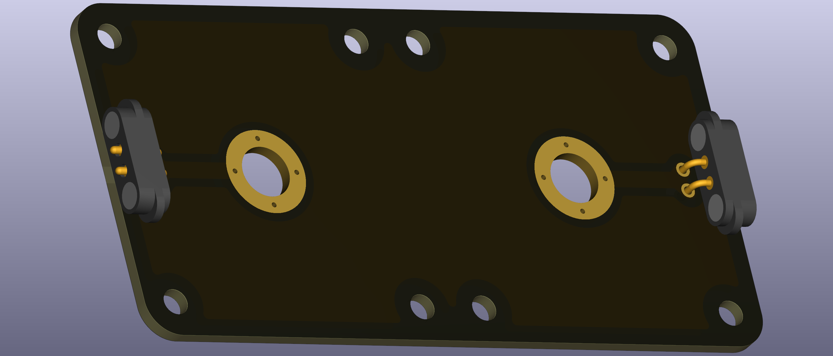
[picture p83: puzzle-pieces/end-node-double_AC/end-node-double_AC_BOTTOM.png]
      <td></td>
    </tr>
    <tr>
      <td><a href="https://github.com/probably-erwins-cat/Circuit-Nodes/tree/main/puzzle-pieces/end-node-double_blank">End Node Double Blank</a></td>
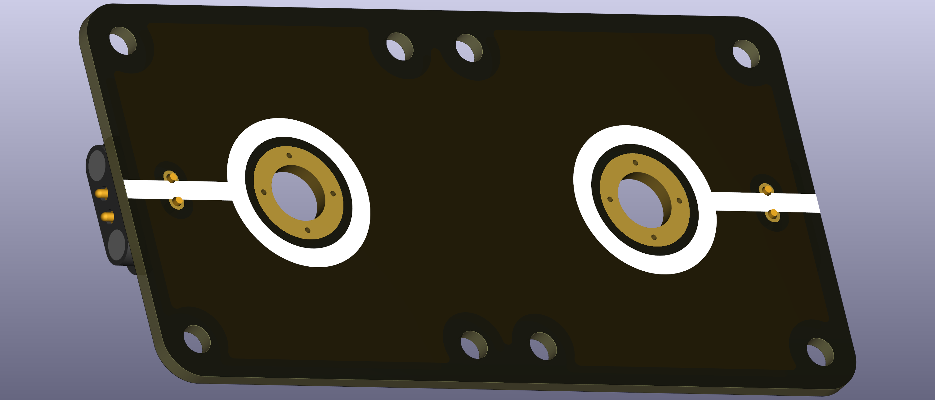
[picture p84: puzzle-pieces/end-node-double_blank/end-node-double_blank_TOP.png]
      <td></td>
    </tr>
    <tr>
      <td><a href="https://github.com/probably-erwins-cat/Circuit-Nodes/tree/main/puzzle-pieces/end-node-double_current">End Node Double Current</a></td>
      <td></td>
    </tr>
    <tr>
      <td><a href="https://github.com/probably-erwins-cat/Circuit-Nodes/tree/main/puzzle-pieces/end-node-double_plus-minus">End Node Double Plus Minus</a></td>
      <td></td>
    </tr>
    <tr>
      <td><a href="https://github.com/probably-erwins-cat/Circuit-Nodes/tree/main/puzzle-pieces/end-node-double_plus-minus_with-protection">End Node Double Plus Minus With Protection</a></td>
      <td></td>
    </tr>
    <tr>
      <td><a href="https://github.com/probably-erwins-cat/Circuit-Nodes/tree/main/puzzle-pieces/end-node-double_plus-minus_with-USB-PD">End Node Double Plus Minus With USB PD</a></td>
      <td></td>
    </tr>
    <tr>
      <td><a href="https://github.com/probably-erwins-cat/Circuit-Nodes/tree/main/puzzle-pieces/end-node-single_blank">End Node Single Blank</a></td>
      <td></td>
    </tr>
    <tr>
      <td><a href="https://github.com/probably-erwins-cat/Circuit-Nodes/tree/main/puzzle-pieces/end-node-single_minus">End Node Single Minus</a></td>
      <td></td>
    </tr>
    <tr>
      <td><a href="https://github.com/probably-erwins-cat/Circuit-Nodes/tree/main/puzzle-pieces/end-node-single_plus">End Node Single Plus</a></td>
      <td></td>
    </tr>
    <tr>
      <td><a href="https://github.com/probably-erwins-cat/Circuit-Nodes/tree/main/puzzle-pieces/wire-angle_blank">Wire Angle Blank</a></td>
      <td></td>
    </tr>
    <tr>
      <td><a href="https://github.com/probably-erwins-cat/Circuit-Nodes/tree/main/puzzle-pieces/wire-angle_node-voltage">Wire Angle Node Voltage</a></td>
      <td></td>
    </tr>
    <tr>
      <td><a href="https://github.com/probably-erwins-cat/Circuit-Nodes/tree/main/puzzle-pieces/wire-bridge_blank">Wire Bridge Blank</a></td>
      <td></td>
    </tr>
    <tr>
      <td><a href="https://github.com/probably-erwins-cat/Circuit-Nodes/tree/main/puzzle-pieces/wire-straight_blank">Wire Straight Blank</a></td>
      <td></td>
    </tr>
    <tr>
      <td><a href="https://github.com/probably-erwins-cat/Circuit-Nodes/tree/main/puzzle-pieces/wire-straight_node-voltage">Wire Straight Node Voltage</a></td>
      <td></td>
    </tr>
    <tr>
      <td><a href="https://github.com/probably-erwins-cat/Circuit-Nodes/tree/main/puzzle-pieces/wire-T-crossing_blank">Wire T Crossing Blank</a></td>
      <td></td>
    </tr>
    <tr>
      <td><a href="https://github.com/probably-erwins-cat/Circuit-Nodes/tree/main/puzzle-pieces/wire-T-crossing_node-voltage">Wire T Crossing Node Voltage</a></td>
      <td></td>
    </tr>
    <tr>
      <td><a href="https://github.com/probably-erwins-cat/Circuit-Nodes/tree/main/puzzle-pieces/wire-two-angles_blank">Wire Two Angles Blank</a></td>
      <td></td>
    </tr>
    <tr>
      <td><a href="https://github.com/probably-erwins-cat/Circuit-Nodes/tree/main/puzzle-pieces/wire-X-crossing_blank">Wire X Crossing Blank</a></td>
      <td></td>
    </tr>
    <tr>
      <td><a href="https://github.com/probably-erwins-cat/Circuit-Nodes/tree/main/puzzle-pieces/wire-X-crossing_node-voltage">Wire X Crossing Node Voltage</a></td>
      <td></td>
    </tr>
  </tbody>
</table>
---

## Storage & Organization

When ordering components in bulk (to reduce cost), a proper storage system becomes essential. The repository includes **parametric 3D models for a stackable PCB storage system**:

- **Window display**: See all stored components at a glance
- **Stackable design**: Compact vertical storage for many components
- **Parametric sizing**: Customize dimensions via CAD variables:
  - `int_width`: number of columns
  - `int_length`: storage container length
  - `int_multiplier`: PCB width scaling (1 or 2)

Print multiple storage bins and stack them to easily organize and access your entire component library. This is particularly useful for classroom settings where sets need to be sorted and quickly retrieved.

See the `PCB-storage-system` folder in the repository for complete design files.

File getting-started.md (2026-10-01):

---
layout: default
title: Getting Started
---

# Getting Started

## The Basic Concept

Circuit Nodes are modular PCBs that snap together on a square grid to form real circuits. This page gives a quick overview before you move on.
Each puzzle piece is a PCB with a single component; the edges carry magnets that provide both the mechanical and electrical connection. Modules are arranged on a grid and the schematic symbol is printed on the board so the layout matches the diagram.

Research shows that translating between flat schematics and messy physical builds is a major obstacle in school circuits. Circuit Nodes remove that step: the arrangement pupils draw is the arrangement they build, so they can concentrate on the physics.

## Components

Assembly overview

## Practical Examples

Circuit Nodes can be combined from individual modules into complete circuits:

Various node modules

Wire segments and junctions make it easy to shape the circuit layout:

Wire segment examples

Functional elements such as switches, lamps, LEDs, capacitors, and advanced components complete the circuit:

Functional node set

### 1. **Puzzle Pieces (PCBs)**
Small circuit boards with:
- Active components (resistors, LEDs, switches, etc.)
- Passive components (wire traces, connections)
- Schematic diagram printed on the silkscreen
- manufacturing files conveniendly provided here

LED puzzle piece front side preview

### 2. **3D-Printed Bases**
Frame that holds the PCB with:
- Interlocking puzzle-like edges
- Pockets for magnetic connectors
- M2 screw mounting points
- Various style options (open-bottom, magnetic-bottom)
- also provided here as STL, STEP and FreeCAD source file

Printable base preview

### 3. **Magnetic Connectors**
Small magnetig connectors found in detachable charging cables that:
- Provide physical attachment between pieces
- Act as electrical contacts for circuit connections
- Enable quick assembly and disassembly

Magnetic connector preview

### 4. Further **Components**
Additional modules introduce core circuit elements:
- **Lamps** for visible load behavior and current draw
- **LEDs** for polarity-aware visual feedback
- **Resistors** to set current and divide voltage
- **Magnets** for optional magnetic base, ideal for blackboard use

Together, these parts let you build a wide range of beginner and intermediate analog circuit examples.

## Getting Your First Kit

Circuit Nodes design and manufacturing files are shared in this repository for
noncommercial use under [CC BY-NC-SA 4.0](https://github.com/probably-erwins-cat/Circuit-Nodes/blob/main/LICENSING.md).
Since there are many puzzle pieces and some are needed multiple times, such as
wires and measuring nodes, starting with a curated kit is recommended.

The DIY path is:
- Download Gerber files from the repository
- Order PCBs from a fabrication service
- Source magnetic connectors and screws
- Print the bases on a 3D printer
- Assemble following the detailed instructions

If DIY is not an option, then a manufacturing and assembly service is provided, see below.

### Curated, Pre‑Made Kits

Ready‑made sets are offered at different levels, approximately aiming for different educational levels/classes.

*this section is under construction* 

- Entry‑level kit – power, basic modules for lamps and switches
- Intermediate kit – adds measurement nodes, resistors and LEDs
- Advanced kit – full classroom curriculum set

### Build Your Own, Expand your Collection

When you already have a set of circuit nodes with wires, junctions, banana terminals and switches, then you can easily expand your kit by adding components your are interested in.

Head over to the puzzle piece folder of the repository and search the list for the the components your are interested in. If you cannot find a certain component, then create a issue/discussion and the component will be designed for you.

### Ask for Manufacturing and Assembly Service 

Ordering PCB and assemblying Circuit Nodes might be too overwhelming and time-consuming for some. We offer Manufacturing and Assembly Services at Leipzig University at cost neutral level. Reach out to us.

## What You'll Need for Assembly

To start using Circuit Nodes:

### Minimum Setup
- **PCBs** - At least 3-5 basic pieces to form a simple circuit
- **3D-Printed Bases** - One per PCB
- **Magnetic Connectors** - About 2 per piece (depending on connections needed)
- **M2 Screws** - 4 per base (self-tapping or with heat inserts)
- **banana terminals** - for measuring voltage and current at given nodes
- **Power Source** - USB-C PD or benchtop supply depending on circuit and PCBs

## Next Steps

- **To build circuits**: Continue to [Assembly Instructions](assembly-instructions)
- **To explore components**: Check out [Component Guide](component-guide)
- **To understand base options**: See [Printable Bases](printable-bases)
- **To learn manufacturing**: Read [Sourcing & Manufacturing](sourcing-manufacturing)

---

**Have questions?** Open an issue or discussion on GitHub.

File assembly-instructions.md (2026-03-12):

---
layout: default
title: Assembly Instructions
---

# Assembly Instructions

## Overview

This guide walks you through assembling Circuit Nodes from individual components. Whether you're building from scratch or preparing a pre-made kit, these steps apply.

Below are the three parts that come together: the printed base, a magnetic connector, and a populated PCB.

Assembly explosion view

### Pre‑Assembly

Prepare your PCB by soldering the required components. Double‑check the
silkscreen for correct orientation and values. Trim leads and clean flux
residue. A quick continuity check with a multimeter catches shorts before the
board is placed in its base.

You will need:

- populated PCB
- printed base (match the tolerance test)
- 4× M2 self-tapping screws (optionally heat inserts)
- magnetic pogo connector
- soldering iron, solder, and basic hand tools
- multimeter for verification

### 1. Base Preparation

Take a few printable bases and check if the can be plugged into each other without too much friction. Remove print defects such as floating filament pieces from bridging that can interfer with the fitting of the parts.

### 2. Magnetic Pogo Connector

Insert the corresponding number of magnetic pogo connectors for the circuit node, e.g. two connectors on opposite sides for an LED, two adjacent connectors for an 90° angle, etc. *Removing a wrongly inserted magnetic connector can be difficult due to the tight clearances, be careful.*

*Sourcing*: Magnetic pogo connectors from LCSC, AliExpress, Taobao, or directly from the manufacturer *Samzo Components*. Look for 2-pin spring-loaded pogo connectors with integrated magnets and small wings for alignment and 2.54 pogo pin spacing. Note: this part can experience stock delays; plan ahead.

### 3. PCB Preparation

Solder components to PCB. PCB silkscreen indicates values and parts needed. Magnetic pogo connector can be soldered as a last step after assembly, so you do not have to worry about double-sided soldering. Check if the PCB benefits from reflow soldering.

### 4. Screws and Connector soldering

Hold the board in place and insert the four screws loosely. Once all screws are started, tighten them in a cross pattern until the board is seated; do not over‑torque. The PCB should lie flat and not shift when nudged. Lastly, solder the connector to the board (if not already done). 

That's it – the module is assembled.

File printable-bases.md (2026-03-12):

---
layout: default
title: Printable Bases
---

# Printable Bases

The printable base provides mounting for all parts and helps aligning the puzzle pieces. The printable base weights approx. 10 grams and carries a few design details that support assembly. 

Printable base preview

## Files & Tools

- All base models are in **FreeCAD** format (`.FCStd`) in the
  `printable-bases` folder of the repository.
- All common parts already exported as STL and STEP for immediate printing
- The *Open* design is for easier repairability without disassembly and better stackability
- The *Magnetic* variant is for enclosing sensitive components in the inside of the part and for optional magnet holder (blackboard use)

## Print Parameters

*The printable base is highly optimized for perimeter printing*, i.e. the slicer will generate 90%+ perimeters and 10%- infill etc., thus, many settings are unimportant. Use these general settings:

- Layer height:   0.20 mm
- Wall (perimeter): 2 shells
- top and bottom layers: 10
- Infill: 100 % (for filling the few small non-perimeter-wall sections)
- Support: not required

## Preparation before Batch Printing: Tolerances & Test Print

*FIRST PRINT* a tolerance tester piece (folder [`tolerance-tester/`](https://github.com/probably-erwins-cat/Circuit-Nodes/tree/main/tolerance-tester))
containing one screw hole and one magnet connector tester. These parts summarize all tolerance/clearance classes so you can verify your printer capabilities. *There is nothing worse, than batch printing bases and figuring out they do not met the criterion for good assembly and alignment.* The test parts are quickly printed.

### Screw Hole Tolerance

Screw tolerance tester

The screw hole tester is an oriented part that habors ten holes with increasing diameter in 0.05mm increments. A side hole marks the imperically found best hole size for the average printer and the typical needed bore size of self-tapping M2 screws, 1.95mm. 
The available STL and STEP models are designed with 1.95mm holes in mind, which gives self-tapping screws the right amount of freedom to form threads into the plastic and the deformed plastic filling the gaps between the threads.
However, you might find that choosing a hole size slightly larger or bigger to suit your printer model and filament choice better.

Screw in M2 screws in every hole and determine which screw size feels best. *When to tight*, the screw strips or the screwdriver cams out and rounds the screw head. *When too loose*, the screw  strips the plastic when over tightening the PCB down to the printable base.

If you find yourself, for instance, that 1.95mm is too tight for the screw and 2.05mm feels significantly better, then you can use the hole compensation feature of your slicer to enlarge the 1.95mm hole to 2.05mm, i.e. hole compensation +0.1mm.

### Connector Pocket Tolerance

Connector tolerance tester

Four tolerance classes are provided per default for the magnetic connector pocket:

| Dimension | Clearance | 
|---|---|
| 0.10 mm | tight fit, for very precise printers or when minor underextruding happens |
| 0.15 mm | normal fit, **start here** |
| 0.20 mm | looser fit, easier insertion |
| 0.25 mm | loose fit, when printer overextrudes when printhead is cornering |

Ideally, the magnetic connector fits in 0.15mm clearance pocket by gently pressing it in with your fingers, so the magnetic connector cannot wiggle in its pocket. If you need a plier to press it in, then it is too tight.
If none of those clearances work for you, you should first look into calibrating your printer. 

### Base Alignment Nose Tolerance

The hexagonal protrusion and indentation helps aligning the bases, so the magnetic connectors connect flush. Therefore, the tolerance should be chosen small enough for excellent alignment and wide enough so the parts can slide virtually frictionless. A tolerance of 0.2mm is is typically sufficient (making it slightly less than 0.4mm clearance in total) and is in reach of all recent printers. 

## Batch printing

A standard size printer can carry 20 - 25 bases on one print plate. One base is printed in less than an hour, thus, one print plate is printed in less than a day.

You can either batch print the bases in an over-night print job or head over to [Sourcing & Manufacturing](sourcing-manufacturing), where you can find hubs that help you sourcing printable bases.

---

That's all you need for the “printable bases” step.  Next, move on to
[Assembly Instructions](assembly-instructions) where the PCBs, magnets and
screws are brought together.

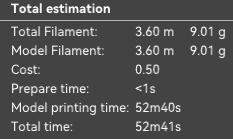
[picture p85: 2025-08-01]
images/print-time-single-printable-base.png

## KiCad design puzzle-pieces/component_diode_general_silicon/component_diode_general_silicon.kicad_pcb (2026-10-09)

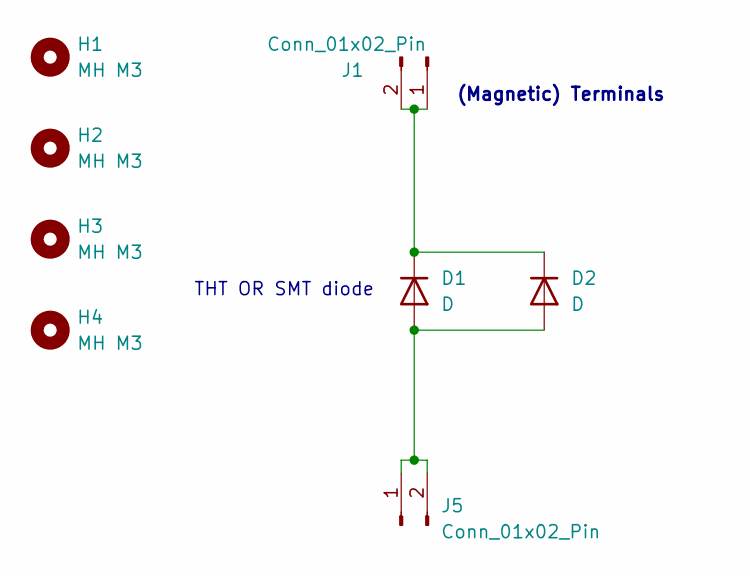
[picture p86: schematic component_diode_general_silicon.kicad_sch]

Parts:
D1: D; D_DO-15_P12.70mm_Horizontal
D2: D; D_SMA-SMB_Universal_Handsoldering
H1, H2, H3, H4: MH M3; MountingHole_3.0mm_M3_tight
J1, J5: Conn_01x02_Pin; Magnetic_Connector_1x02_P2.5mm_Horizontal_round-ears

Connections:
unnamed: D1.2 (A), D2.2 (A), J5.1, J5.2
unnamed: D1.1 (K), D2.1 (K), J1.1, J1.2

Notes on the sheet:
(Magnetic) Terminals
THT OR SMT diode

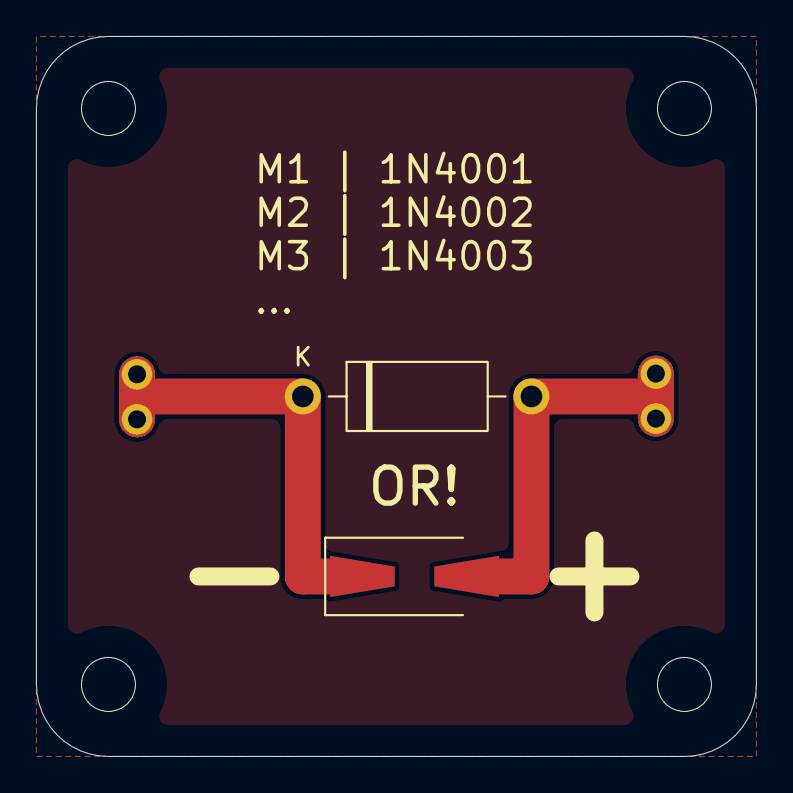
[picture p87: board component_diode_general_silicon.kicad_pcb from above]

Board: 2 copper layers, 40.0 x 40.0 mm, 8 parts (0 on the bottom side), 2 nets.

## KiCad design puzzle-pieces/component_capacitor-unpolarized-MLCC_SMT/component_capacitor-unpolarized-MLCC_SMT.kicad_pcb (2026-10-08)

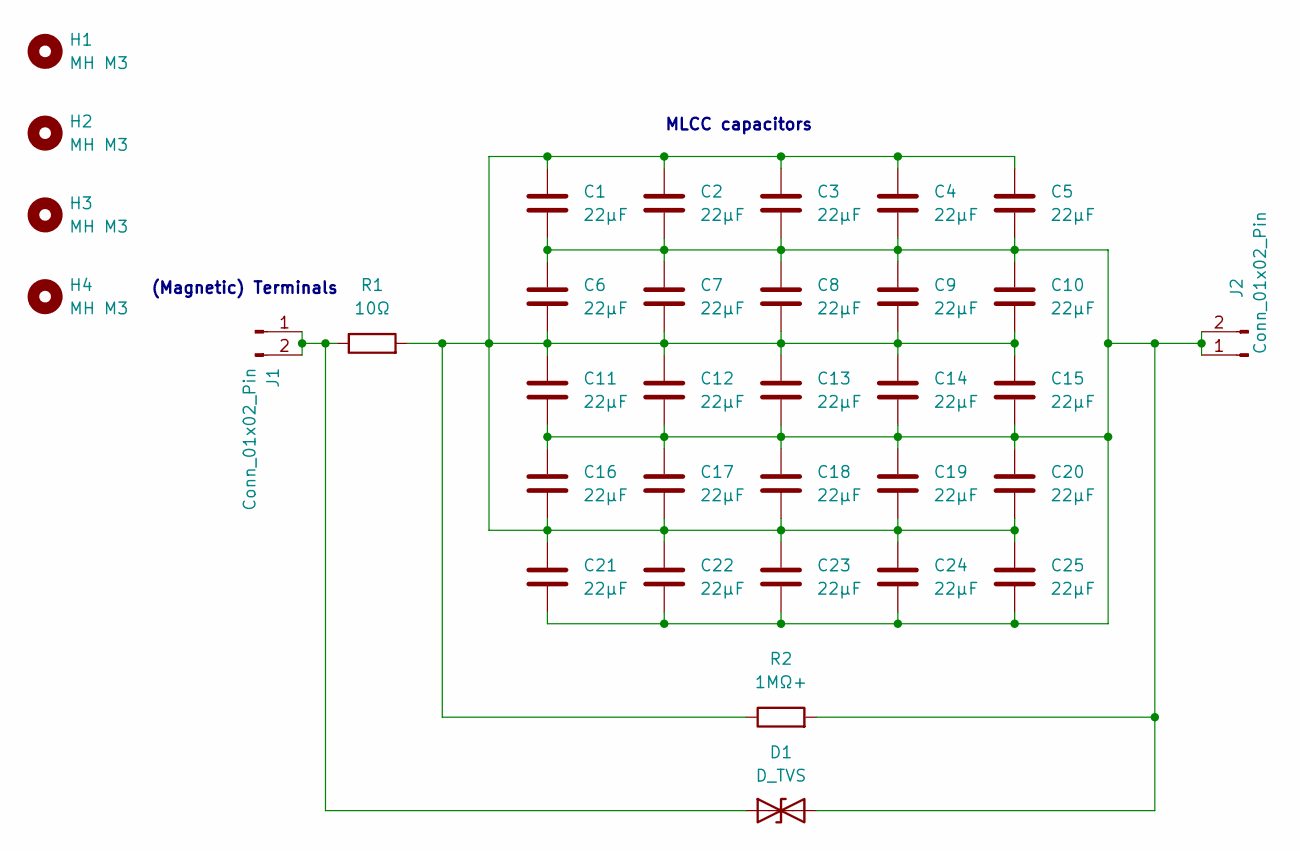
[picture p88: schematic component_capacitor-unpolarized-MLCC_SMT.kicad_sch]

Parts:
C1, C2, C3, C4, C5, C6, C7, C8, C9, C10, C11, C12, C13, C14, C15, C16, C17, C18, C19, C20, C21, C22, C23, C24, C25: 22µF; C_1206_3216Metric_Pad1.33x1.80mm_HandSolder; LCSC C12891
D1: D_TVS; D_SOD-323_HandSoldering; LCSC C503381
H1, H2, H3, H4: MH M3; MountingHole_3.0mm_M3_tight
J1, J2: Conn_01x02_Pin; Magnetic_Connector_1x02_P2.5mm_Horizontal_round-ears
R1: 10Ω; R_1206_3216Metric_Pad1.30x1.75mm_HandSolder; LCSC C17903
R2: 1MΩ+; R_1206_3216Metric_Pad1.30x1.75mm_HandSolder; LCSC C26119

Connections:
unnamed: C1.1, C2.1, C3.1, C4.1, C5.1, C6.2, C7.2, C8.2, C9.2, C10.2, C11.1, C12.1, C13.1, C14.1, C15.1, C16.2, C17.2, C18.2, C19.2, C20.2, C21.1, C22.1, C23.1, C24.1, C25.1, R1.2, R2.1
unnamed: D1.1 (A1), J1.1, J1.2, R1.1
unnamed: C1.2, C2.2, C3.2, C4.2, C5.2, C6.1, C7.1, C8.1, C9.1, C10.1, C11.2, C12.2, C13.2, C14.2, C15.2, C16.1, C17.1, C18.1, C19.1, C20.1, C21.2, C22.2, C23.2, C24.2, C25.2, D1.2 (A2), J2.1, J2.2, R2.2

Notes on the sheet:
(Magnetic) Terminals
MLCC capacitors

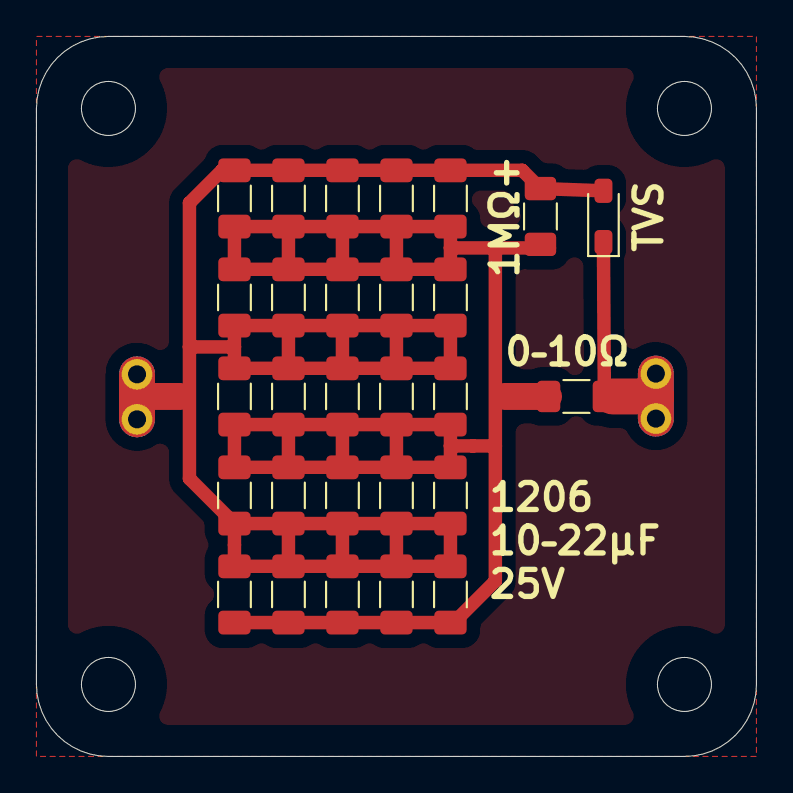
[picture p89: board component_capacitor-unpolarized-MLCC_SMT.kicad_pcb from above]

Board: 2 copper layers, 40.0 x 40.0 mm, 34 parts (0 on the bottom side), 3 nets.

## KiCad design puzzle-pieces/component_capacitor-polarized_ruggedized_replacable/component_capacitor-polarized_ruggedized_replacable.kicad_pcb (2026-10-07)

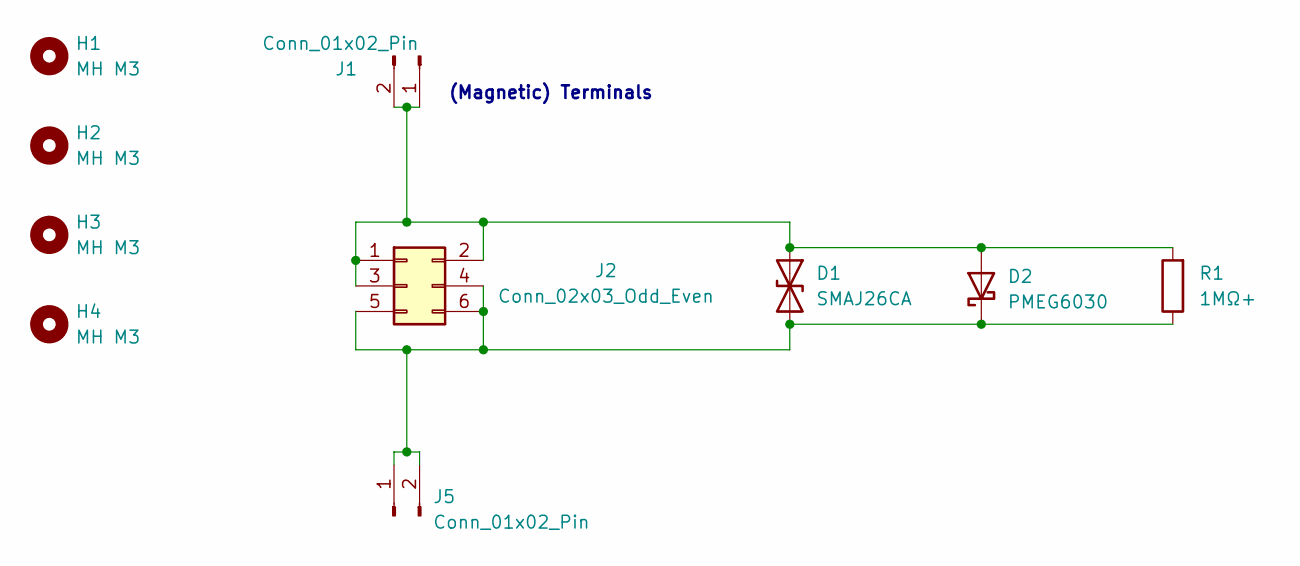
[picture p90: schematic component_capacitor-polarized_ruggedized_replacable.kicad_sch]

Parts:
D1: SMAJ26CA; D_SMA_Handsoldering; LCSC C908826
D2: PMEG6030; D_SOD-128; LCSC C53114036
H1, H2, H3, H4: MH M3; MountingHole_3.0mm_M3_tight
J1, J5: Conn_01x02_Pin; Magnetic_Connector_1x02_P2.5mm_Horizontal_round-ears
J2: Conn_02x03_Odd_Even; CONN-SMD_HC-PM254-5.0H-2X3PS-02A
R1: 1MΩ+; R_1206_3216Metric_Pad1.30x1.75mm_HandSolder; LCSC C7250

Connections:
unnamed: D1.1 (A1), D2.2 (A), J1.1, J1.2, J2.1, J2.2, J2.3, R1.2
unnamed: D1.2 (A2), D2.1 (K), J2.4, J2.5, J2.6, J5.1, J5.2, R1.1

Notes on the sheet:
(Magnetic) Terminals

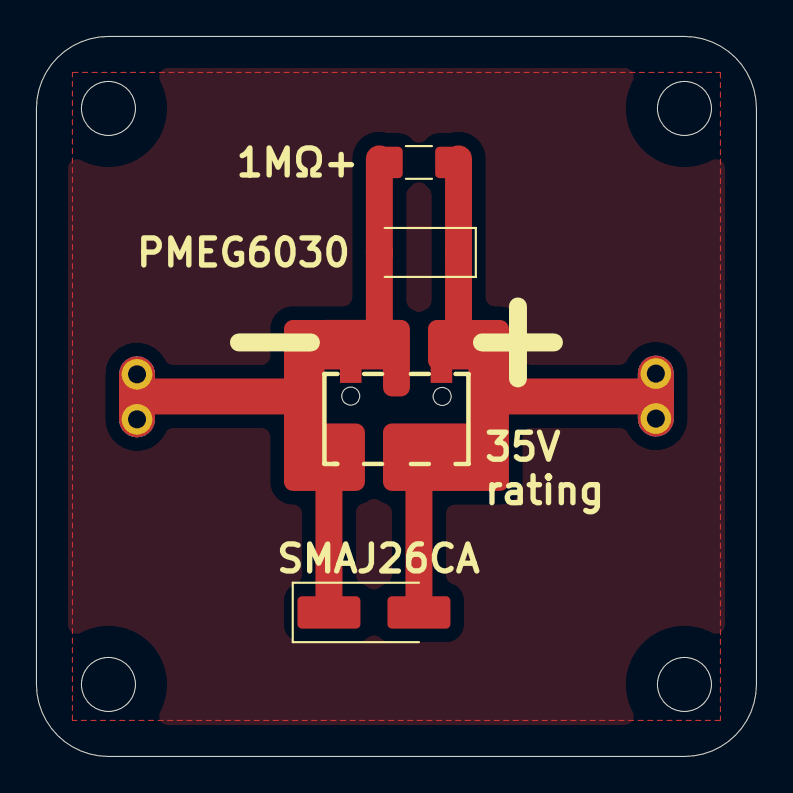
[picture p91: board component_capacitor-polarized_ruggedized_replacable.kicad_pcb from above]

Board: 2 copper layers, 40.0 x 40.0 mm, 10 parts (0 on the bottom side), 2 nets.

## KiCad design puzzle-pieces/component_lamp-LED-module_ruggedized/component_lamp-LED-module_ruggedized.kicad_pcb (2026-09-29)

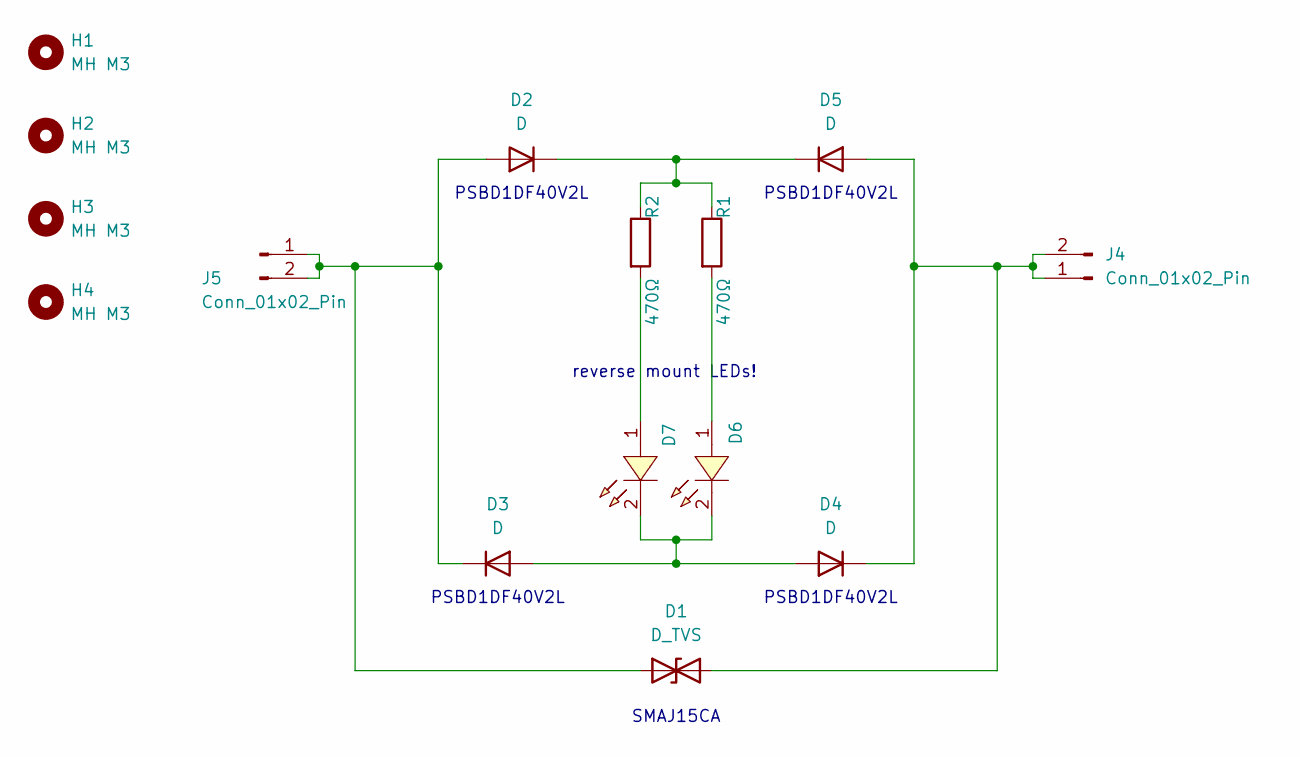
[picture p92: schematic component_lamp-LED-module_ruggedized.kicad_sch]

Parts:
D1: D_TVS; D_SMA_Handsoldering; LCSC C2848698
D2, D3, D4, D5: D; SOD-123FL_L2.8-W1.8-LS3.8-RD; LCSC C496544
D6, D7: XL-6028UGC-FB; LED-SMD_L3.2-W2.8-LS5.9_GT-6028W-1023; LCSC Part C3646964
H1, H2, H3, H4: MH M3; MountingHole_3.0mm_M3_tight
J4, J5: Conn_01x02_Pin; Magnetic_Connector_1x02_P2.5mm_Horizontal_round-ears
R1, R2: 470Ω; R_1206_3216Metric_Pad1.30x1.75mm_HandSolder

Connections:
unnamed: D1.1 (A1), D2.2 (A), D3.1 (K), J5.1, J5.2
unnamed: D1.2 (A2), D4.1 (K), D5.2 (A), J4.1, J4.2
unnamed: D2.1 (K), D5.1 (K), R1.1, R2.1
unnamed: D3.2 (A), D4.2 (A), D6.2, D7.2
unnamed: D6.1, R1.2
unnamed: D7.1, R2.2

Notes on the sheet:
PSBD1DF40V2L
SMAJ15CA
reverse mount LEDs!

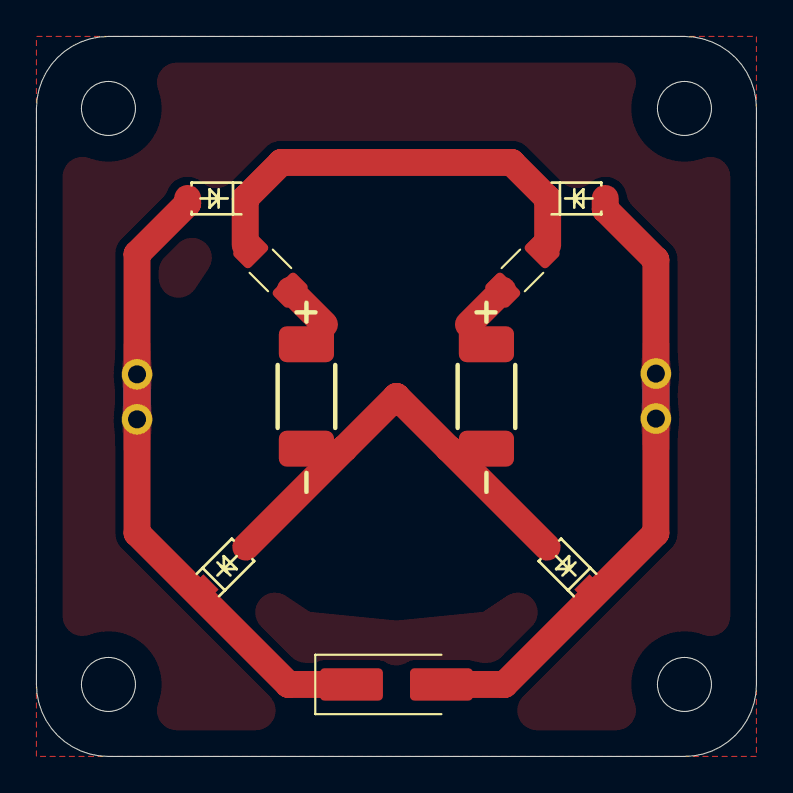
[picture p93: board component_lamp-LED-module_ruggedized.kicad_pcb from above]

Board: 2 copper layers, 40.0 x 40.0 mm, 15 parts (0 on the bottom side), 6 nets.

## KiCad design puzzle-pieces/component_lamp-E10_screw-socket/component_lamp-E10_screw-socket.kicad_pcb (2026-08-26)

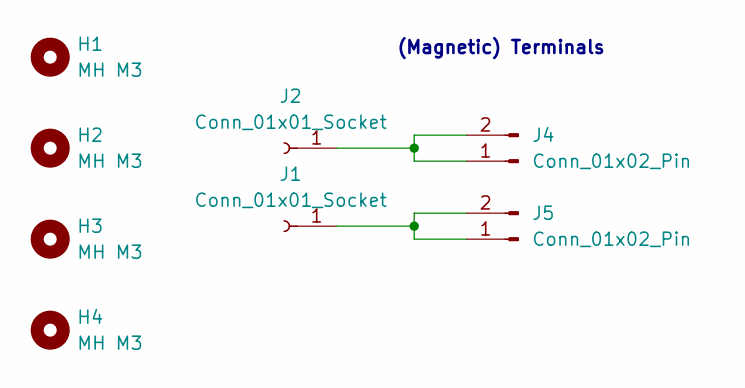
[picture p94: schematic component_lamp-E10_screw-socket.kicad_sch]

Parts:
H1, H2, H3, H4: MH M3; MountingHole_3.0mm_M3_tight
J1, J2: Conn_01x01_Socket; SolderWire-4sqmm_1x01_D3mm_OD6mm
J4, J5: Conn_01x02_Pin; Magnetic_Connector_1x02_P2.5mm_Horizontal_round-ears

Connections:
unnamed: J1.1 (Pin_1_1), J5.1, J5.2
unnamed: J2.1 (Pin_1_1), J4.1, J4.2

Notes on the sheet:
(Magnetic) Terminals

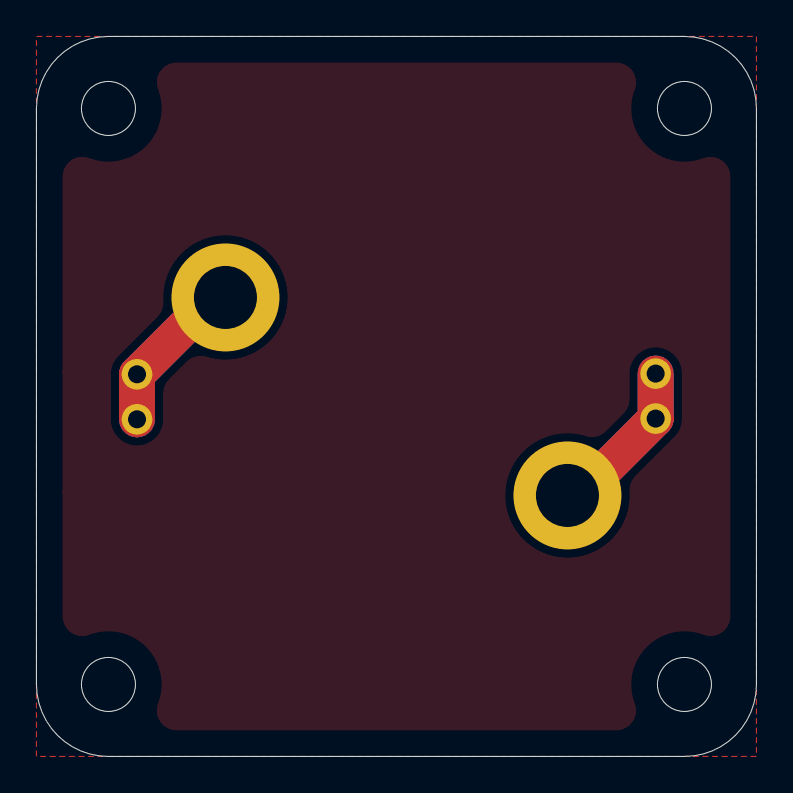
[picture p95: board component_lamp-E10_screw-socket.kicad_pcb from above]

Board: 2 copper layers, 40.0 x 40.0 mm, 8 parts (0 on the bottom side), 2 nets.

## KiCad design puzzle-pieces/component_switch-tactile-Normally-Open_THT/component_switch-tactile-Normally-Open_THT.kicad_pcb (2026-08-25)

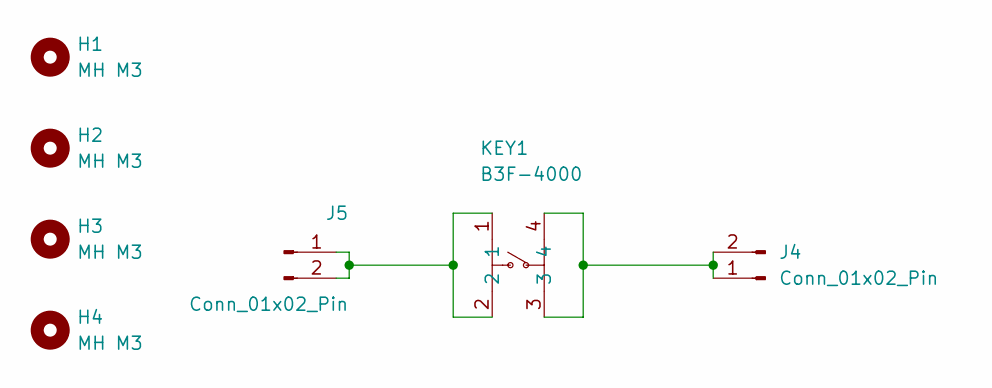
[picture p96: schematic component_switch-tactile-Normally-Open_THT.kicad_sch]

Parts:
H1, H2, H3, H4: MH M3; MountingHole_3.0mm_M3_tight
J4, J5: Conn_01x02_Pin; Magnetic_Connector_1x02_P2.5mm_Horizontal_round-ears
KEY1: B3F-4000; KEY-TH_4P-L12.0-W12.0-P5.00-LS13.4-EH; LCSC Part C87494

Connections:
unnamed: J4.1, J4.2, KEY1.3, KEY1.4
unnamed: J5.1, J5.2, KEY1.1, KEY1.2

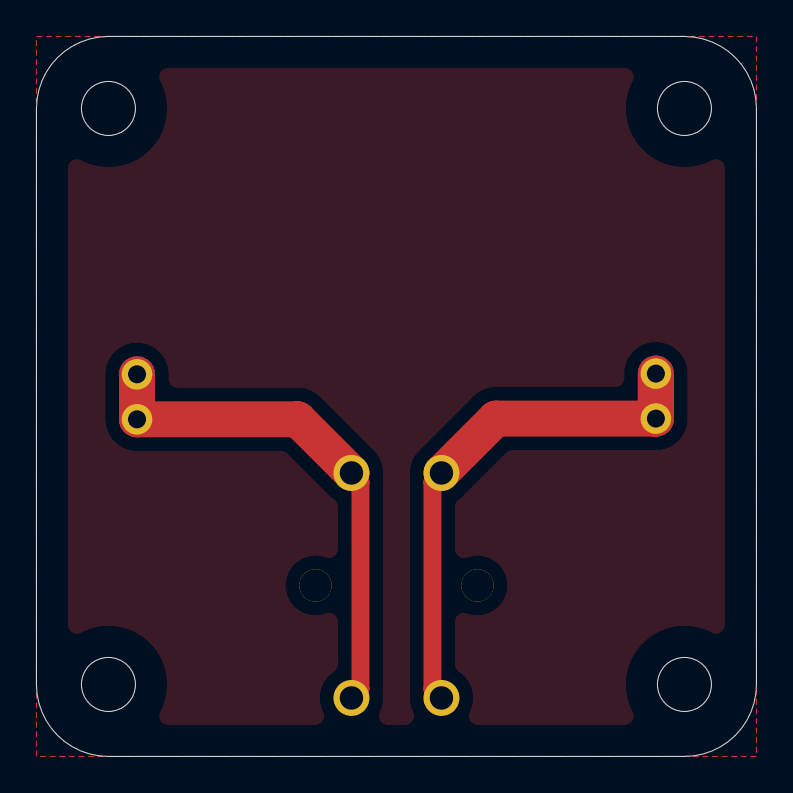
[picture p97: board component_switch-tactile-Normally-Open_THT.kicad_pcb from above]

Board: 2 copper layers, 40.0 x 40.0 mm, 7 parts (1 on the bottom side), 2 nets.

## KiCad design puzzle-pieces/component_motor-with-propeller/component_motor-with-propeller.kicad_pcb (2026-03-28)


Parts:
H1, H2, H3, H4, H5, H6, H7, H8: MH M3; MountingHole_3.0mm_M3_tight
J1, J2: Conn_01x02_Pin; Magentic_Connector_1x02_P2.5mm_Horizontal
M1: Motor_DC; motor-with-propeller

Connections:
unnamed: J1.1, J1.2, M1.1 (+)
unnamed: J2.1, J2.2, M1.2 (-)

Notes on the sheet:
(Magnetic) Terminals


Board: 2 copper layers, 80.0 x 40.0 mm, 11 parts (1 on the bottom side), 2 nets.

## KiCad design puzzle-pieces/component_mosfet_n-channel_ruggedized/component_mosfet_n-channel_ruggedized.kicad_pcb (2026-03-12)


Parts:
C1: 47nF; C_1206_3216Metric_Pad1.33x1.80mm_HandSolder; LCSC C303962
D1: 1N4148W; Nexperia_CFP3_SOD-123W; LCSC C81598
D2: 24V; D_SMA; LCSC C155317
DZ1: 5.1V; Nexperia_CFP3_SOD-123W; LCSC C2827905
H1, H2, H3, H4: MH M3; MountingHole_3.0mm_M3_tight
J1, J2, J5: Conn_01x02_Pin; Magnetic_Connector_1x02_P2.5mm_Horizontal_round-ears
Q1: NDT3055L; SOT-223-3_TabPin2; LCSC C5354979
Q2: UT3N06G; SOT-89-3_Handsoldering; LCSC C127044
R1: 220Ω; R_1206_3216Metric_Pad1.30x1.75mm_HandSolder; LCSC C17957
R2: 100kΩ; R_1206_3216Metric_Pad1.30x1.75mm_HandSolder; LCSC C17900

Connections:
unnamed: C1.2, D1.2 (A), D2.2 (A), DZ1.2 (A), J5.1, J5.2, Q1.3 (S), Q2.3 (S), R2.1
unnamed: C1.1, D1.1 (K), DZ1.1 (K), Q1.1 (G), Q2.1 (G), R1.2, R2.2
unnamed: D2.1 (K), J2.1, J2.2, Q1.2 (D), Q2.2 (D)
unnamed: J1.1, J1.2, R1.1

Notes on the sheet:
(Magnetic) Terminals



Board: 2 copper layers, 40.0 x 40.0 mm, 15 parts (4 on the bottom side), 4 nets.

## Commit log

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2025-07-16 Update capacitor image references and files
    Replaced 'capacitor-polarized_THT-general_TOP.png' and 'capacitor-polarized_THT-general_BOTTOM.png' with new images 'capacitor-polarized_THT_TOP.png' and 'capacitor-polarized_THT_BOTTOM.png'. Updated README to reference the new image filenames.
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2025-07-16 Update Zener diode THT component images
    Replaced the TOP and BOTTOM PNG images for the Zener diode THT component in the puzzle-pieces directory to reflect updated graphics or design.
2025-07-17 Update LED and end-node assets and documentation
    Replaced 5mm LED assets with generic LED assets and updated README references. Added banana jack image and improved documentation for end-node-double_current. Updated and replaced several component asset files and archives for consistency.
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2025-07-17 Update LED and capacitor SMT component files
    Updated PNG images and ZIP files for LED THT replacable SMT and capacitor-polarized THT replacable SMT components. Also fixed a filename typo for the 2.5mm capacitor ZIP file.
2025-07-17 Update puzzle piece component images
    Replaces PNG images for diode, lamp, switch, and end-node components in the puzzle-pieces directory. This may include visual improvements or corrections to the graphics used for these components.
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2025-07-28 Add SMT resistor, update docs, and enhance node visuals
    Added new SMT resistor component with documentation and images. Updated several README files to improve clarity and add banana jack visuals for end nodes and wire segments. Replaced and updated various component ZIP files, and improved descriptions for LED and node components.
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2025-11-20 Add SMT resistor with printed value puzzle pieces
    Introduces a new set of SMT resistor puzzle pieces with printed values, including KiCAD project files, images, and E-6 series zip archives for various resistor values. Also adds documentation describ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
    [component_resistor_SMT_with-printed-value.kicad_pcb, component_resistor_SMT_with-printed-value.kicad_sch]
2025-11-20 Add THT 3W resistor puzzle piece project
    Initial commit of through-hole 3W resistor puzzle piece project, including KiCAD PCB, schematic, project files, silkscreened value variants (E-6 series ZIPs), and documentation. Provides a range of r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
    [component_resistor_THT_3W_with-printed-value.kicad_pcb, component_resistor_THT_3W_with-printed-value.kicad_sch]
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2025-11-24 Add E-6 series SMT resistor panel files
    Added KiCad PCB, project, and production ZIP files for the E-6 series SMT resistor panel with printed values. Includes footprints for mounting holes and magnetic connectors.
    [whole_panel.kicad_pcb]
2025-11-25 Add PCB storage system and charge pump inverter files
    Initial commit of 3D models, documentation, and example image for the PCB storage system, as well as KiCad project files for the charge pump inverter component. These files provide mechanical and ele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
    [PCB-storage-system-tall.step, PCB-storage-system-tall.stl, PCB-storage-system.FCStd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]
2025-11-25 Update PCB storage and inverter component files
    Modified STEP and FreeCAD files for PCB storage system, updated .gitignore to include new backup patterns, and replaced charge-pump inverter KiCad files with new versions and documentation. Added PNG renders and a ZIP archive for the inverter component, reflecting a redesign or migration of project files.
    [PCB-storage-system-tall.step, PCB-storage-system.FCStd, PCB-storage-system.step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]
2025-12-04 Add THT slider potentiometer KiCad project
    Added a new through-hole slider potentiometer component including KiCad PCB, schematic, project files, images, and documentation. This provides a ready-to-use module for educational and prototyping p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
    [component_potentiometer_slider_THT.kicad_pcb, component_potentiometer_slider_THT.kicad_sch]
2025-12-05 Add screw-mounted slider potentiometer variant
    Introduces a new bottom-side screw-mounted THT slider potentiometer variant with associated KiCad files, images, and documentation. Also updates the existing THT slider potentiometer README to clarif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
    [component_potentiometer_slider_screw-mounted.kicad_pcb, component_potentiometer_slider_screw-mounted.kicad_sch]
2025-12-05 Update charge-pump inverter PCB and schematic
    Adjusted several PCB graphic line coordinates for improved layout accuracy. Added LCSC part number property to schematic. Included updated production ZIP for manufacturing.
    [component_charge-pump-inverter.kicad_pcb, component_charge-pump-inverter.kicad_sch]
2025-12-08 Added high power potentiometer, added 1x2 and 2x2 printable bases for new potentiometers and old parts
    [base_1x1_closed_self-tapping_0.15.step, base_1x1_closed_self-tapping_0.20.step, base_1x1_closed_self-tapping_0.25.step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]
2025-12-10 Update PCB layout and mounting hole positions
    Revised mounting hole locations and references, updated connector and resistor placements, and removed/re-added production zip file. These changes improve board layout consistency and mechanical fit.
    [whole_panel.kicad_pcb]
2025-12-10 Update resistor footprints and add THT 3W production files
    Replaced mounting hole footprints with SMD resistor footprints in the SMT E-6 series panel and updated net assignments. Added new KiCad PCB, project, and production ZIP files for the THT 3W E-6 series resistors. Updated connector reference and position in the SMT panel.
    [component_resistor_SMT_with-printed-value.kicad_pcb, component_resistor_SMT_with-printed-value.kicad_sch, component_resistor_THT_3W_with-printed-value.kicad_pc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]
2025-12-11 Update potentiometer PCB: net routing and clearance
    Added a new F.Cu segment for net 1, rerouted connections between pads, and increased clearance for R1-Pad4. Removed large '10kΩ' B.SilkS text and updated board region handling for improved net connectivity and maintainability.
    [component_potentiometer_high-power.kicad_pcb]
2025-12-11 Add SMT top-mount resistor puzzle piece
    Introduces a new SMT top-mount resistor module with schematic, PCB layout, documentation, and supporting files. Updates the main README to include this new puzzle piece in the component list.
    [component_resistor_SMT_top-mount.kicad_pcb, component_resistor_SMT_top-mount.kicad_sch]
2025-12-11 Update resistor value and PCB artwork to 10kΩ
    Changed the silkscreen text from '10Ω' to '10kΩ' and updated associated PCB artwork and mask color definitions. Modified polygon and text elements in the KiCad PCB file and replaced the TOP and BOTTOM PNG images to reflect the new value and design.
    [component_resistor_SMT_with-printed-value.kicad_pcb]
2025-12-18 Add ruggedized N-channel MOSFET puzzle piece
    Added new KiCad project for a ruggedized N-channel MOSFET component, including schematic, PCB layout, and supporting files. Also updated PCB-storage-system.FCStd binary.
    [PCB-storage-system.FCStd, component_mosfet_n-channel_ruggedized.kicad_pcb, component_mosfet_n-channel_ruggedized.kicad_sch]
2025-12-18 Add ruggedized N-channel MOSFET component files
    Added README, schematic, PCB, and image files for the ruggedized N-channel MOSFET puzzle piece. Updated PCB value field and removed autosave and lock files.
    [component_mosfet_n-channel_ruggedized.kicad_pcb, component_mosfet_n-channel_ruggedized.kicad_sch]
2026-02-21 Enable undefined_netclass DRC; add MOSFET ZIP
    Treat undefined_netclass as an error in the MOSFET component KiCad project by adding "undefined_netclass": "error" to the project settings. Add a production ZIP for puzzle-pieces/component_mosfet_n-channel_ruggedized containing the exported package. Also update the printable-bases/printable-base-Circuit-Nodes.FCStd binary (likely an updated printable base design).
    [printable-base-Circuit-Nodes.FCStd]
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2026-02-27 Fix formatting in index.md: Move circuit diagram above the educational tool description for improved clarity
2026-02-28 Updated github pages, included more images of parts, tolerance test pieces included
    [connector-size-tester.step, connector-size-tester.stl, printable-base-Circuit-Nodes.FCStd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]
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2026-03-03 structuring folder layout of puzzle pieces more uniformly, added ruggedized MLCC unpolar capacitor
    [component_capacitor-unpolarized-MLCC_SMT.kicad_pcb, component_capacitor-unpolarized-MLCC_SMT.kicad_sch]
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2026-03-28 Add tactile NO THT footprint and README
    Add a new 12x12mm through-hole tactile switch (Normally Open) footprint under puzzle-pieces/component_switch-tactile-Normally-Open_THT including .kicad_pcb, .kicad_sch, .kicad_pro, images, fp-lib-tab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
    [component_motor-with-propeller.kicad_pcb, component_switch-tactile-Normally-Open_THT.kicad_pcb, component_switch-tactile-Normally-Open_THT.kicad_sch]
2026-08-25 Add ruggedized LED lamp KiCad module
    Add a new KiCad component package for a ruggedized LED lamp replacement: PCB (.kicad_pcb), schematic (.kicad_sch), project file (.kicad_pro), footprint/symbol lib tables, round-tracks config, and top/bottom preview PNGs. Includes a README explaining the ruggedized LED usage as an E10 lamp replacement. Also add a Propeller-base.step model under component_motor-with-propeller.
    [Propeller-base.step, component_lamp-LED-module_ruggedized.kicad_pcb, component_lamp-LED-module_ruggedized.kicad_sch]
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2026-08-25 Refresh tactile switch PCB for KiCad 10
    Update the normally-open tactile switch THT piece to the latest KiCad format and project metadata, including PCB version, netlist changes, silkscreen/label adjustments, and edge-cut geometry updates.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
    [component_switch-tactile-Normally-Open_THT.kicad_pcb]
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2026-09-15 Adjust KiCad project metadata and update zip
    Remove empty "tuning_profile" field and change "meta.version" from 5 to 4 in puzzle-pieces/component_lamp-E10_screw-socket/component_lamp-E10_screw-socket.kicad_pro. Also replace the production ZIP at puzzle-pieces/component_lamp-E10_screw-socket/production/component_lamp-E10_screw-socket.zip (binary changed). These updates refresh project metadata and the packaged production artifact.
2026-09-15 Ignore KiCad history files
    Add *.history to .gitignore so generated KiCad history files are not tracked. This keeps local editor state and temporary artifacts out of version control and avoids noisy or accidental commits.
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2026-09-29 Update LED-module PCB and schematic layout
    Apply extensive layout and schematic updates for the ruggedized LED module: reposition footprints/text/pads, correct nets and pinfunction names, add unit declarations, remove placeholder Datasheet ~, adjust zone/polygon shapes and priorities, and remove some Edge.Cuts circles. Update schematic generator/version and many symbol properties (show_name, do_not_autoplace, in_pos_files, hide). Update .kicad_pro sheet UUID/name and add 0.75mm track width option. Numerous coordinate, uuid and silk/FP_line corrections to sync PCB and schematic placement.
    [component_lamp-LED-module_ruggedized.kicad_pcb, component_lamp-LED-module_ruggedized.kicad_sch]
2026-10-01 Add catalog rendering scripts and assets for KiCad PCB components
    - Introduced a new catalog rendering system for PCB components, including PowerShell scripts for rendering and publishing images.
    - Added configuration files (`style.json`, `kicad-viewer.json`) to define rendering parameters and settings.
    - Created a README.md to document usage instructions for the rendering process.
    - Implemented a .gitignore file to exclude temporary work files.
    - Updated multiple component images in the `puzzle-pieces` directory to reflect new designs.
    - Documented missing PCB sources for components that lack corresponding KiCad files.
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2026-10-07 Add symbol library table for polarized ruggedized replaceable capacitor
    [component_capacitor-polarized_ruggedized_replacable.kicad_pcb, component_capacitor-polarized_ruggedized_replacable.kicad_sch]
2026-10-07 Remove deprecated polarized THT replaceable capacitor component and update related documentation
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2026-10-13 Add symbol library table for LED replaceable component
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2026-11-03 Group transistor nodes and add low-profile socket models - Standardize transistor folder, file, and catalog naming. - Make the NPN BJT replaceable using a precision socket. - Use the Samtec low-profi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
